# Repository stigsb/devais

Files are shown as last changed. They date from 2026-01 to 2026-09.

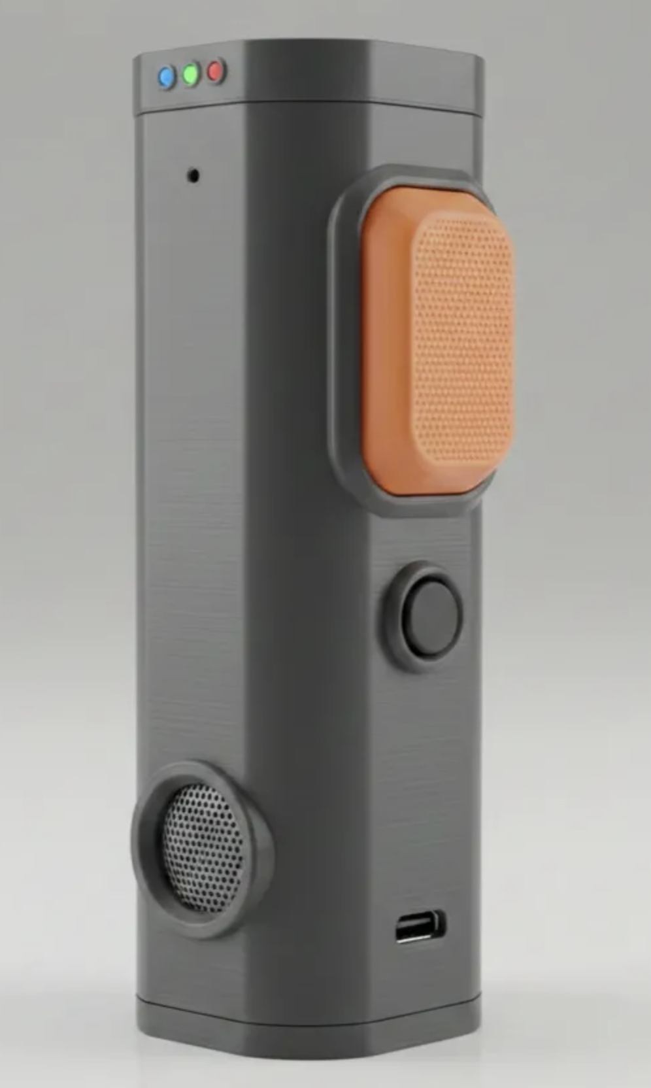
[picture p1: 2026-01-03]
context/proto-image.png

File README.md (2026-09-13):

# Devais - Handheld AI Assistant Device

A battery-powered, pocket-sized AI assistant with a push-to-talk interface. Designed as a walkie-talkie style device that solves the common problem of AI apps responding to hesitation during speech.

## Overview

**Form Factor:** Stick-shaped handheld device (~30x30x150mm)  
**Power:** 18650 battery with USB-C charging  
**Interface:** Push-to-talk button, status LEDs, speaker and microphone  
**Connectivity:** Bluetooth Low Energy (nRF52840)

## Hardware Components

### Core Controller
- **Seeed XIAO nRF52840** - Ultra-low power microcontroller with BLE
  - Superior battery efficiency vs ESP32 alternatives
  - 20.8 days idle battery life (vs 8.3 days for ESP32-C3)
  - 5 days continuous audio streaming (vs 27 hours for ESP32-C3)

### Audio System (I2S Bus Architecture)
- **INMP441** - MEMS I2S microphone
- **MAX98357A** - I2S Class D amplifier
- Compact speaker
- Shared clock signals with separate data lines for efficiency

### User Interface
- Tactile push-to-talk button
- Power/mode button
- Status LEDs (power, connectivity, activity)

### Power
- 18650 Li-ion battery
- USB-C charging port
- Efficient power management optimized for audio streaming

## Project Structure

```
devais/
├── cad/              # 3D CAD models (CadQuery scripts)
├── firmware/         # nRF52840 firmware
├── docs/             # Documentation, wiring diagrams
├── hardware/         # PCB designs, schematics
└── README.md
```

## Getting Started

### Prerequisites
- Python 3.14
- uv (Python package manager)
- Prusa MK3S or compatible 3D printer

### Installation

```bash
# Clone the repository
git clone https://github.com/stigsb/devais.git
cd devais

# Install dependencies with uv
uv sync

# Activate virtual environment
source .venv/bin/activate  # Linux/Mac
# or
.venv\Scripts\activate     # Windows
```

### Running CAD Scripts

```bash
# Generate the enclosure model
python cad/enclosure.py

# Output will be in cad/output/ as STL files
```

## Design Principles

1. **Intentional Interaction** - Push-to-talk prevents accidental triggers and hesitation issues
2. **Battery Efficiency** - Component selection optimized for multi-day battery life
3. **Pocket Portability** - Narrow form factor fits comfortably in pocket or hand
4. **Programmatic CAD** - Python-based modeling enables iterative design and parameter adjustment

## Status

- [x] Component selection and power analysis
- [x] I2S audio architecture design
- [x] Wiring diagram and pin assignments
- [ ] 3D enclosure design (in progress)
- [ ] PCB layout
- [ ] Firmware development
- [ ] Prototype assembly

## Location

Trondheim, Norway

## License

TBD

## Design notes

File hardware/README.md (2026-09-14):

# Devais Hardware Design

> The Python circuit-synth files below are historical circuit sketches.
> See [the electrical design](pcb/DESIGN.md) (revision 2, 2026-09-13) for the
> current circuit and [the parts list](BOM.md) for every part, lead and tool.
> [PROTOTYPE.md](PROTOTYPE.md) covers the stripboard bench build and the field
> unit on the XIAO nRF52840 Sense that precede the custom PCB.
> Neither these sketches nor the old tscircuit source are a fabrication-ready board.

Circuit definitions for Devais handheld AI assistant device using circuit-synth.

## Circuit Structure

The hardware design is modular, following software engineering best practices:

```
hardware/
├── devais.py              # Main circuit (composition of all subsystems)
├── power_management.py    # USB-C, battery, voltage regulation
├── audio.py              # I2S microphone and amplifier
├── user_interface.py     # Buttons and LEDs
└── README.md            # This file
```

## Components Overview

### Power System
- **USB-C connector** with 5.1k CC resistors (power sink configuration)
- **TP4056** Li-ion battery charger (1A charge current)
- **18650 battery** with protection
- **AMS1117-3.3** LDO regulator for 3.3V supply
- **Schottky diodes** for automatic USB/battery power selection

### Audio System (I2S Bus)
- **INMP441** MEMS I2S microphone
- **MAX98357A** Class D I2S amplifier (9dB gain for battery efficiency)
- **Speaker** (20-28mm diameter)
- Shared SCK and WS clock signals (efficient architecture)

### User Interface
- Push-to-talk button (with interrupt on P0.02)
- Power/mode button (with interrupt on P0.03)
- 2x **WS2812B-2020** addressable RGB LEDs (2x2mm package) on small PCB
  - Single data pin, daisy-chained
  - VDD switched via N-channel MOSFET to cut idle draw when LEDs are off

### Microcontroller
- **Seeed XIAO nRF52840** module
- BLE connectivity
- I2S peripheral for audio
- SWD programming interface (10-pin header)

## Pin Assignments (nRF52840)

| Function | Pin | Description |
|---|-----|---|
| **I2S Audio** | | |
| I2S SCK | P0.26 | Bit clock (shared mic/amp) |
| I2S WS | P0.27 | Word select (shared mic/amp) |
| I2S SDI | P0.28 | Serial data in (from mic) |
| I2S SDO | P0.29 | Serial data out (to amp) |
| **User Interface** | | |
| PTT Button | P0.02 | Push-to-talk (interrupt) |
| Power Button | P0.03 | Power/mode (interrupt) |
| LED Data | P0.06 | WS2812B-2020 data (2 LEDs daisy-chained) |
| LED Power | P0.07 | MOSFET gate for LED VDD cutoff |

## Generating KiCad Files

```bash
# From the hardware/ directory
cd /Users/stig/git/stigsb/devais/hardware

# Activate virtual environment
source ../.venv/bin/activate

# Generate KiCad project
python devais.py
```

This creates:
- `devais_v1/devais_v1.kicad_pro` - KiCad project file
- `devais_v1/devais_v1.kicad_sch` - Schematic file
- `devais_v1/devais_v1.kicad_pcb` - PCB layout file
- `devais_v1/devais_v1.net` - Netlist

## Opening in KiCad

```bash
open devais_v1/devais_v1.kicad_pro
```

## Making Changes

### Modify Circuit
1. Edit the Python files (`devais.py`, `audio.py`, etc.)
2. Run `python devais.py` to regenerate KiCad files
3. Circuit-synth will update component references in your Python source

### Modify PCB Layout
1. Open in KiCad and make changes to PCB layout
2. Changes to layout are preserved (not overwritten by circuit-synth)
3. If you change schematic in KiCad, you can import it back to Python

## Generating Manufacturing Files

```python
from devais import devais_main

circuit = devais_main()

# Generate BOM
circuit.generate_bom("devais_v1")

# Generate PDF schematic
circuit.generate_pdf_schematic("devais_v1")

# Generate Gerber files
circuit.generate_gerbers("devais_v1")
```

## Component Sourcing

Many components may need custom KiCad symbols/footprints. You can use circuit-synth's component search:

```bash
# Search for components
/find-parts "INMP441" --source jlcpcb
/find-parts "MAX98357A" --source jlcpcb
/find-symbol "nRF52840"

# Check JLCPCB availability
jlc-fast search "TP4056"
```

## Known Issues / TODOs

1. **Custom symbols needed:**
   - INMP441 microphone (might use generic breakout symbol)
   - MAX98357A amplifier (might use generic breakout symbol)
   - Seeed XIAO nRF52840 module (needs custom symbol)

2. **Footprint selection:**
   - Most footprints specified are standard
   - Audio module footprints may need adjustment for actual breakout boards

3. **Power management refinement:**
   - Consider load switch for power button control
   - Battery protection circuit details
   - USB-C ESD protection

4. **Audio tuning:**
   - Speaker impedance matching
   - Amplifier gain optimization
   - Acoustic design considerations

## Design Rationale

This circuit implements the design decisions documented in `../CLAUDE.md`:

- **Battery efficiency:** nRF52840 chosen over ESP32 for 2.5x better battery life
- **I2S audio:** Shared clock architecture reduces GPIO usage and improves efficiency
- **Modular design:** Each subsystem is independently testable and reusable
- **Version controlled:** All circuit changes tracked in git with meaningful diffs

## Next Steps

1. Generate KiCad project (`python devais.py`)
2. Verify component availability and adjust footprints
3. Create/import custom symbols for XIAO nRF52840, INMP441, MAX98357A
4. PCB layout (considering 30x30mm target size)
5. Review with electrical rules check (ERC)
6. Order prototype PCB and components
7. Assembly and testing

## Questions?

See the main project README and CLAUDE.md for project context and design philosophy.

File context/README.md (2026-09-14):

# Context Files for AI Agents

## Index

Full assembly prototype: see `cad/ASSEMBLY.md` for the PCB, components, harnesses,
mounting pieces and fit checks. Its exports are in `output/full-assembly/`.

Latest enclosure revision (2026-09-11): diagonal pin/socket joint and chassis mounts;
see `output/README.md`. `context/enclosure-spec.md` marks its older content as
historical; `context/enclosure-work.md` was rewritten to the current state. Root
`output/` is the current export destination.

**When working on this project, read these files in `context/` for technical details:**

**Additional Documentation:** The `docs/` folder contains supplementary documentation.

### `context/enclosure-spec.md`
**Read when:** Implementing or modifying the DevAIs enclosure design.

**Contains:**
- Reference image analysis with precise dimensions and component positions
- Complete implementation plan with step-by-step changes required
- Octagon geometry calculations and battery fit verification
- CadQuery coordinate system guidelines and workplane selection rules
- Component orientation details (USB-C, buttons, LEDs, microphone, speaker)

### `context/enclosure-work.md`
**Read when:** Resuming work on the enclosure or checking its current parameters.

**Contains:**
- Octagon geometry and the seam position
- Every opening with its size and position, and the internal mount envelopes
- Commands to generate and preview, and what the generator checks
- Outstanding work
- CadQuery techniques the model depends on, and the decisions behind them

### `context/software-decisions.md`
**Read when:** Implementing firmware, the phone companion, or the BLE
transport, or checking which prototype microphone option is in use.

**Contains:**
- Firmware framework and host platform decisions
- The staged BLE transport and codec plan, with the options rejected and why
- The throughput and link-budget constraints and estimates behind that plan
- The prototype microphone decision

## Index Updates

This file must be updated when `context/*.md` files are added, modified or deleted.

Entries should follow this template:

```markdown
### `context/lowercased-name.md`
**Read when:** (single sentence describing when to read)

**Contains:**
- Short list of the
- kinds of information
- the file contains
```

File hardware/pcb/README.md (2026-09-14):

# Devais Main PCB

> **Current design (2026-09-13, revision 2):** see [DESIGN.md](DESIGN.md) for the
> 26 × 126 mm chassis-mounted board, castellated radio module, and JST-connected
> peripherals, and [../BOM.md](../BOM.md) for the parts list. `design.py` checks
> the mechanical allocations. The electrical
> source below remains an older, incompatible sketch with placeholder footprints
> and known circuit errors. It is not suitable for manufacture. The historical
> dimensions and component descriptions below do not describe the new proposal.

Custom PCB for the Devais handheld AI assistant, designed with [tscircuit](https://tscircuit.com/) (React/TypeScript).

## Board Specifications

- **Dimensions:** 28 x 72mm (2-layer, all components top-side)
- **Width constraint:** 28mm max inscribed square inside the 35mm interior octagonal enclosure
- **Height:** 72mm, sits above the 18650 battery (65mm) in the 150mm tall enclosure
- **Mounting:** 4x M2 holes at corners

## Architecture

The design splits functionality across multiple small boards connected by JST cables. This keeps the USB-C board cheap and replaceable (it takes mechanical stress from cable insertion), and puts the LED board where it needs to be physically (near the top of the enclosure, away from the main PCB).

### Main PCB (this board)

All processing, power management, and audio amplification.

| Ref | Component | Package | Function |
|-----|---|---|---|
| U_MCU | Seeed XIAO nRF52840 | DIP14 castellated | BLE microcontroller |
| U_AMP | MAX98357A | QFN-16 (3x3mm) | I2S Class D amplifier |
| U_REG | AMS1117-3.3 | SOT-223 | 3.3V LDO regulator |
| U_CHG | TP4056 | SOIC-8 | Li-ion battery charger (1A) |
| Q1 | 2N7002 | SOT-23 | N-ch MOSFET, LED VDD switch |
| SW_PTT | Tactile switch | 6x6mm | Push-to-talk button |
| SW_PWR | Tactile switch | 6x6mm | Power/mode button |

### External Boards (JST cables)

| Connector | Pins | Connects To |
|---|---|---|
| J_USB | 2 (VBUS, GND) | USB-C charging board |
| J_BAT | 2 (VBAT, GND) | 18650 battery holder |
| J_SPK | 2 (OUT+, OUT-) | Speaker (differential from MAX98357A) |
| J_LED | 3 (VDD_LED, GND, DATA) | WS2812B-2020 daughter PCB (2 LEDs) |
| J_MIC | 5 (VCC, GND, WS, SCK, SD) | INMP441 breakout board |

### USB-C Board (separate, replaceable)

Intentionally minimal: USB-C receptacle + 2x 5.1k CC resistors. No ICs. Designed to be cheap to replace when the connector wears out or breaks from mechanical stress.

## Pin Mapping (nRF52840 via XIAO)

| XIAO Pin | nRF52840 | Signal | Description |
|---|---|---|---|
| D2 | P0.28 | I2S_SDI | Mic data → MCU |
| D3 | P0.29 | I2S_SDO | MCU → amp data |
| D4 | P0.02 | BTN_PTT | Push-to-talk (interrupt) |
| D5 | P0.03 | BTN_PWR | Power/mode (interrupt) |
| D6 | P0.26 | I2S_SCK | Shared bit clock |
| D7 | P0.27 | I2S_WS | Shared word select |
| D8 | P0.06 | LED_DATA | WS2812B data (daisy-chained) |
| D9 | P0.07 | LED_EN | MOSFET gate for LED VDD |

## PCB Layout (top to bottom)

```
Y=+33  ┌─ J_SPK (speaker)  J_LED (LEDs) ─┐
Y=+29  │  Q1 (MOSFET)      R_GATE         │
Y=+18  │         U_MCU (XIAO)             │
Y= +4  │  J_MIC (mic)      U_AMP (amp)    │
Y= -7  │       SW_PTT (push-to-talk)      │
Y=-16  │       SW_PWR (power/mode)        │
Y=-24  │         U_REG (3.3V LDO)         │
Y=-31  │  R_PROG  C_USB    U_CHG (charger)│
Y=-35  └─ J_USB (USB pwr)  J_BAT (battery)┘
```

## Build Commands

```bash
uv run pcb-build          # Validate circuit (runs tsci build)
uv run pcb-export         # Build + export SVG/schematic/assembly/netlist
```

Or directly with tsci:

```bash
cd hardware/pcb
tsci build                             # Validate
tsci export index.circuit.tsx -f pcb-svg        # PCB layout
tsci export index.circuit.tsx -f schematic-svg  # Schematic
tsci export index.circuit.tsx -f assembly-svg   # Assembly drawing
tsci dev                               # Interactive preview
```

Assembly diagram with accurate pad outlines:

```bash
uv run python3 hardware/pcb/generate_assembly.py
open hardware/pcb/assembly-top.png
```

## Design Decisions and Lessons Learned

### Tool Selection

We evaluated several PCB design tools for AI coding agent workflows:

| Tool | Verdict | Why |
|---|---|-----|
| **circuit-synth** | Rejected | Requires KiCad installed for symbol libraries |
| **pcbflow** | Rejected | Alpha quality, not on PyPI, limited footprints, no schematic |
| **tscircuit** | Selected | Declarative JSX, built-in autorouter, JLCPCB search, no external deps |

**Key insight:** tscircuit's declarative React/JSX approach is far better for AI-driven iteration than imperative Python turtle routing. `tsci build` gives instant headless validation.

### Board Sizing

The board width (28mm) is fixed by the enclosure geometry: it's the maximum inscribed square inside the 35mm flat-to-flat interior octagon. We calculate this from the octagon's chamfer line: `x + y ≤ 28.4mm`, so a square board maxes out at 28mm.

The height evolved through iteration:
- 28mm (square): too dense, autorouter failed
- 55mm: courtyard overlaps in power section
- 90mm: too much empty space
- **72mm: good balance** — compact but every component has clearance

### Courtyard Overlaps

**Never ignore courtyard overlap warnings.** They mean components physically can't be soldered in those positions. Even if pads don't technically overlap, courtyard violations indicate insufficient clearance for:
- Soldering iron access
- Pick-and-place machine tolerances
- Rework and inspection

The DIP14 footprint for the XIAO nRF52840 is surprisingly large (7.6 x 15.2mm). This was the most common source of courtyard violations — components placed "above" or "below" the MCU would overlap its tall pad span.

### Autorouter Selection

- `auto` (capacity-mesh): fails on dense boards ("ran out of iterations")
- `auto-cloud`: requires tscircuit authentication, hung indefinitely
- **`sequential-trace`**: works reliably even on dense boards

### Component Placement Strategy

1. **Know your footprint sizes.** DIP14 is 15mm tall. SOT-223 is 6.3mm wide. SOIC-16 is 9mm tall. You need these numbers to calculate safe placement gaps.
2. **Verify with `tsci build` after every position change.** Don't batch up changes — you'll lose track of which move caused the overlap.
3. **Place largest components first** (MCU, then connectors, then ICs, then passives).
4. **Keep decoupling caps near their IC** but not so close that courtyards overlap. 3-4mm center-to-center is usually safe for 0603/0805 next to SOT-23 or larger.

### Modular Board Architecture

Splitting into main board + daughter boards was driven by practical concerns:
- **USB-C board:** Mechanical stress from cable insertion will eventually break the connector. A separate $0.50 board with just the connector + CC resistors is disposable.
- **LED board:** The WS2812B LEDs need to be physically at the top of the enclosure (behind the LED holes), far from where the main PCB sits. A 3-wire JST cable solves this.
- **Mic breakout:** INMP441 is a bottom-port MEMS mic requiring an acoustic path through the enclosure wall. Easier to position independently on a breakout board.

### LED VDD Switching

The N-channel MOSFET (2N7002) switches LED ground, not VDD. This is simpler than a high-side P-channel switch:
- Gate driven directly from 3.3V GPIO (D9)
- 10k pull-down resistor keeps LEDs off during MCU boot/reset
- WS2812B idle current (~1mA per LED) is eliminated when MOSFET is off

### JLCPCB Part Numbers

All ICs and passives have JLCPCB `supplierPartNumbers` for direct ordering. Use `tsci search --jlcpcb "<query>"` to verify stock before ordering.

## File Structure

```
hardware/pcb/
├── index.circuit.tsx       # Main circuit definition (source of truth)
├── generate_assembly.py    # Assembly diagram generator (reads circuit.json)
├── assembly-top.svg/.png   # Generated assembly drawing
├── index.circuit-pcb.svg   # Generated PCB layout
├── index.circuit-schematic.svg
├── index.circuit-assembly.svg
├── dist/index/circuit.json # Build output (component positions, nets, pads)
├── package.json            # tscircuit project config
├── tsconfig.json
├── tscircuit.config.json
└── README.md               # This file
```

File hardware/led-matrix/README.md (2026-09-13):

# LED matrix daughterboard

**Status: deferred to V2.** V1 ships the existing two 3 mm LED openings. Nothing
here is on the V1 build path.

A higher-fidelity replacement for the 2x WS2812B-2020 indicator board, for
signalling the state of several concurrent agents. Background, part selection,
cost and the rejected alternatives are in
[`docs/led-indicator-research-2026-09-13.md`](../../docs/led-indicator-research-2026-09-13.md).

## upstream/

Third-party KiCad 7 design, taken as a starting point — not a devais board.

- Source: Arduino Forum, "Showcase: PCB for 8x8 matrix of WB2812B-2020"
  <https://forum.arduino.cc/t/showcase-pcb-for-8x8-matrix-of-wb2812b-2020/1154180>
- Licence: not stated by the author. Resolve before publishing a derived board.
- As drawn: 25.0 x 25.0 mm, 2 layers, 8x8 on a 3.0 mm pitch (21 mm LED field),
  64x `MR_LED:WS2812B2020`, 2x `MR_Connect:DS1024-1x3R0` 3-pin daisy-chain
  connectors, no decoupling capacitors.

## Required changes for devais

- **LED part:** WS2812B-2020-V6 (LCSC C52917434), not the V1.3 part the upstream
  footprint was drawn for. V6 is spec'd 3.3-5.3 V and <=1 uA idle, so it runs
  directly off the 18650 with no boost and needs no power gate. Verify the V6
  recommended land pattern against the upstream footprint before reuse.
- **Connector:** one 3-pin JST matching the existing J_LED cable (VDD_LED, GND,
  LED_DATA), replacing both DS1024 daisy-chain connectors.
- **Decoupling:** upstream has none. Add local capacitors.
- **Outline:** 25 mm is the enclosure's hard limit at the front flat face
  (`LONG_SIDE_LENGTH` ~= 24.9 mm). Shrinking the pitch to 2.5 mm gives a 20 mm
  field and working margin.

## Open questions

- Front-face split: the enclosure parts at X = 0 and the current LED openings sit
  entirely on the chassis half. A centred 25 mm board crosses the joint.
- Diffusion: at 2.5-3.0 mm pitch behind the 1.6 mm wall, per-pixel separation
  needs a grid insert. A plain window blends adjacent pixels into a blur.
- Brightness cap: 64 LEDs at full white is ~2.3 A. Firmware must limit global
  brightness.

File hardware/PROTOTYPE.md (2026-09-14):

# Devais prototype builds — 13 September 2026

Two builds precede the custom PCB in [`pcb/DESIGN.md`](pcb/DESIGN.md):

1. **Bench prototype**: stripboard, breakout modules, no enclosure. Proves
   push-to-talk capture, BLE transfer to the phone, playback, LEDs and idle
   current.
2. **Field unit**: the same electronics on a stripboard carrier inside the
   printed chassis. Cell replaced by opening the cover. No charging port and
   no power button are required; the PTT button, speaker, microphone and
   LEDs must work.

The custom PCB design is unchanged by either build and stays the plan for the
25-unit run. Pin names below are XIAO silkscreen names; nRF port numbers, peripheral
pins and module dimensions were verified against the Seeed wiki, schematic
and Arduino variant files on 2026-09-13
(`docs/research/2026-09-13-xiao-sense.md`).

## Parts for the bench prototype

| Item | Part | Qty | Source | Note |
|---|---|---|---|---|
| Controller | Seeed XIAO nRF52840 Sense | 1 (+1) | digikey.no kr 185 incl. VAT, 1,300 in stock; no Norwegian shop stocks it | USB-C, UF2 bootloader preinstalled, 3.3 V regulator, 100 mA charger, PDM microphone and IMU on board |
| Amplifier | MAX98357A I2S breakout (Adafruit 3006 or generic clone) | 1 | Adafruit, DigiKey, AliExpress | Pins VIN, GND, SD, GAIN, DIN, BCLK, LRC, speaker terminals |
| Speaker | Same Sky CMS-2053-18SP, 20 mm, 8 Ω, 1.5 W | 1 | DigiKey 22521372 | Any 8 Ω speaker works on the bench |
| Cell | Protected 18650 (any brand, 67–70 mm) | 1 | batterionline.no | Protected cell replaces the DW01A circuit. The unprotected 35E is for the PCB build |
| Cell holder | 18650 holder with wire leads | 1 | DigiKey (Keystone 1043, 36-1043-ND, PCB pins; or a leaded holder) | Kjell and Clas Ohlson stock no single-cell 18650 holder |
| Switches | Omron B3F-1000 or any 6 × 6 or 12 × 12 tactile switch | 2 | LCSC C93157, DigiKey | PTT and reset |
| LEDs | 3 mm common-anode RGB LED, diffused | 1 | DigiKey | Plus the XIAO's on-board RGB LED as the second indicator |
| Resistors | 1 kΩ (red), 560 Ω (green, blue), 10 kΩ (pull-up) | 3 + 1 | any | 1/4 W through-hole |
| Capacitors | 100 nF ceramic, 100 µF electrolytic | 1 + 1 | any | Button filter; amplifier supply bulk |
| Stripboard | 0.1 in pitch, at least 25 × 140 mm usable | 1 | DigiKey, Mouser, Farnell | Strips run across the short axis; see cutting rules |
| Headers | 2.54 mm male pin headers, 7-pin × 2 for the XIAO; female headers for the amp if it is to be removable | | DigiKey | |
| Wire | 0.25 mm² (24 AWG) stranded, red and black for power; 0.14 mm² (26 AWG) for signals | | DigiKey, Farnell | |
| Tools | 0.6 mm chisel-tip iron, side cutters, 3 mm drill or strip cutter for cutting strips, multimeter | | | |

## Bench wiring

Power: cell + to the XIAO's BAT+ pad on the underside, cell − to BAT−. The
XIAO's 3V3 pin supplies the LEDs and the PTT pull-up. The amplifier VIN
takes the cell voltage from the holder leads, not 3V3, with the 100 µF
capacitor across VIN and GND at the amplifier. A grounded USB cable into
the XIAO charges the cell at 100 mA (over 30 hours for 3350 mAh) and gives
USB DFU and serial. The XIAO's HICHG pin selects 100 mA when driven low.

| XIAO pin | nRF port | Signal | Connection |
|---|---|---|---|
| D0 | P0.02 | BTN_PTT | Switch to GND; 10 kΩ to 3V3; 100 nF to GND |
| D1 | P0.03 | LED_R | 1 kΩ to the RGB LED red cathode |
| D2 | P0.28 | LED_G | 560 Ω to green cathode |
| D3 | P0.29 | LED_B | 560 Ω to blue cathode; LED anode to 3V3 |
| D4 | P0.04 | I2S_BCLK | Amplifier BCLK (about 1 MHz; D4 and D5 are the only full-speed pads) |
| D5 | P0.05 | I2S_DIN | Amplifier DIN |
| D6 | P1.11 | spare (PDM_CLK in field option M2) | |
| D7 | P1.12 | spare (PDM_DATA in field option M2) | |
| D8 | P1.13 | I2S_LRCLK | Amplifier LRC, 16 kHz |
| D9 | P1.14 | AMP_SD | Amplifier SD pin through 100 kΩ (mono mix window); low = shutdown |
| D10 | P1.15 | spare | |
| RST (underside pad) | | Reset switch | Second switch to GND; double-tap enters the UF2 bootloader |
| BAT+, BAT− (underside pads) | | Cell | Through the holder leads |
| on-board mic MSM261D3526H1CPM | CLK P1.00, DATA P0.16, power P1.10 | PDM capture | No wiring |
| on-board RGB LED | red P0.26, green P0.30, blue P0.06, common anode to 3V3, active low | Second indicator | No wiring |
| HICHG | P0.13 | Charge current | Drive low for 100 mA; floating gives 50 mA |
| VBAT sense | P0.31 / AIN7, divider enabled by P0.14 low | Cell voltage | Keep P0.14 low only while sampling |

The amplifier GAIN pin is left open for 9 dB. Nine of the eleven exposed
pins are Nordic "low frequency" pads (D0–D3, D6–D10); only D4 and D5 are
full-speed, so they carry the bit clock and data. Seeed's own SPI runs on
D8–D10 at several MHz, so a 16 kHz LRCLK on D8 is not a concern. The custom
PCB uses full-speed pads throughout.

Stripboard rules: the XIAO is 20.96 × 17.78 mm, 4.46 mm thick with its USB-C
receptacle, which overhangs the board edge by 1.5 mm. Its two pin rows are
17.78 mm apart on 2.54 mm pitch and lie on the same strips, so cut every
strip between the rows under the module. Mount the
XIAO on male headers so the underside pads (BAT+, BAT−, RST, SWD) are
reachable: solder the cell and reset leads to those pads before fitting the
headers. Keep the speaker pair twisted and away from the cell leads.

## Firmware for the prototype

- Bootloader: the factory Adafruit UF2 bootloader (board `Seeed XIAO nRF52840
  Sense`). USB DFU by double-tap reset or the 1200-baud touch. No SWD needed.
- Framework: nRF Connect SDK (Zephyr) with the `xiao_ble/nrf52840/sense`
  board, which has the PDM mic and I2S drivers; or the Seeed Arduino core
  with the `PDM` and `I2S` libraries for a faster start. Pick one and keep
  it for the custom board, which will need its own board definition.
- Audio: 16 kHz mono capture from PDM, transfer over BLE (a GATT
  characteristic with notifications, or NUS), playback over I2S at the same
  rate with the sample duplicated into both slots.
- Sleep: System OFF with PTT wake, amplifier SD low, PDM clock stopped.
  Measure the cell current with the LEDs off; this number decides whether
  the product needs the power button at all.

## Field unit

The bench electronics move onto a 25.4 × 135 × 1.6 mm stripboard cut to the
main-board outline, screwed to the existing rails with the existing six M2
positions (drill the stripboard to match `stripboard_template.step`). Beside
the cell the carrier may carry only flat parts (3 mm limit): wires, resistors
lying flat, the capacitors laid down. Modules sit above the cell:

| Part | Position | Mounting |
|---|---|---|
| XIAO nRF52840 Sense | Top of the carrier, Z 125.8–146.8, USB-C mouth at the top end wall; the chip antenna and the on-board mic are at the opposite (lower) end on the top face | Soldered flat by its castellations at Z 125.8–146.8; USB-C through a 7.5 × 13 mm opening in the top wall; BAT+/BAT− leads soldered from behind through an 8 × 12 mm stripboard window |
| MAX98357A breakout | Above the cell, Z 92–111.4 | Z 92–111.4 on one 7-pin header row at Y = 6.1, header pins clipped to 1.5 mm behind the board |
| Speaker | Existing cup, existing bridge | Unchanged |
| PTT switch | Existing carrier at Z = 105 | Unchanged; the lead is routed behind the amplifier pins at X 15. The PTT tunnel leaves only a 0.14 mm skin on the PCB rail's back face, which will not print, so the lead lies in a groove open toward the wall with a 2.1 mm gap. |
| Reset switch | Existing power-button carrier at Z = 44 | Not fitted; the power carrier and cap stay as blanks |
| RGB LED | Through both existing 3.2 mm holes at Z = 140, leads soldered to a 5-wire lead | One RGB LED and one single-colour LED on D10 on the product LED board, 5-wire lead |
| Cell | Existing cradle, Keystone contacts, straps | Cover off to swap; the straps hold it |
| USB-C side opening | Not cut in the field chassis | None needed |

Microphone: M2, an Adafruit 3492 PDM breakout (14.0 × 12.8 × 2.8 mm) in the
enlarged bottom-front seat, MP34DT01 port toward the wall, wired to D6/D7.
Decided 2026-09-14.

The field variant is built with `--variant field` in `cad/enclosure.py` and
`cad/assembly.py`; see `cad/ASSEMBLY.md`.

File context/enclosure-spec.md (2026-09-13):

> Update 2026-09-11: The implementation now uses an offset diagonal split
> (X−Y = −4), locating pins with blind sockets, screw closure, and chassis-only
> component supports. Generated files are in root `output/`. See
> `output/README.md` for dimensions, checks and unfinished hardware details.
> Historical completion claims and X=0 joint descriptions below are superseded.

# 1. Reference Image Analysis - DevAIs Enclosure

## 1.1. Overall Form ✅ REVIEWED

### 1.1.1. Cross-Section (Octagonal Prism)
- **NOT cylindrical** - octagonal cross-section
- **Dimensions:** 40mm across × 150mm tall
- **Octagon structure:**
  - Formed like a **square with chamfered/beveled corners at 45°**
  - 4 longer sides (the main square faces)
  - 4 shorter sides (the 45° chamfers at each corner)
  - Ratio between longer sides and shorter sides/chamfers is 7:3
  - Alternating pattern: long side → short chamfer → long side → short chamfer...
  - Each beveled corner is **slightly rounded** (4mm diameter)

### 1.1.2. Vertical Profile
- **Height:** 150mm
- **Top edge:** rounded/filleted (4mm diameter)
- **Bottom edge:** rounded/filleted (4mm diameter)

### 1.1.3. Visual Effect
- Basically a **square stick with softened/chamfered corners**
- The 45° chamfers make it more comfortable to hold than a pure square
- The rounded edges add to the ergonomic feel

### 1.1.4. Colour
- The main body is industrial grey

### 1.1.5. Thickness
- 1.6mm thickness - practical for following USB-C port spec

---

## 1.2. Components and Features ✅ REVIEWED

### 1.2.1. Names / Designations ✅ REVIEWED
- **Orientation:**
  - The enclosure runs length-wise along the Y axis.
  - The front/back sides are separated along the Z axis.
  - The left/right sides are separated along the X axis.
- **Front:**
  - One of the long sides is designated as the "front" side.
  - The "right" side is the long side to the right of the "front" side when camera points
    perpendicularly at the front side.

### 1.2.2. Top Section of Front Side ✅ REVIEWED

#### 1.2.2.1. Two RGB LEDs
  - 2x WS2812B-2020 addressable RGB LEDs (2x2mm package) on small PCB
  - On front side, 10mm from the top
  - 3mm holes for light diffusion
  - Positions: x=+5mm and x=+11mm (both on right/chassis half)
  - Single data pin, daisy-chained; VDD switched via MOSFET for idle power savings

#### 1.2.2.2. Microphone Hole and Support

Microphone is a INMP441. It should be centered 10mm from the bottom of the front side, behind a 1.5mm acoustic hole.
There needs to be support structure behind the hole, as described in the following technical details the INMP441:

<part_description>
 <part>INMP441</part>
 <type>high-performance, low power, digital-output, omnidirectional MEMS microphone with a bottom port</type>
 <dimensions>
  Overall Size:
  - Length: 4.72mm
  - Width: 3.76mm
  - Height: 1.00mm (0.88-1.05mm tolerance)
 </dimensions>
 <acoustic_port>
  At bottom of the part.
  - Port diameter: 0.25mm (at microphone)
  - Recommended PCB hole: 0.5-1.0mm diameter
  - Port location: Centered on bottom of package
  - Inner ring diameter: 0.96mm
  - Outer ring diameter: 1.56mm
 </acoustic_port>

 <support_structure_design_requirements>
  1. Mounting Footprint:
     - Create a 4.72mm × 3.76mm pocket or platform
     - Consider adding ~0.2mm clearance for 3D print tolerances
  2. Acoustic Port Opening:
     - Must have a through-hole of at least 0.5-1.0mm diameter aligned with the mic center
     - The sound port MUST NOT be blocked - this is critical for functionality
     - Position this hole at the center of the 4.72mm × 3.76mm footprint
  3. Pin Locations (9 pins total):
     - 8 rectangular pads (0.40mm × 0.60mm) around perimeter
     - Spacing: 1.05mm between pins on short sides, 2.66mm on long sides
     - Pin 1 is at the reference corner (see page 19, Figure 16)
  4. Clearance:
     - Leave space below for the acoustic path
     - No obstructions within ~2mm radius of the bottom port
     - Consider ventilation/acoustic chamber design
 </support_structure_design_requirements>
 <design_note>
  The INMP441 is a bottom-ported mic, so your enclosure needs an acoustic path from the outside environment to the bottom of the microphone. The support structure should securely hold the breakout board while ensuring the sound port remains completely unobstructed.
 </design_note>
<part_description>

### 1.2.3. Large Orange Button ✅ REVIEWED
- **Purpose:** This is the press-to-talk button
- **Location:** Upper part of right side of device (from viewing angle), placed 15%-45% of the total height relative to the top (centered at 105mm from bottom)
- **Height:** 30% of enclosure height (45mm)
- **Width:** Same as the width of a long side (~24.9mm)
- **Shape:** Multi-section design with rounded corners:
  - **Base section:** 4mm flat depth without bevel
  - **Beveled section:** 4mm depth with 45° bevel/taper on all four sides
  - **Corner rounding:** Transitions from 8mm radius at the top of the base section to proportionally scaled radius (~5.4mm) at the top of the button, maintaining consistent proportions
- **Texture:** Top surface has a dotted pattern (raised bumps) providing extra friction but still feeling comfortable
  - Bumps are filtered to exclude corners where surface rounding removed their support
  - Only bumps within the rounded rectangle boundary are included
- **Opening in enclosure:** The opening for the button has rounded corners with 8.5mm radius (matching the 8mm button corner radius plus 0.5mm clearance)
  - Opening is cut through the wall from outer surface inward
- **Raised edge on body around button:**
  - **Frame width:** 1.6mm (same as wall thickness)
  - **Height:** 3.2mm (2× wall thickness), extending from inner surface outward
  - **Protrusion:** Extends 1.6mm beyond the outer surface of the enclosure
  - **Inner dimensions:** Match the opening size exactly (8.5mm corner radius)
  - **Rounding:** 0.3mm fillet on outer edges for smooth transition
  - **Alignment:** Positioned to naturally meet the 45° chamfer surfaces
- **Color:** Orange

### 1.2.4. Power Button ✅ REVIEWED
- **Location:** Lower part of right side, 44mm from the bottom
- **Color:** Black
- **Design:** Concentric ring design - has a raised outer ring to prevent accidental power-off
- **Diameter:** 8mm

### 1.2.5. Speaker Grille ✅ REVIEWED
- **Location:** Upper part of front face
- **Shape:** Circular
- **Pattern:** Mesh/perforated with many small holes
- **Color:** Dark gray/black
- **Diameter:** 80% of the long side width
- **Position:** Upper edge of speaker grille should be 10mm below the horizontal line with LEDs

### 1.2.6. USB-C Port ✅ REVIEWED
- **Location:** Lower part of right side, 31mm from the bottom
- **Shape:** Stadium-shaped (rounded rectangle) through-hole with a width of 9.5mm, a height of 3.7mm, and a corner radius of 1.6mm
- **Size:** 9.5mm width × 3.7mm height (standard USB-C dimensions)
- **Orientation:** Flat side (9.5mm width) oriented front-to-back (facing toward/away from power button)
- **Surface thickness:** Ensure the enclosure wall thickness at the point of the cutout is exactly 1.6mm. If the rest of the enclosure is thicker (e.g., 3mm), create a recessed pocket on the exterior or interior so the effective thickness at the port is reduced to 1.6mm."

---

## 1.3. File Output ✅ REVIEWED
- **Output Directory:** All generated STL and STEP files must be written to the `cad/output/` directory.
- **Directory Creation:** The script should automatically ensure this directory exists before exporting.
- **Gitignore:** This directory is gitignored to avoid tracking large binary model files.

---

# 2. Implementation Plan

## 2.1. Critical Changes Required

### 2.1.1. Fundamental Shape Change: Cylinder → Octagonal Prism
**Current:** Code creates a hollow cylinder using `cq.Workplane("XY").circle()`
**Required:** Create octagonal prism with 7:3 ratio for long:short sides

**Implementation approach:**
1. Calculate octagon dimensions from 40mm width
2. Create octagon profile using `.polygon()` or explicit point coordinates
3. Apply small fillets to each edge where sides meet
4. Extrude to 150mm height
5. Add fillets to top and bottom edges
6. Hollow out the interior

**Octagon geometry calculations:**
- 40mm across (corner to opposite corner? or flat to flat?)
- 7:3 ratio means if long side = 7 units, short chamfer = 3 units
- Need to verify: is 40mm the flat-to-flat or point-to-point measurement?

### 2.1.2. Dimension Corrections
**Current:** 55mm × 55mm × 150mm
**Required:** 40mm × 40mm × 150mm octagonal prism

### 2.1.3. Coordinate System Alignment
**Required:**
- Y axis: length (150mm)
- Z axis: front/back separation
- X axis: left/right separation

**Current code:** Uses Z for height, XY for cross-section
**Action:** May need to rotate final model or reorient coordinate system in code

### 2.1.4. Component Repositioning

| Component | Current Position | Required Position | Change Needed |
|---|---|---|---|
| LEDs (3x 3mm) | Not implemented (commented out) | Front side, 10mm from top, 8mm spacing | Add function |
| Mic (INMP441) | Front, 92% height (~138mm) | Front, 10mm from bottom | Move to bottom + add mounting structure |
| Speaker Grille | Front, 28% (~42mm) | Front, upper part, 10mm below LEDs | Move to top |
| Power Button | Front, 40% (~60mm) | RIGHT side, 44mm from bottom | Change side + reposition |
| USB-C Port | Bottom/front, 5mm | RIGHT side, 31mm from bottom | Change side + reposition |
| Large Button | Right side, 60% (~90mm) | RIGHT side, centered, 30% height (45mm tall) | Adjust height and add bevel |

### 2.1.5. Large Button Redesign
**Current:** Simple rounded rectangle with dimple texture
**Required:**
- Full width of long side (~28mm based on 7:3 ratio)
- 30% of device height = 45mm tall
- 45° bevel/taper (base larger than top surface)
- 4mm protrusion from body surface
- 2mm raised edge on body around button (quarter-circle profile, 0.25mm gap)
- Dotted texture on top surface

### 2.1.6. Power Button Design
**Current:** Simple circular cutout
**Required:**
- 8mm diameter
- Concentric ring design with raised outer ring
- Black color (material/print consideration)
- On RIGHT side, 25mm from bottom

### 2.1.7. INMP441 Microphone Mounting
**Required:** Add internal support structure:
- 4.72mm × 3.76mm mounting footprint
- 1.5mm acoustic hole centered on front face, 10mm from bottom
- 0.5-1.0mm through-hole for acoustic port
- No obstructions within 2mm radius of port
- Acoustic chamber design

### 2.1.8. Speaker Grille Repositioning
**Current:** Lower portion, 28% height
**Required:** Upper portion of front face
- Diameter: 80% of long side width (~22.4mm if long side is 28mm)
- Position: Upper edge 10mm below LED line (LED line is 10mm from top)
- So grille upper edge at 20mm from top

### 2.1.9. LED Holes
**Current:** Function exists but not called
**Required:** Re-enable and position correctly
- Front side, 10mm from top
- 3mm LEDs
- 8mm spacing between centers
- Centered horizontally on front face

## 2.2. Implementation Steps

### 2.2.1. Step 1: Calculate Octagon Geometry
- Determine if 40mm is flat-to-flat or corner-to-corner
- Calculate long side and short chamfer lengths with 7:3 ratio
- Calculate corner positions for octagon profile

### 2.2.2. Step 2: Rewrite `create_basic_enclosure()`
- Replace cylinder with octagonal prism
- Maintain top/bottom edge fillets
- Maintain interior hollowing with appropriate wall thickness

### 2.2.3. Step 3: Update Design Parameters
- Change DEVICE_WIDTH/DEPTH to reflect 40mm octagon
- Calculate long side width for component sizing
- Update all component positions to match reference

### 2.2.4. Step 4: Rewrite Component Functions
- `add_led_holes()`: Position on front, 10mm from top
- `add_mic_hole()`: Move to front bottom, 10mm from bottom, add mounting structure
- `add_speaker_grille()`: Reposition to front top, resize to 80% of long side
- `add_button_cutout()`: Rename to `add_power_button()`, move to right side
- `add_usbc_port()`: Move to right side, 12mm from bottom

### 2.2.5. Step 5: Redesign Large Button
- Add 45° taper/bevel
- Resize to full width of long side × 45mm height
- Add 2mm raised edge feature on body
- Update texture pattern

### 2.2.6. Step 6: Add INMP441 Mounting Structure
- Create internal mounting pocket
- Add acoustic path through enclosure
- Ensure 1.5mm front hole aligns with internal port

### 2.2.7. Step 7: Remove/Update Battery Compartment
- Verify 18650 (18.6mm diameter) fits in 40mm octagon
- May need to reconsider battery placement or use different battery

### 2.2.8. Step 8: Test and Iterate
- Generate model
- Verify all dimensions match reference
- Check component clearances
- Validate acoustic paths
- Ensure printability

## 2.3. Files to Modify
- `/Users/stig/git/stigsb/devais/cad/enclosure.py` - Complete rewrite of geometry

## 2.4. New Files to Create
- None (modifications only)

## 2.5. Risks and Considerations
1. **Battery fit:** 18650 battery (18.6mm diameter) may not fit well in 40mm octagon with wall thickness
2. **Internal space:** Octagon provides less internal volume than 55mm cylinder
3. **Component clearance:** Need to verify XIAO board, speaker, amp, and battery all fit
4. **Printability:** Octagon with small edge fillets should print well, but internal support structures need consideration
5. **Coordinate system:** May cause confusion if not carefully managed

## 2.6. User Responses ✅
1. **40mm dimension:** Flat-to-flat across long parallel sides ✅
2. **Battery:** Keep 18650, can increase enclosure size if needed (length +20%, width +10%) ✅
3. **Raised edge:** Integrated into main body ✅

## 2.7. Octagon Geometry Calculations

Given:
- 40mm flat-to-flat (across opposite long sides)
- 7:3 ratio for long sides : short chamfers
- Octagon formed by chamfering a 40mm square at 45°

Calculations:
- Original square side length (A) = 40mm
- Corner chamfer distance (C) = 40 / 5.3 ≈ 7.55mm
- **Long side length (L) = 40 - 2(7.55) ≈ 24.9mm**
- **Short chamfer length (S) = 7.55√2 ≈ 10.7mm**
- Ratio verification: 24.9 / 10.7 ≈ 2.33 = 7/3 ✓

Component sizing based on long side:
- Large button width: 24.9mm (full long side width)
- Speaker grille diameter: 0.8 × 24.9 ≈ 19.9mm (80% of long side)

## 2.8. Battery Fit Verification

18650 Battery: 18.6mm diameter × 65mm length

Interior space with 2.5mm walls:
- Exterior: 40mm flat-to-flat octagon
- Interior: 40 - 2(2.5) = 35mm flat-to-flat octagon
- Battery needs: 18.6mm diameter

**Result:** ✅ Battery fits comfortably with 16.4mm clearance
**Conclusion:** No size increase needed

---

# 3. CadQuery Implementation Guidelines

## 3.1. Coordinate System (CRITICAL)

**Actual Implementation:**
- The octagon cross-section is in the **XY plane**
- The device height (150mm) is along the **Z axis**
- This differs from the specification which uses Y for length

**Coordinate Mapping:**
```
Spec → Implementation
Y (length, 150mm) → Z axis
Z (front/back) → Y axis
X (left/right) → X axis
```

**Face Positions:**
- **Front face:** Y = +DEVICE_WIDTH/2 (positive Y direction)
- **Right face:** X = +DEVICE_WIDTH/2 (positive X direction)
- **Back face:** Y = -DEVICE_WIDTH/2 (negative Y direction)
- **Left face:** X = -DEVICE_WIDTH/2 (negative X direction)

## 3.2. Workplane Selection for Component Holes (CRITICAL)

**⚠️ Common Mistake:** Creating workplanes at different Z-heights and drilling in the Z direction creates holes that go up/down through the device instead of perpendicular through the octagon faces.

**✅ Correct Approach:**

### 3.2.1. For Front Face Components (LEDs, Speaker, Microphone):
```python
# CORRECT - drill perpendicular to front face
cq.Workplane("XZ")  # Work in XZ plane (front face view)
  .workplane(offset=DEVICE_WIDTH / 2)  # Position at front face (Y = +half)
  .center(x_pos, z_height)  # Position in X and Z
  .circle(radius)
  .extrude(-WALL_THICKNESS - 1)  # Drill in -Y direction (into device)
```

### 3.2.2. For Right Face Components (Power Button, USB-C, Large Button):
```python
# CORRECT - drill perpendicular to right face
cq.Workplane("YZ")  # Work in YZ plane (right face view)
  .workplane(offset=DEVICE_WIDTH / 2)  # Position at right face (X = +half)
  .center(y_pos, z_height)  # Position in Y and Z
  .circle(radius)
  .extrude(-WALL_THICKNESS - 1)  # Drill in -X direction (into device)
```

**❌ Incorrect Approach (DO NOT USE):**
```python
# WRONG - this drills up/down instead of through the face
cq.Workplane("XY")
  .workplane(offset=z_height)  # At a specific height
  .center(x_pos, y_pos)  # On the face
  .circle(radius)
  .extrude(-WALL_THICKNESS - 1)  # Drills in Z direction (WRONG!)
```

## 3.3. Component Orientation Guidelines

### 3.3.1. USB-C Port Orientation
- The port is rectangular: 9mm width × 3.5mm height
- When on the right face (YZ plane):
  - Width (9mm) goes along **Y axis** (front-to-back)
  - Height (3.5mm) goes along **Z axis** (up-down)
- This orients the flat side (wider dimension) toward/away from the device, not vertically
- Use: `.rect(USBC_WIDTH, USBC_HEIGHT)` = `.rect(9, 3.5)` in YZ plane

### 3.3.2. Power Button
- Circular, 8mm diameter
- Concentric ring design (raised outer ring not yet implemented)
- Position: 44mm from bottom (Z = 44)

### 3.3.3. Large Button ✅ IMPLEMENTED
- Rectangular with 45° taper and rounded corners (8mm radius transitioning to ~5.4mm)
- Full width of long side (24.9mm) × 45mm height
- Positioned on right face, 15%-45% from top (centered at 105mm from bottom)
- Opening in enclosure with 8.5mm corner radius
- Raised edge frame (1.6mm wide, 3.2mm tall) with 0.3mm fillet on outer edges

## 3.4. PCB Mounting Bosses ✅ IMPLEMENTED

The PCB (36×140mm, see `hardware/pcb/index.circuit.tsx`) is mounted vertically on the inner right wall of the chassis half using M2 self-tapping screws into short plastic bosses.

### 3.4.1. Coordinate Mapping
- `enclosure_Y = pcb_X` (board width maps to front/back)
- `enclosure_Z = pcb_Y + 75` (board center at Z=75mm)

### 3.4.2. Self-Tapping Screw Bosses
- **10 bosses** matching PCB mounting holes MH1–MH10
- **Boss OD:** 4.5mm (1.45mm wall around 1.6mm pilot hole)
- **Pilot hole:** 1.6mm diameter, drilled through boss and wall for M2 self-tapping
- **Standoff:** 2.0mm from inner wall surface to PCB face
- **Wall overlap:** 0.5mm into wall for solid boolean fusion
- PCB back surface sits 2mm from inner wall — back-side components (USB-C, power button, PTT switch) can reach through wall cutouts

### 3.4.3. Mounting Hole Positions (from PCB)

Holes at pcbX=±10, well within the flat face (±12.45mm half-long-side), avoiding chamfers.

| Hole | pcbX | pcbY | Enc Y | Enc Z | Zone |
|---|---|---|---|---|---|
| MH1  | -10  | -59  | -10 | 16 | USB-C |
| MH2  | +10  | -59  | +10 | 16 | USB-C |
| MH3  | -10  | -37  | -10 | 38 | Mid-lower |
| MH4  | +10  | -37  | +10 | 38 | Mid-lower |
| MH5  | -10  | +22  | -10 | 97 | Mid-upper |
| MH6  | +10  | +22  | +10 | 97 | Mid-upper |
| MH7  | -10  | +40  | -10 | 115 | PTT |
| MH8  | +10  | +40  | +10 | 115 | PTT |
| MH9  | -10  | +67  | -10 | 142 | Top |
| MH10 | +10  | +67  | +10 | 142 | Top |

### 3.4.4. Assembly
- PCB back rests on boss faces (back side toward wall, front side facing interior)
- M2 self-tapping screws go from PCB front through 2.2mm board holes into pilot holes
- Thread engagement: ~3.6mm (2mm boss + 1.6mm wall)

## 3.5. Battery Compartment

- 18650 battery (18.6mm × 65mm) held by half-cylinder cradle ribs on cover (left) half
- 3 ribs at Z positions near bottom, middle, and top of battery zone
- Rib inner radius: 9.5mm (battery radius + 0.2mm clearance), thickness: 1.5mm
- Cover half provides the other 180° containment when snapped on
- Positive contact at top, negative spring at bottom interior of chassis half
- Entire electrical path stays on chassis half — no cross-joint wiring

## 3.6. Split for 3D Printing

The enclosure is split lengthwise at X=0 into right (chassis) and left (cover) halves for FDM printing.

### 3.6.1. Why Split?
- Printing a hollow octagonal tube upright produces excessive internal support material
- Two half-shells print flat on the bed with no supports needed
- All electronics mount on one half (chassis), making assembly and battery replacement easy

### 3.6.2. Split Plane: X=0
- **Right half (X>0) — Chassis:** Large button, power button, USB-C, LEDs, PCB mounting bosses, all electronics
- **Left half (X<0) — Cover:** Purely mechanical shell, snaps onto chassis
- Front-face features (speaker grille, mic) are split between halves at X=0
- Mic hole shifted to x=+1mm so it's fully on the chassis half
- Print each half with the outer flat face (long side) down on the bed

### 3.6.3. Snap-Fit Joint System (No Glue)

The two halves are held together by a tongue-and-groove + snap-clip system designed for repeated open/close during prototyping without glue. Enables battery replacement by popping the cover off.

#### 3.6.3.1. Tongue-and-Groove Rails (Alignment)
- Runs along full Z height (inset 5mm from top/bottom to clear fillet zones) on both front and back wall seams
- **Tongue:** 1.0mm wide (Y) × 0.8mm protrusion (X), on cover (left) half split face, extends into chassis half
- **Groove:** 1.3mm wide × 0.95mm deep, cut into chassis (right) half split face
- 0.15mm per-side clearance for FDM tolerance
- Provides lateral (Y) and radial (X) alignment

#### 3.6.3.2. Cantilever Snap Clips (Retention)
- 4 clips total: 2 on front wall, 2 on back wall, at Z = 45mm and Z = 135mm
- Positioned at wall center (Y = ±19.2mm), avoiding feature zones
- **Beam:** 8mm long (Z) × 3mm wide (Y) × 0.8mm thick (X), attached at top, free end at bottom
- **Hook:** 0.4mm additional protrusion (X) at free end, 1.0mm tall (Z)
- **Ramp:** 1.5mm rectangular lead-in above hook for easy assembly
- **Pocket in chassis (right) half:** Shallow slot (beam-thickness deep) with deeper notch at hook zone
- **Deflection safety:** 0.4mm undercut is ~40% of PLA max (1.0mm for 8mm beam), safe for repeated cycling
- **Material note:** PETG recommended for best fatigue life (500+ cycles vs ~50 for PLA)

### 3.6.4. Implementation: Union Overlap Requirement
CadQuery `.union()` creates a compound (multiple disconnected solids) instead of a single fused solid when operands only touch at a boundary without volumetric overlap. This breaks boolean splitting.

**Fix applied:**
- Battery cradle rib half-rings overlap slightly with inner walls for solid union
- Result: `build_enclosure()` returns a single solid that splits cleanly

### 3.6.5. XZ Workplane Normal Direction
The `cq.Workplane("XZ")` normal is **-Y** (not +Y). This means:
- `.extrude(positive)` goes in **-Y** direction
- `.extrude(negative)` goes in **+Y** direction

This is a common source of confusion when creating geometry on the XZ plane.

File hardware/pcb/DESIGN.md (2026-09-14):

# Devais electrical design — 13 September 2026 (revision 2)

**Status: schematic-level design, not yet captured or routed.** Every part,
net and passive below is specified so the schematic can be entered without
further design decisions. Values marked **verify** were not confirmed from a
primary source; see `docs/research/2026-09-13-*.md` for the verification trail
of everything else. `index.circuit.tsx` is still the old XIAO sketch; do not
manufacture it.

Decisions D1–D8 from the 2026-09-13 session change the previous revision of
this document. D3, D4, D5 and D8 are settled; D1 (harness width), D6 (speaker)
and D7 (assembler) are open and marked where they matter. Where this revision differs from the mechanical assembly in
`cad/ASSEMBLY.md`, the required mechanical updates are listed at the end.

Parts, quantities and sourcing are in [`../BOM.md`](../BOM.md).

## What changed from revision 1

| Item | Revision 1 | Revision 2 | Reason |
|---|---|---|---|
| USB port | Charging only, SWD for firmware | Charging plus USB 2.0 data for DFU and debug; SWD retained for bootloader and recovery | User requirement |
| 3.3 V supply | TPS63031 buck-boost | None. Module runs in high-voltage mode from the system rail; its REG0 output supplies the mic and pull-ups | Both external regulators idle at 25–30 µA; REG0 costs nothing extra and the module's VDD may supply 25 mA |
| Type-C current detection | TUSB320LAI | CC1/CC2 read by the SAADC through the harness | Removes a QFN and gains the same information |
| Battery voltage | Resistor divider on AIN2 | SAADC `VDDHDIV5` internal channel | No divider leakage, no pins |
| Charge current | 300 mA | 1.0 A, input limit 1.2 A on a 1.5 A or 3 A Type-C source | User decision. The safety timer maximum of 9.5 h typical could not cover 300 mA on a 3350 mAh cell either. 1.2 A is the limit of the ready-made USB harness (two 0.7 A contacts on VBUS) |
| Mic power switch | High-side switch | None. Clock held below 200 kHz puts the T3902 in sleep, 20 µA max | Datasheet |
| Microphone | IM69D130 (out of stock) | TDK T3902, PDM, bottom port, Standard mode from 1.0 MHz | Stock; runs at the nRF reset-default 1.032 MHz clock |
| VBUS ESD | ESD441 (DFN0603) | USBLC6-2SC6 only | Hand assembly: DFN0603 is not hand-placeable |
| LEDs | 2 × WS2812B-2020-V6 with data line and power switch | 2 × 3 mm common-anode RGB LEDs, anodes on SYS, six cathodes sunk by GPIO through resistors on the main board | User decision for V1; the V6 and its 3.3 V question drop out |
| Cell protection | BQ29700 class | DW01A + FS8205A, plus 2 A-hold PPTC in the positive lead | Stock, cost, package. Over-discharge threshold 2.4 V is enforced at 3.0 V in firmware |
| Cell thermistor | 10 kΩ, B unspecified | Semitec 103AT-2, 10 kΩ, B = 3435 K | Matches BQ24074 default TS network with no extra resistors |

## Architecture

```mermaid
flowchart TB
    USB[USB-C board: receptacle, Rd, ESD] -->|8-way SH: VBUS x2, GND x2, D+, D-, CC1, CC2| MAIN
    subgraph MAIN[Main PCB 26 x 126 mm]
        CHG[BQ24074 charger and power path]
        PROT[DW01A + FS8205A + PPTC]
        MCU[MDBT50Q-1MV2, high-voltage mode]
        AMP[MAX98357A]
        LEDR[6 × LED series resistors]
        SWD[TC2030 SWD pads]
    end
    CELL[18650 + NTC] -->|PH 2-way and SH 2-way| PROT
    PROT <--> CHG
    CHG -->|SYS 3.0 to 4.4 V| MCU
    CHG -->|SYS| AMP
    CHG -->|SYS, common anode| LED[LED board: 2 × 3 mm RGB LEDs]
    MCU -->|VDD 3.3 V from REG0| MIC[Mic board: T3902]
    MIC -->|PDM| MCU
    MCU -->|I2S| AMP
    AMP -->|differential| SPK[Speaker 8 ohm 1 W]
    MCU -->|6 cathodes| LEDR --> LED
    BTN[PTT and power switches] --> MCU
```

Rails:

| Net | Source | Range | Loads |
|---|---|---|---|
| VBUS | USB receptacle | 4.35–5.5 V, absent when unplugged | BQ24074 IN, module VBUS pad |
| SYS | BQ24074 OUT | 4.4 V with input present; BAT minus ≤100 mV otherwise (3.0–4.2 V) | Module VDDH, amplifier VDD, LED common anodes |
| VDD | Module REG0 output (pad 28), programmed to 3.3 V | 3.3 V while SYS > 3.6 V, follows SYS minus 0.3 V below that | Mic, button pull-ups, charger status pull-ups, SWD VTREF |
| BAT | BQ24074 BAT pins | 3.0–4.2 V | Cell through PPTC and protection FETs |
| GND | | | Everything except CELL− |
| CELL− | Cell negative terminal | | Protection FET side only; never tied to GND elsewhere |

## Main PCB

### U1 Raytac MDBT50Q-1MV2 (high-voltage mode, REG0 LDO, Raytac section 8.2)

| Pad | Signal | Connection |
|---|---|---|
| 28 VDD | VDD | 10 µF + 100 nF to GND. Output only; nothing else drives it |
| 30 VDDH | SYS | 10 µF + 100 nF to GND |
| 31 DCCH | — | No connection (LDO mode) |
| 32 VBUS | VBUS_MCU | 2.2 Ω 0603 from VBUS (Nordic recommendation), 4.7 µF to GND. Total VBUS capacitance across all boards must stay under 10 µF for USB inrush; the budget is 1 µF (USB board) + 1 µF (charger IN) + 4.7 µF here |
| 34 D− | USB_DM | 0 Ω 0603 to J_USB pin 5. Raytac shows 27 Ω, Nordic states the series resistors are internal; fit 0 Ω, keep the footprint |
| 35 D+ | USB_DP | 0 Ω 0603 to J_USB pin 6. No external pull-up: it is internal and Nordic forbids an external one |
| 17 XL1, 18 XL2 | | 32.768 kHz crystal, 12.5 pF load, 2 × 12 pF C0G to GND (Raytac reference values; confirm against the crystal's CL) |
| 40 P0.18 | nRESET | To SWD pad; 10 kΩ pull-up to VDD, 100 nF to GND. Becomes reset only after UICR PSELRESET is programmed over SWD |
| 51 SWDIO, 53 SWDCLK | | To SWD pads |
| 1, 2, 15, 33, 55 GND | GND | All grounds connected |

Antenna end of the module at the board edge, Z = 138. Copper exclusion on
every layer Z = 134.2…138, plus the top-layer notch from the Raytac drawing.
No mounting screws at Z = 134.

### GPIO allocation

Fast signals are on pads Raytac marks full-speed; DC signals may use
low-frequency pads. All 21 pads below were checked against the Raytac pin
table (Ver. L).

| Signal | nRF | Pad | Direction | External parts |
|---|---|---|---|---|
| I2S BCLK | P0.26 | 19 | out | 33 Ω series at the module |
| I2S LRCLK | P0.27 | 16 | out | 33 Ω series |
| I2S SDOUT (amp DIN) | P0.08 | 24 | out | 33 Ω series |
| PDM CLK | P0.06 | 22 | out | 33 Ω series. Held low when idle: mic enters Clock-Off mode |
| PDM DATA | P0.07 | 23 | in | none on main board (100 Ω on mic board) |
| BTN_PTT | P0.02 | 11 | in, wake | 10 kΩ to VDD, 100 nF to GND at the connector, 1 kΩ series to the pad |
| BTN_PWR | P0.03 | 9 | in, wake | same network |
| LED1_R, LED1_G, LED1_B | P1.01, P1.02, P1.03 | 61, 50, 60 | out, high-drive sink, PWM | 1 kΩ (red) or 560 Ω (green, blue) series to J_LED |
| LED2_R, LED2_G, LED2_B | P1.04, P1.05, P1.06 | 56, 59, 58 | out, high-drive sink, PWM | same |
| AMP_SD_MODE | P0.14 | 36 | out | 620 kΩ 1 % series to MAX98357A SD_MODE |
| CHG_CE | P1.14 | 7 | out | 100 kΩ pull-down. High disables charging |
| CHG_EN1 | P1.10 | 3 | out | 100 kΩ pull-down |
| CHG_EN2 | P1.11 | 4 | out | 100 kΩ pull-down |
| CHG_nCHG | P1.12 | 5 | in | 100 kΩ pull-up to VDD (open drain from charger) |
| CHG_nPGOOD | P1.13 | 6 | in | 100 kΩ pull-up to VDD |
| CC1_SENSE | P0.04 / AIN2 | 20 | analog in | none; 5.1 kΩ Rd is on the USB board |
| CC2_SENSE | P0.05 / AIN3 | 21 | analog in | none |
| VBAT | SAADC VDDHDIV5 | internal | analog | none |
| nRESET | P0.18 | 40 | | see above |

Unused pads are left unconnected. P0.11, P0.12 and P0.13 (pads 27, 29, 37)
are spare full-speed pads; the LED cathodes use low-frequency pads because
PWM at about 1 kHz is well under the 10 kHz limit. Do not route anything to
the QSPI-recommended pads or the NFC pads.

Firmware notes that follow from this table: the Adafruit nRF52 bootloader
board `raytac_mdbt50q_db_40` assigns its DFU button to P0.11 and its LED to
P1.13, which conflicts with CHG_nPGOOD. Fork the board definition with DFU
button = P0.02 (PTT) and the status LED on P1.01 (LED1 red), active low. The bootloader must also program REGOUT0 to 3.3 V; a blank
device outputs 1.8 V on VDD, which is below the LED VIH and the button logic
levels. Check that the forked bootloader does this before relying on USB DFU.

### U2 BQ24074RGTR charger and power path (QFN-16)

| Pin | Name | Connection |
|---|---|---|
| 1 | TS | J_NTC pin 1. Semitec 103AT-2 to VSS through J_NTC; no bias resistors (B = 3435 K matches the datasheet network) |
| 2, 3 | BAT | BAT net, 10 µF to GND |
| 4 | CE | CHG_CE, 100 kΩ pull-down |
| 5 | EN2 | CHG_EN2, 100 kΩ pull-down |
| 6 | EN1 | CHG_EN1, 100 kΩ pull-down |
| 7 | PGOOD | CHG_nPGOOD, 100 kΩ pull-up to VDD |
| 8 | VSS | GND, routed as its own trace to the plane, not only through the pad |
| 9 | CHG | CHG_nCHG, 100 kΩ pull-up to VDD |
| 10, 11 | OUT | SYS net, 22 µF to GND |
| 12 | ILIM | 1.33 kΩ 1 % to VSS: 1.2 A input limit in EN mode (1,0), the harness contact limit |
| 13 | IN | VBUS, 1 µF 25 V to GND (must stay under 10 µF) |
| 14 | TMR | 71.5 kΩ 1 % to VSS: 9.5 h safety timer, the maximum |
| 15 | ITERM | Open: termination at 10 % of charge current |
| 16 | ISET | 890 Ω 1 % to VSS: 1.0 A charge current |
| pad | | GND, at least 8 thermal vias |

Input current limit by EN1/EN2: (0,0) = 100 mA, the reset default because
both GPIOs and both external pull-downs are low; (0,1) = 500 mA; (1,0) = ILIM
resistor, 1.2 A; (1,1) = standby, no charging. Firmware selects 500 mA after
USB enumeration or when a CC pin reads Default, and 1.2 A only when a CC pin
reads 1.5 A or 3 A. With input present OUT is regulated at 4.4 V; charge
current is reduced by DPPM when the system takes the input budget, so on a
500 mA source the cell charges at 500 mA minus system load.

At 1.0 A a 3350 mAh cell charges in about 4 h, inside the 9.5 h timer. On a
500 mA source it takes about 7.5 h, which can exceed the 7.2 h worst-case
timer; firmware then toggles CE to restart the timer when CHG goes inactive
with BAT below 4.1 V. Do not disable the timer.

Dissipation at 1.0 A is 1.4 W with the cell at 3.6 V and up to 2 W at 3.0 V.
The charger's thermal regulation folds charge current back at 125 °C
junction, so the part protects itself, but the case will be warm and the
thermal pad needs its vias and copper. If that proves unacceptable on the
bench, reduce ISET; the layout does not change.

### U3 DW01A + Q3 FS8205A cell protection, F1 PPTC

| Net | Path |
|---|---|
| J_BAT pin 1 (cell +) | F1 PPTC, 2.0 A hold (1812 size; **verify** part, a 1.1 A hold part derates below the 1 A charge current at 50 °C) → BAT net |
| J_BAT pin 2 (cell −) | CELL− net → FS8205A common source pair → GND. The two FETs are drain-connected internally; source 1 to CELL−, source 2 to GND |
| DW01A pin 5 VCC | 100 Ω from BAT, 100 nF to CELL− |
| DW01A pin 6 GND | CELL− |
| DW01A pin 2 CS | 1 kΩ to GND (pack negative side of the FETs) |
| DW01A pin 1 OD | FS8205A gate 1 (discharge FET) |
| DW01A pin 3 OC | FS8205A gate 2 (charge FET) |
| DW01A pin 4 TD | Open |

Thresholds: overcharge 4.30 V, release 4.10 V; over-discharge 2.40 V, release
3.00 V; overcurrent 150 mV across the FET pair, 2.4–3.5 A with FS8205A;
short-circuit 1.2 V. Firmware enforces the usable cutoff at 3.0 V by entering
System OFF; the DW01A is the backstop. CELL− must not connect to GND anywhere
else: no test pad, no mounting hole, no connector shell.

The PPTC and protection do not prevent damage from a reversed cell. Reverse
insertion is prevented mechanically (recessed positive contact, see
mechanical updates).

### U4 MAX98357AETE+ amplifier (TQFN-16)

| Pin | Name | Connection |
|---|---|---|
| 1 | DIN | I2S SDOUT through 33 Ω |
| 2 | GAIN_SLOT | Floating: 9 dB. Two unpopulated 0603 sites, one to GND (12 dB) and one to VDD (6 dB), for bench tuning |
| 3, 11, 15 | GND | GND |
| 4 | SD_MODE | AMP_SD_MODE through 620 kΩ. GPIO high gives about 0.46 V at the pin, the (L+R)/2 mono window 0.16–0.77 V; GPIO low or reset gives shutdown, 0.6 µA typical |
| 5, 6, 12, 13 | NC | Open |
| 7, 8 | VDD | SYS, 22 µF + 100 nF at the pins |
| 9 | OUTP | J_SPK pin 1 |
| 10 | OUTN | J_SPK pin 2 |
| 14 | LRCLK | I2S LRCLK through 33 Ω |
| 16 | BCLK | I2S BCLK through 33 Ω |
| pad | | Ground plane for heat; not internally connected |

The amplifier is filterless; the datasheet specifies no output filter and
shows compliance with 300 mm of unfiltered speaker cable. Use wide output
traces, keep them short, and keep the twisted pair away from the mic harness.
Neither speaker pin is ground. The MCU sends the same sample in both I2S slots.

### LED drive

Six series resistors on the main board, one per cathode: 1 kΩ for red,
560 Ω for green and blue, giving about 2 mA per die at SYS = 4.2 V and less
as the cell drains. The anodes sit on SYS so blue and green keep headroom
down to about 3.3 V; below that they dim, which is acceptable for an
indicator. Configure the six pads as high-drive outputs (9 mA sink) and drive
them high at boot: with the pin at 3.3 V the LED sees at most 1.1 V forward
and stays off. Before firmware runs the pads are inputs; the LED then only
passes leakage-level current into the pad's protection diode, which is
tolerable but is why the boot code sets the outputs first. Brightness by PWM
at about 1 kHz.

### Buttons

J_PTT and J_PWR are two-pin: pin 1 signal, pin 2 GND. Each signal has 10 kΩ
to VDD, 100 nF to GND placed at the connector, then 1 kΩ in series to the
module pad. The RC gives about 1 ms of hardware filtering and the resistor
limits ESD current into the pad; firmware debounces (Omron specifies 5 ms
bounce). Both pins are configured for GPIO sense wake from System OFF. The
10 kΩ pull-up gives 330 µA through the closed contact, below the switch's
1 mA minimum switching current; this is common practice for logic-level
tactile switches and is accepted here.

### SWD

Tag-Connect TC2030-NL footprint on the inward face, accessible with the
cover off: VTREF = VDD, SWDIO, nRESET, SWDCLK, GND, pin 6 unused. First
bootloader flash, UICR programming (REGOUT0, PSELRESET) and recovery use
this. There is no reset button; recovery is SWD, or the bootloader's
double-tap reset and 1200-baud touch over USB, or holding PTT at reset.

### Connectors on the main board

All SH headers are side-entry SMT (2.9 mm tall) so the plugs lie parallel to
the board. Contact numbers are JST's. Mark pin 1 on silkscreen.

| Ref | Header | Pin order | Destination |
|---|---|---|---|
| J_BAT | B2B-PH-SM4-TB, top entry | 1 CELL+, 2 CELL− | Cell contacts |
| J_USB | SM08B-SRSS-TB | 1 VBUS, 2 VBUS, 3 GND, 4 D−, 5 D+, 6 GND, 7 CC1, 8 CC2 | USB-C board |
| J_MIC | SM04B-SRSS-TB | 1 VDD, 2 GND, 3 PDM_CLK, 4 PDM_DATA | Mic board |
| J_LED | SM07B-SRSS-TB | 1 SYS (anodes), 2 LED1_R, 3 LED1_G, 4 LED1_B, 5 LED2_R, 6 LED2_G, 7 LED2_B | LED board |
| J_PTT | SM02B-SRSS-TB | 1 BTN_PTT, 2 GND | PTT switch |
| J_PWR | SM02B-SRSS-TB | 1 BTN_PWR, 2 GND | Power switch |
| J_SPK | SM02B-SRSS-TB | 1 OUTP, 2 OUTN | Speaker |
| J_NTC | SM02B-SRSS-TB | 1 TS, 2 GND | Cell thermistor |

The two-pin harnesses are not interchangeable: a speaker plugged into J_PTT
shorts nothing but a switch plugged into J_SPK shorts the amplifier output.
Label each harness at both ends.

## USB-C daughterboard

About 13 × 10 mm (the receptacle body is 8.94 mm wide), 1.0 mm thick as
modeled, bonded into the printed shoe that carries insertion load.

| Part | Connection |
|---|---|
| J1 GCT USB4105-GF-A-120 | 16-contact USB 2.0 receptacle, 20,000 cycles, through-hole shell stakes. Both VBUS pins to VBUS, both GND pins to GND, both D+ pins tied together, both D− pins tied together, shell to GND, SBU open |
| R1, R2 5.1 kΩ 1 % 0603 | CC1 and CC2 to GND, at the receptacle. 1 % tolerance is required for the current-advertisement thresholds |
| D1 USBLC6-2SC6 | Pin 1 to D+, pin 6 to D+ (through-route), pin 3 and 4 to D−, pin 2 GND, pin 5 VBUS |
| C1 1 µF 25 V 0603 | VBUS to GND |
| J2 SM08B-SRSS-TB | Pin order as J_USB. D+ and D− adjacent; each flanked by a ground or supply |

CC sensing: with Rd = 5.1 kΩ the CC pin reads 0.20–0.66 V for a Default
source, 0.66–1.23 V for 1.5 A, above 1.23 V for 3 A; below 0.20 V is
unattached. Only one of CC1/CC2 is pulled up depending on plug orientation.
The SAADC reads a 5.1 kΩ source at its shortest acquisition time.

## Microphone daughterboard

15 × 8 × 1.6 mm, TDK T3902 (order code MMICT390200012, LGA-5,
3.5 × 2.65 × 0.98 mm) on the inward face with its bottom port over a 0.8 mm
PCB hole aligned with the enclosure opening. Keep paste off the hole.

| Part | Connection |
|---|---|
| U1 T3902 (LGA-5) | 1 DATA, 2 SELECT, 3 GND, 4 CLK, 5 VDD |
| SELECT | GND: right channel, data driven on the falling clock edge; DATA tristates when the clock stops, so enable the nRF PDM DIN pull-down |
| C1 100 nF X7R 0603 | VDD to GND, adjacent to pin 5 |
| R1 100 Ω 0603 | In series with DATA at the mic, to damp ringing. No pull-up or pull-down on DATA |
| J1 SM04B-SRSS-TB | Pin order as J_MIC |

Supply 1.65–3.63 V: powered from VDD, never from SYS. Standard mode with a
1.0–3.3 MHz clock, 500 µA maximum, 64.5 dBA SNR; the nRF reset-default
1.032 MHz with Ratio64 is inside this range, and 1.280 MHz with Ratio80 gives
exactly 16 kHz. Sleep with the clock stopped or below 200 kHz, 20 µA
maximum. Fallback with the same pinout class: MEMSensing MSM261DDB019
(LCSC C51928210), which needs a clock above 1.1 MHz.

## LED daughterboard

About 12 × 8 × 1.6 mm (the 7-position header is 9 mm wide), emitters 6 mm
apart at the `LED_POSITIONS_X` values in `cad/enclosure.py` (X = 0 and 6 in
the current working tree), header on the inward face.

| Part | Connection |
|---|---|
| D1, D2 3 mm common-anode RGB LED, diffused | Anodes to J1 pin 1; cathodes to J1 pins 2–7 in the J_LED order. LED bodies pass through the enclosure holes, which must open to 3.2 mm |
| J1 SM07B-SRSS-TB | Pin order as J_LED |

No resistors or capacitors on this board; the series resistors are on the
main board. Through-hole LEDs are hand-soldered after the panel is assembled,
so this board needs no machine placement at all.

## Harness and lead specification

Signal harnesses are JST SR ready-made IDC cables: 30 AWG, SR plugs on both
ends mating with the SH headers, contacts rated 0.7 A, suffix A = pin 1 to
pin 1. No crimping. The two VBUS contacts in parallel set the 1.2 A input
limit. Battery leads are JST pre-crimped 24 AWG PH leads (1.4 mm
insulation). Centerlines are from the fit report (2026-09-14).

| Harness | Conductors | Centerline | Cable | Use | Terminations |
|---|---|---|---|---|---|
| USB | 8 | 48 mm | A08SR08SR30K102A (102 mm) | whole; fold the excess in the shoe pocket | SR both ends, factory |
| MIC | 4 | 48 mm | A04SR04SR30K152A (152 mm) | whole; coil the excess | SR both ends, factory |
| LED | 7 | 24 mm | A07SR07SR30K102A (102 mm) | whole; coil the excess behind the speaker | SR both ends, factory |
| PWR | 2 | 45 mm | A02SR02SR30K152A halved | 76 mm | SR factory end; solder to switch |
| PTT | 2 | 43 mm | A02SR02SR30K152A halved | 76 mm | SR factory end; solder to switch |
| SPK | 2, twisted | 43 mm | A02SR02SR30K152A halved | 76 mm | SR factory end; solder to speaker pads |
| NTC | 2 | 50 mm | A02SR02SR30K152A halved | 76 mm | SR factory end; solder to thermistor leads, insulate |
| BAT+ | 1 | 24 mm | ASPHSPH24K305 remainder | 65 mm | PH factory end; solder to positive contact tab |
| BAT− | 1 | 124 mm | ASPHSPH24K305 | 165 mm | PH factory end; solder to negative contact tab |

A cut cable cannot be re-terminated with an SR plug (IDC, factory only);
replace it with a fresh half. Voltage drop on the battery pair at 1 A is
under 30 mV. Mark pin 1 with heat-shrink or paint on every plug, and check
continuity against this document before first power.

## PCB construction

Four layers, 1.6 mm: signals and components, continuous ground, power and
signals, bottom signals. No components on the wall-facing side. Passives
0603 minimum everywhere, no DFN or 0402, for hand assembly with a hot
plate and stencil (see `../BOM.md`). Keep the charger, PPTC,
protection and amplifier supply loop compact and near J_BAT; keep the PDM
clock and data away from the amplifier outputs; keep D+/D− as a coupled pair
from the module to J_USB. Antenna keep-out on every layer.

Open item: the MDBT50Q-1MV2 is an LGA module and needs reflow, not an iron.
Hot-plate reflow of the module is the plan; the castellated MinewSemi MS88SF2
is the fallback but ties VBUS to VDDH, which changes the power scheme. The
decision is deferred to the 25-unit run; prototypes use the XIAO nRF52840
Sense (`../PROTOTYPE.md`).

## Bench checks before enclosure assembly

1. SWD: program REGOUT0 = 3.3 V and PSELRESET, flash the forked bootloader,
   confirm VDD = 3.3 V and USB enumeration.
2. Charger: input limit in each EN state, 1.0 A charge, case temperature at
   1.0 A with the cell at 3.2 V, termination, CHG and PGOOD levels, TS fault
   with the thermistor heated and cooled.
3. Protection: over-discharge and overcharge trip with a bench supply in place
   of the cell, PPTC not tripping at 1.2 A.
4. CC sense: ADC readings on a Default port, a 1.5 A and a 3 A charger, in
   both plug orientations.
5. Audio: mic capture with the clock stopped and started, amplifier shutdown
   current, playback into the chosen speaker, no clipping at 9 dB.
6. Sleep: System OFF current of the full board with LED outputs driven high.
7. BLE range and USB DFU with the cover fitted.

## Mechanical updates required by this revision

Implemented in `cad/` on 2026-09-14 (fit report PASS): 8-way USB header and
bundle, 12 × 8 mm LED board with 3.2 mm holes, 72.0 mm cradle with Keystone
5201/5223 carriers and a 1.9 mm reverse-insertion collar around the positive
plate, CMS-2053-18SP cup and bridge. The list below is the requirement as
written before that work.

- USB daughterboard width grows to about 10 mm in the receptacle direction
  and carries an 8-position SH header (10 mm wide). Check the shoe pocket.
- Harness envelopes: 8 conductors in the USB bundle and 7 in the LED bundle;
  battery lead insulation 1.4 mm, not 1.2 mm.
- LED board grows to about 12 × 8 mm; LED holes open from 3.0 to 3.2 mm.
- Battery cradle: inside length 72.0 mm for Keystone 5201 + 5223 contacts
  (currently 71.0), bore at least 19.0 mm (LG MJ1 is 18.65 mm maximum;
  Samsung 35E is 18.55 mm), recessed positive contact for reverse-insertion
  prevention.
- Speaker: if CMS-2053-18SP (5.3 mm deep) is used instead of CMS-2004-18SP
  (4.0 mm), the speaker bridge moves 1.3 mm inward.
- TC2030 pad location on the main board must be reachable with the cover off.
- Mic board outline is unchanged.

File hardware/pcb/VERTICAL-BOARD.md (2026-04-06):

# Vertical Main Board Architecture

## Decision
Single 140x28mm PCB mounted vertically in the chassis (right) half of the enclosure,
along the inner surface of the right wall. Replaces the previous horizontal 28x65mm
board + separate USB-C daughter board.

## Board Orientation
- Board runs along the Z axis (enclosure height), from Z~5mm to Z~145mm
- Board width (28mm) spans the interior cross-section
- Front side faces inward (toward battery / enclosure center)
- Back side faces the right enclosure wall

## Back-Side Components (through enclosure wall)
| Component | Enclosure Z | Function |
|---|---|---|
| USB-C receptacle | 31mm | Charging port, mid-mount through wall |
| Power switch | 44mm | Power/mode button through 8mm hole |
| PTT switch | 105mm | Push-to-talk, actuated by big orange button |

## Front-Side Zones
- Z=5-65mm (battery zone): Power management (charger, regulator, caps).
  Max component height ~3.4mm (SOT-223, SOIC-8, passives OK).
- Z=65-145mm (above battery): Full depth available. MCU, amp, audio
  connectors, LED connector, decoupling caps.

## Connectors (JST, front side)
- J_BAT: 2-pin, bottom of board (near battery terminals)
- J_SPK: 2-pin, upper section
- J_LED: 3-pin, near top (LED board at top of enclosure)
- J_MIC: 5-pin, mid-upper section (mic is at bottom of front face,
  cable routes internally)

## Mounting
- Screw-mounted to chassis half via M2 holes at corners + mid-board
- Board standoffs set the distance from wall to accommodate back-side components

## What This Eliminates
- Separate USB-C daughter board (was: JST + CC resistor board)
- Separate PTT button board
- SW_PTT and SW_PWR as on-board tactile switches (replaced by through-wall switches)

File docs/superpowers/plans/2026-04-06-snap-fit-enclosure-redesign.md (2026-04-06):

# Snap-Fit Enclosure Redesign Implementation Plan

> **For agentic workers:** REQUIRED SUB-SKILL: Use superpowers:subagent-driven-development (recommended) or superpowers:executing-plans to implement this plan task-by-task. Steps use checkbox (`- [ ]`) syntax for tracking.

**Goal:** Redesign the DevAIs enclosure to split left/right with snap-fit closure, eliminating the threaded bottom lid and consolidating all electronics onto the right (chassis) half.

**Architecture:** Single file modification to `cad/enclosure.py`. Remove lid/thread machinery, close the bottom, update LEDs to 2x RGB at new positions, add battery cradle ribs, shift mic hole, and rewrite the split+joint system from Y=0 to X=0.

**Tech Stack:** CadQuery (Python), STL export, `uv run cad-generate` + `uv run cad-preview` for verification.

**Spec:** `docs/superpowers/specs/2026-04-06-snap-fit-enclosure-redesign.md`

**Verification:** This is CAD geometry code — there are no unit tests. Verification is done by generating STL files and visually inspecting the preview PNGs. After each task that modifies geometry, run the build and check the output.

---

### Task 1: Remove Lid Machinery

Remove all bottom lid parameters, functions, and references.

**Files:**
- Modify: `cad/enclosure.py:53-71` (parameters), `cad/enclosure.py:123-158` (create_thread_ridge), `cad/enclosure.py:451-522` (add_lid_receiver, create_bottom_lid), `cad/enclosure.py:717` (build_enclosure call), `cad/enclosure.py:742-745` (main lid export)

- [ ] **Step 1: Delete lid parameters (lines 53-71)**

Remove this entire block:

```python
# Bottom Lid
LID_THREAD_BORE = 33.0        # Internal thread major diameter (bore)
LID_THREAD_PITCH = 3.0        # Coarse pitch for FDM printing
LID_THREAD_DEPTH = 1.0        # Thread ridge depth
LID_THREAD_TURNS = 2.5
LID_THREAD_HEIGHT = LID_THREAD_PITCH * LID_THREAD_TURNS  # 7.5mm
LID_THREAD_CLEARANCE = 0.3    # Per-side clearance for printing

LID_RECEIVER_BOTTOM_Z = 2.0   # Start above bottom to clear outer fillet
LID_RECEIVER_HEIGHT = 10.0

LID_DISC_DIAMETER = 36.0      # Round lid filling most of octagonal opening
LID_DISC_THICKNESS = 2.5
LID_BOSS_OD = LID_THREAD_BORE - 2 * LID_THREAD_DEPTH - 2 * LID_THREAD_CLEARANCE
LID_BOSS_HEIGHT = LID_THREAD_HEIGHT

COIN_SLOT_WIDTH = 2.5         # Wide enough for coin edge
COIN_SLOT_DEPTH = 1.2
COIN_SLOT_LENGTH = 22.0
```

- [ ] **Step 2: Delete `create_thread_ridge()` function (lines 123-158)**

Remove the entire function.

- [ ] **Step 3: Delete `add_lid_receiver()` function (lines 451-478)**

Remove the entire function.

- [ ] **Step 4: Delete `create_bottom_lid()` function (lines 480-522)**

Remove the entire function.

- [ ] **Step 5: Remove `add_lid_receiver()` call from `build_enclosure()`**

In `build_enclosure()`, delete this line:

```python
    enclosure = add_lid_receiver(enclosure)
```

- [ ] **Step 6: Remove lid export from `main()`**

Delete these lines from `main()`:

```python
    print("Generating bottom lid...")
    lid = create_bottom_lid()
    cq.exporters.export(lid, str(output_dir / "bottom_lid.stl"))
    print("Exported bottom_lid.stl")
```

- [ ] **Step 7: Verify it still builds**

Run: `uv run cad-generate`
Expected: Generates enclosure.stl, enclosure_front.stl, enclosure_back.stl, large_button.stl (no bottom_lid.stl)

- [ ] **Step 8: Commit**

```bash
git add cad/enclosure.py
git commit -m "Remove threaded bottom lid machinery from enclosure"
```

---

### Task 2: Close the Bottom

Change the hollowing operation so the bottom is a solid wall instead of open.

**Files:**
- Modify: `cad/enclosure.py` — `build_enclosure()` function, hollowing section

- [ ] **Step 1: Modify the inner solid to start at WALL_THICKNESS instead of -1.0**

In `build_enclosure()`, find the hollowing section and change it. The current code starts the inner solid at Z=-1.0 to ensure an open bottom. Change it to start at Z=WALL_THICKNESS so a solid bottom wall remains.

Replace:

```python
    # Hollow out using boolean subtraction (more reliable than .shell() on filleted geometry).
    # Inner solid starts 1mm below Z=0 to ensure open bottom, extends to WALL_THICKNESS below top.
    h_inner = DEVICE_HEIGHT - WALL_THICKNESS

    max_c = DEVICE_WIDTH / 2.0
    h_l = HALF_LONG_SIDE
    pts = [
        (max_c, h_l), (h_l, max_c), (-h_l, max_c), (-max_c, h_l),
        (-max_c, -h_l), (-h_l, -max_c), (h_l, -max_c), (max_c, -h_l)
    ]

    inner_solid = (
        cq.Workplane("XY")
        .workplane(offset=-1.0)
        .polyline(pts).close()
        .offset2D(-WALL_THICKNESS)
        .extrude(h_inner + 1.0)
    )
```

With:

```python
    # Hollow out using boolean subtraction (more reliable than .shell() on filleted geometry).
    # Inner solid starts at WALL_THICKNESS (closed bottom) and extends to WALL_THICKNESS below top.
    h_inner = DEVICE_HEIGHT - 2 * WALL_THICKNESS  # Leave wall at both top and bottom

    max_c = DEVICE_WIDTH / 2.0
    h_l = HALF_LONG_SIDE
    pts = [
        (max_c, h_l), (h_l, max_c), (-h_l, max_c), (-max_c, h_l),
        (-max_c, -h_l), (-h_l, -max_c), (h_l, -max_c), (max_c, -h_l)
    ]

    inner_solid = (
        cq.Workplane("XY")
        .workplane(offset=WALL_THICKNESS)
        .polyline(pts).close()
        .offset2D(-WALL_THICKNESS)
        .extrude(h_inner)
    )
```

- [ ] **Step 2: Update inner fillet selection**

The current code fillets `>Z` (top) edges of the inner solid. Since the inner solid no longer extends below Z=0, the `>Z` selector still picks the top inner edge. No change needed for fillet selectors — they remain correct.

Verify this by reading the fillet code:

```python
    inner_fillet = FILLET_RADIUS - WALL_THICKNESS
    if inner_fillet > 0:
        inner_solid = inner_solid.edges(">Z").fillet(inner_fillet)
        inner_solid = inner_solid.edges("|Z").fillet(inner_fillet)
```

This is still correct — `>Z` selects the top face edges, `|Z` selects vertical edges.

- [ ] **Step 3: Build and verify**

Run: `uv run cad-generate`
Expected: Enclosure now has a solid bottom (no open hole).

Run: `uv run cad-preview cad/output/enclosure.stl --views iso`
Then read the PNG to visually confirm the bottom is closed.

- [ ] **Step 4: Commit**

```bash
git add cad/enclosure.py
git commit -m "Close enclosure bottom with solid wall"
```

---

### Task 3: Update LED Parameters and Function

Change from 3 single-color LEDs to 2 RGB LEDs at new X positions.

**Files:**
- Modify: `cad/enclosure.py` — LED parameters and `add_led_holes()` function

- [ ] **Step 1: Update LED parameters**

Replace:

```python
LED_DIAMETER = 3.0
LED_SPACING = 8.0
LED_TOP_OFFSET = 10.0
```

With:

```python
LED_DIAMETER = 3.0  # 3mm holes for WS2812B-2020 (2mm) with light diffusion margin
LED_POSITIONS_X = [5.0, 11.0]  # Two RGB LEDs, both on right (chassis) half
LED_TOP_OFFSET = 10.0
```

- [ ] **Step 2: Rewrite `add_led_holes()`**

Replace the entire function:

```python
def add_led_holes(enclosure):
    """
    Front side (Y+), 10mm from top.
    2x 3mm holes for WS2812B-2020 RGB LEDs at explicit X positions.
    """
    z_pos = DEVICE_HEIGHT - LED_TOP_OFFSET

    for x_pos in LED_POSITIONS_X:
        hole = (
            cq.Workplane("XZ")
            .workplane(offset=CORNER_COORD)
            .center(x_pos, z_pos)
            .circle(LED_DIAMETER / 2)
            .extrude(-(WALL_THICKNESS + CUT_OVERSHOOT))
        )
        enclosure = enclosure.cut(hole)

    return enclosure
```

- [ ] **Step 3: Build and verify**

Run: `uv run cad-generate`
Run: `uv run cad-preview cad/output/enclosure.stl --views front`
Read the PNG. Expected: Two holes near the top-right of the front face (at x=5 and x=11), not three centered holes.

- [ ] **Step 4: Commit**

```bash
git add cad/enclosure.py
git commit -m "Update LEDs to 2x WS2812B-2020 RGB at x=5,11mm"
```

---

### Task 4: Shift Microphone Hole

Move mic from x=0 to x=+1mm so it's fully on the chassis half after the X=0 split.

**Files:**
- Modify: `cad/enclosure.py` — mic parameters and `add_mic_hole_and_mount()` function

- [ ] **Step 1: Add mic X offset parameter**

After the existing mic parameters, add:

```python
MIC_X_OFFSET = 1.0  # Shifted +1mm so hole is fully on chassis half after X=0 split
```

- [ ] **Step 2: Update `add_mic_hole_and_mount()` to use the offset**

In the acoustic hole section, change `.center(0, z_pos)` to `.center(MIC_X_OFFSET, z_pos)`.

In the mounting pocket section, change `.center(0, z_pos)` to `.center(MIC_X_OFFSET, z_pos)`.

Both workplane `.center()` calls need updating:

```python
def add_mic_hole_and_mount(enclosure):
    """
    Front side (Y+), 10mm from bottom.
    Shifted +1mm in X so hole is fully on chassis half after X=0 split.
    Includes acoustic hole and internal mounting pocket.
    """
    z_pos = MIC_BOTTOM_OFFSET

    # 1. External Acoustic Hole
    wp = (
        cq.Workplane("XZ")
        .workplane(offset=CORNER_COORD)
        .center(MIC_X_OFFSET, z_pos)
    )

    acoustic_hole = wp.circle(MIC_HOLE_DIAMETER / 2).extrude(-(WALL_THICKNESS + CUT_OVERSHOOT))
    enclosure = enclosure.cut(acoustic_hole)

    # Internal mounting pocket for INMP441 board.
    inner_y = CORNER_COORD - WALL_THICKNESS

    pocket = (
        cq.Workplane("XZ")
        .workplane(offset=inner_y)
        .center(MIC_X_OFFSET, z_pos)
        .rect(MIC_POCKET_WIDTH, MIC_POCKET_HEIGHT)
        .extrude(-MIC_POCKET_DEPTH)
    )

    enclosure = enclosure.cut(pocket)

    return enclosure
```

- [ ] **Step 3: Build and verify**

Run: `uv run cad-generate`
Expected: Mic hole slightly right of center on front face (barely noticeable).

- [ ] **Step 4: Commit**

```bash
git add cad/enclosure.py
git commit -m "Shift mic hole +1mm in X for chassis-side placement"
```

---

### Task 5: Add Battery Cradle

Add half-cylinder cradle ribs inside the right half to hold the 18650 battery.

**Files:**
- Modify: `cad/enclosure.py` — new parameters and new `add_battery_cradle()` function

- [ ] **Step 1: Add battery cradle parameters**

Add after the existing component parameters (after the snap clip parameters):

```python
# Battery cradle (18650: 18.6mm diameter x 65mm length)
BATTERY_DIAMETER = 18.6
BATTERY_LENGTH = 65.0
BATTERY_CRADLE_RADIUS = BATTERY_DIAMETER / 2 + 0.2  # 0.2mm clearance
BATTERY_CRADLE_THICKNESS = 1.5  # Rib wall thickness
BATTERY_CRADLE_RIB_WIDTH = 3.0  # Rib width along Z axis
BATTERY_CRADLE_BOTTOM_Z = WALL_THICKNESS + 2.0  # 2mm above bottom wall for spring clearance
# Rib Z positions: bottom, middle, top of battery zone (avoiding other internal features)
BATTERY_CRADLE_RIB_Z = [
    BATTERY_CRADLE_BOTTOM_Z + 5.0,           # Near bottom
    BATTERY_CRADLE_BOTTOM_Z + 32.5,          # Middle
    BATTERY_CRADLE_BOTTOM_Z + 60.0,          # Near top
]
```

- [ ] **Step 2: Add `add_battery_cradle()` function**

Add before `build_enclosure()`:

```python
def add_battery_cradle(enclosure):
    """
    Half-cylinder cradle ribs on the right (X>0) interior to hold an 18650 battery.
    The battery sits centered along Z. Ribs grip ~180 degrees.
    The cover half provides the other 180 degrees when closed.
    """
    outer_r = BATTERY_CRADLE_RADIUS + BATTERY_CRADLE_THICKNESS
    inner_r = BATTERY_CRADLE_RADIUS

    for z_pos in BATTERY_CRADLE_RIB_Z:
        # Full ring, then cut away the X<0 half (cover side)
        rib = (
            cq.Workplane("XY")
            .workplane(offset=z_pos)
            .circle(outer_r)
            .circle(inner_r)
            .extrude(BATTERY_CRADLE_RIB_WIDTH)
        )

        # Remove X<0 half — only keep the right-side cradle
        s = 50  # Oversized cutting box
        left_cut = (
            cq.Workplane("XY")
            .transformed(offset=(-s / 2, 0, z_pos + BATTERY_CRADLE_RIB_WIDTH / 2))
            .box(s, s, BATTERY_CRADLE_RIB_WIDTH + 1)
        )
        rib = rib.cut(left_cut)

        enclosure = enclosure.union(rib)

    return enclosure
```

- [ ] **Step 3: Call `add_battery_cradle()` in `build_enclosure()`**

Add after the `add_large_button_feature()` call:

```python
    enclosure = add_battery_cradle(enclosure)
```

- [ ] **Step 4: Build and verify**

Run: `uv run cad-generate`
Run: `uv run cad-preview cad/output/enclosure.stl --views iso`
Read the PNG. Expected: Three half-ring ribs visible inside the enclosure on the right side.

- [ ] **Step 5: Commit**

```bash
git add cad/enclosure.py
git commit -m "Add battery cradle ribs for 18650 on chassis half"
```

---

### Task 6: Rewrite Split and Joint System

Change the split plane from Y=0 to X=0. Move tongue-and-groove to front/back walls. Move snap clips to front/back walls. Rename halves from front/back to right/left.

**Files:**
- Modify: `cad/enclosure.py` — `split_enclosure()` function, snap clip parameter comments

- [ ] **Step 1: Update snap clip parameter comments**

Replace the comment block for snap clips:

```python
# Cantilever snap clips (retention for split halves)
# Beams on back half flex in Y to engage hooks in front half pockets.
```

With:

```python
# Cantilever snap clips (retention for split halves)
# Beams on cover (left) half flex in X to engage hooks in chassis (right) half pockets.
```

And update the tongue-and-groove comment:

```python
# Tongue-and-groove rails (alignment for split halves)
# Runs along full height on left/right wall seams. Critical for thread alignment.
```

With:

```python
# Tongue-and-groove rails (alignment for split halves)
# Runs along full height on front/back wall seams for X=0 split alignment.
```

- [ ] **Step 2: Rewrite `split_enclosure()` completely**

Replace the entire function with:

```python
def split_enclosure(enclosure):
    """
    Split enclosure into right (chassis) and left (cover) halves along X=0.
    Right half (X>0): All electronics, battery, buttons, ports
    Left half (X<0): Purely mechanical cover

    Joint system (no glue, repeatable open/close):
    1. Tongue-and-groove rails along front/back wall seams → alignment
    2. Cantilever snap clips at 2 Z positions per wall → retention
    """
    # --- Step 1: Split into halves at X=0 ---
    s = 300
    pos_x_tool = cq.Workplane("XY").transformed(offset=(s / 2, 0, s / 2 - 50)).box(s, s, s)
    neg_x_tool = cq.Workplane("XY").transformed(offset=(-s / 2, 0, s / 2 - 50)).box(s, s, s)

    right_half = enclosure.cut(neg_x_tool)  # remove X<0 → keep X>0 (chassis)
    left_half = enclosure.cut(pos_x_tool)   # remove X>0 → keep X<0 (cover)

    # Wall center Y for front/back walls
    wall_cy = CORNER_COORD - WALL_THICKNESS / 2  # 19.2mm

    # --- Step 2: Tongue-and-groove rails on front/back walls ---
    # Tongue on cover (left) half split face, groove in chassis (right) half.
    # Runs along Z, inset from top/bottom to avoid fillet zones.
    tongue_z_start = TONGUE_Z_MARGIN
    tongue_z_end = DEVICE_HEIGHT - TONGUE_Z_MARGIN
    tongue_z_len = tongue_z_end - tongue_z_start
    tongue_z_center = (tongue_z_start + tongue_z_end) / 2

    for sign in [1, -1]:  # front (+Y) and back (-Y) walls
        y = sign * wall_cy

        # Tongue: rectangular bar on cover (left) half, protruding from X=0 into chassis half (+X)
        # YZ workplane normal is +X, so extrude(positive) goes in +X
        tongue = (cq.Workplane("YZ").center(y, tongue_z_center)
                  .rect(TONGUE_WIDTH, tongue_z_len)
                  .extrude(TONGUE_HEIGHT))
        left_half = left_half.union(tongue)

        # Groove: matching slot cut into chassis (right) half at X=0 face
        groove = (cq.Workplane("YZ").center(y, tongue_z_center)
                  .rect(GROOVE_WIDTH, tongue_z_len)
                  .extrude(GROOVE_DEPTH))
        right_half = right_half.cut(groove)

    # --- Step 3: Cantilever snap clips on front/back walls ---
    # Snap beams on cover (left) half, pockets in chassis (right) half.
    # Beam attached at top, hook at bottom (free end).
    # 2 per wall (front and back), at Z = 45 and Z = 135.
    snap_z_positions = [45, 135]

    for sign in [1, -1]:  # front (+Y) and back (-Y) walls
        y = sign * wall_cy
        for z_attach in snap_z_positions:
            z_hook = z_attach - SNAP_BEAM_LENGTH  # Free end with hook

            # --- Beam on cover (left) half ---
            # The beam protrudes from the split face (X=0) into the chassis half (+X).
            # It's a thin cantilever that can flex in -X when the hook is pushed.
            beam_x_center = SNAP_BEAM_THICKNESS / 2  # center of beam in +X
            beam_z_center = z_attach - SNAP_BEAM_LENGTH / 2

            beam = (cq.Workplane("XY")
                    .transformed(offset=(beam_x_center, y, beam_z_center))
                    .box(SNAP_BEAM_THICKNESS, SNAP_BEAM_WIDTH, SNAP_BEAM_LENGTH))
            left_half = left_half.union(beam)

            # Hook at free end: additional protrusion in +X
            hook_x_center = SNAP_BEAM_THICKNESS + SNAP_HOOK_DEPTH / 2
            hook_z_center = z_hook + SNAP_HOOK_HEIGHT / 2

            hook = (cq.Workplane("XY")
                    .transformed(offset=(hook_x_center, y, hook_z_center))
                    .box(SNAP_HOOK_DEPTH, SNAP_BEAM_WIDTH, SNAP_HOOK_HEIGHT))
            left_half = left_half.union(hook)

            # Ramp on hook: angled lead-in for easy insertion.
            ramp_z_center = z_hook + SNAP_HOOK_HEIGHT + SNAP_HOOK_RAMP / 2
            ramp = (cq.Workplane("XY")
                    .transformed(offset=(hook_x_center, y, ramp_z_center))
                    .box(SNAP_HOOK_DEPTH, SNAP_BEAM_WIDTH, SNAP_HOOK_RAMP))
            left_half = left_half.union(ramp)

            # Cut the ramp into a wedge shape: full hook depth at bottom, zero at top.
            ramp_cut_angle = math.atan2(SNAP_HOOK_DEPTH, SNAP_HOOK_RAMP)
            ramp_cut_size = SNAP_HOOK_RAMP + SNAP_HOOK_DEPTH
            ramp_cut = (cq.Workplane("YZ")
                        .transformed(
                            offset=(SNAP_BEAM_THICKNESS + SNAP_HOOK_DEPTH,
                                    y,
                                    ramp_z_center),
                            rotate=(math.degrees(ramp_cut_angle), 0, 0))
                        .box(ramp_cut_size, SNAP_BEAM_WIDTH + 1, ramp_cut_size))
            left_half = left_half.cut(ramp_cut)

            # --- Pocket in chassis (right) half ---
            pocket_x_depth = SNAP_POCKET_DEPTH
            pocket_x_center = pocket_x_depth / 2
            pocket_z_len = SNAP_BEAM_LENGTH + 2 * SNAP_CLEARANCE
            pocket_z_center = beam_z_center

            pocket = (cq.Workplane("XY")
                      .transformed(offset=(pocket_x_center, y, pocket_z_center))
                      .box(pocket_x_depth,
                           SNAP_BEAM_WIDTH + 2 * SNAP_CLEARANCE,
                           pocket_z_len))
            right_half = right_half.cut(pocket)

            # Shallow pocket (beam depth) with deeper notch at hook zone
            shallow_pocket = (cq.Workplane("XY")
                              .transformed(offset=(SNAP_BEAM_THICKNESS / 2, y, pocket_z_center))
                              .box(SNAP_BEAM_THICKNESS + SNAP_CLEARANCE,
                                   SNAP_BEAM_WIDTH + 2 * SNAP_CLEARANCE,
                                   pocket_z_len))
            right_half = right_half.cut(shallow_pocket)

            # Deep notch at hook zone
            hook_notch_z_len = SNAP_HOOK_HEIGHT + SNAP_HOOK_RAMP + SNAP_CLEARANCE
            hook_notch_z_center = z_hook + hook_notch_z_len / 2
            hook_notch = (cq.Workplane("XY")
                          .transformed(offset=(pocket_x_center, y, hook_notch_z_center))
                          .box(pocket_x_depth,
                               SNAP_BEAM_WIDTH + 2 * SNAP_CLEARANCE,
                               hook_notch_z_len))
            right_half = right_half.cut(hook_notch)

    return right_half, left_half
```

- [ ] **Step 3: Build and verify**

Run: `uv run cad-generate`
Expected: Build succeeds (may fail — see Step 4 for main() update). If main() still references old names, fix that in Task 7 first, then verify.

---

### Task 7: Update `main()` Output

Rename output files and remove lid export.

**Files:**
- Modify: `cad/enclosure.py` — `main()` function

- [ ] **Step 1: Rewrite `main()` function**

Replace the entire function:

```python
def main():
    output_dir = Path("cad/output")
    output_dir.mkdir(parents=True, exist_ok=True)

    print("Generating enclosure...")
    enclosure = build_enclosure()
    cq.exporters.export(enclosure, str(output_dir / "enclosure.stl"))
    print("Exported enclosure.stl")

    print("Splitting enclosure for printing...")
    right_half, left_half = split_enclosure(enclosure)
    cq.exporters.export(right_half, str(output_dir / "enclosure_right.stl"))
    print("Exported enclosure_right.stl")
    cq.exporters.export(left_half, str(output_dir / "enclosure_left.stl"))
    print("Exported enclosure_left.stl")

    print("Generating large button...")
    button = create_large_button()
    cq.exporters.export(button, str(output_dir / "large_button.stl"))
    print("Exported large_button.stl")
```

- [ ] **Step 2: Build and generate all STLs**

Run: `uv run cad-generate`
Expected output:
```
Generating enclosure...
Exported enclosure.stl
Splitting enclosure for printing...
Exported enclosure_right.stl
Exported enclosure_left.stl
Generating large button...
Exported large_button.stl
```

- [ ] **Step 3: Preview all outputs**

Run: `uv run cad-preview cad/output/enclosure.stl`
Run: `uv run cad-preview cad/output/enclosure_right.stl`
Run: `uv run cad-preview cad/output/enclosure_left.stl`

Read each preview PNG and verify:
- `enclosure.stl`: Full enclosure with closed bottom, 2 LED holes (right side of front face), battery cradle ribs visible inside
- `enclosure_right.stl`: Chassis half — has button opening, power button, USB-C, LED holes, part of speaker grille, tongue grooves and snap pockets
- `enclosure_left.stl`: Cover half — plain shell, tongue protrusions and snap beams on inner face

- [ ] **Step 4: Commit**

```bash
git add cad/enclosure.py
git commit -m "Rewrite split to X=0, update outputs for snap-fit redesign"
```

---

### Task 8: Update Documentation

Update the enclosure spec and work files to reflect the new design.

**Files:**
- Modify: `context/enclosure-spec.md` — split section, LED section, bottom lid section

- [ ] **Step 1: Update the split section in enclosure-spec.md**

In section 3.5 "Split for 3D Printing", update:

Replace:

```markdown
## 3.5. Split for 3D Printing

The enclosure is split lengthwise at Y=0 into front and back halves for FDM printing.

### 3.5.1. Why Split?
- Printing a hollow octagonal tube upright produces excessive internal support material
- Two half-shells print flat on the bed with no supports needed

### 3.5.2. Split Plane: Y=0
- **Front half (Y>0):** LEDs, mic hole, speaker grille
- **Back half (Y<0):** plain back panel
- Right-side features (power button, USB-C, large button) are split symmetrically between halves — standard for two-piece enclosures
- Print each half with the outer flat face (long side) down on the bed
```

With:

```markdown
## 3.5. Split for 3D Printing

The enclosure is split lengthwise at X=0 into right (chassis) and left (cover) halves for FDM printing.

### 3.5.1. Why Split?
- Printing a hollow octagonal tube upright produces excessive internal support material
- Two half-shells print flat on the bed with no supports needed
- All electronics mount on one half (chassis), making assembly and battery replacement easy

### 3.5.2. Split Plane: X=0
- **Right half (X>0) — Chassis:** Large button, power button, USB-C, LEDs, battery cradle, all electronics
- **Left half (X<0) — Cover:** Purely mechanical shell, snaps onto chassis
- Front-face features (speaker grille, mic) are split between halves at X=0
- Mic hole shifted to x=+1mm so it's fully on the chassis half
- Print each half with the outer flat face (long side) down on the bed
```

- [ ] **Step 2: Update snap-fit section comments**

In section 3.5.3, update the description to reference cover/chassis and front/back walls instead of front/back halves and left/right walls. Update 3.5.3.1 to say rails are on front/back wall seams. Update 3.5.3.2 to say clips are on front/back walls with beams on cover half, pockets in chassis half.

- [ ] **Step 3: Remove or update the Battery Compartment section (3.4)**

Replace:

```markdown
## 3.4. Battery Compartment

**Status:** Removed for now (hollow interior provides space)
- Placeholder function exists in code
- TODO: Design proper battery holder, contacts, and wire routing when needed
- 18650 battery (18.6mm × 65mm) fits comfortably in 35mm interior space
```

With:

```markdown
## 3.4. Battery Compartment

- 18650 battery (18.6mm × 65mm) held by half-cylinder cradle ribs on chassis (right) half
- 3 ribs at Z positions near bottom, middle, and top of battery zone
- Rib inner radius: 9.5mm (battery radius + 0.2mm clearance), thickness: 1.5mm
- Cover half provides the other 180° containment when snapped on
- Positive contact at top, negative spring at bottom interior of chassis half
- Entire electrical path stays on chassis half — no cross-joint wiring
```

- [ ] **Step 4: Update LED section in enclosure-spec.md**

In section 1.2.2.1 (Three small LEDs), update to reflect two RGB LEDs at new positions:

Replace the LED subsection title and content to describe 2x WS2812B-2020 at x=+5mm and x=+11mm, 3mm holes, 10mm from top.

- [ ] **Step 5: Commit**

```bash
git add context/enclosure-spec.md
git commit -m "Update enclosure spec for snap-fit redesign"
```

---
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

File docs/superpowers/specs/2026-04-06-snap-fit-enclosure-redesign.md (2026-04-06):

# Snap-Fit Enclosure Redesign

## Summary

Redesign the DevAIs enclosure from a front/back split with threaded bottom lid to a left/right split with snap-fit closure. This eliminates the threaded lid, simplifies battery access, and consolidates all electronics onto one half.

## Motivation

The original design required a threaded screw-on lid at the bottom for battery replacement, which created an unsolved problem: how to electrically connect the battery negative terminal through a removable lid to the main circuit. By splitting the enclosure left/right instead of front/back, one half becomes a chassis holding all electronics and battery contacts, and the other half is a purely mechanical cover. Battery replacement = pop the cover off.

## Split Orientation

- **Split plane:** X=0 (previously Y=0)
- **Right half (X > 0):** Chassis — all electronics, battery, buttons, ports mount here
- **Left half (X < 0):** Cover — purely mechanical shell, snaps onto chassis
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

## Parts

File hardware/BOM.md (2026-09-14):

# Devais parts list — 13 September 2026

Companion to [`pcb/DESIGN.md`](pcb/DESIGN.md) revision 2. Quantities are per
unit; the ordering plan in section 9 scales them to ten sets with spares.
Prices are researched unit prices and change. **Verified** means the part
number, package and key data were read from the manufacturer or distributor
page on 2026-09-13 (`docs/research/2026-09-13-*.md`). **Verify** means the
part number or supplier code was not confirmed and must be checked before
ordering.

Build method: bare boards from JLCPCB, all assembly by hand with a hot plate,
solder paste and JLCPCB stencils. Design rules that follow from this: no
passive smaller than 0603, no package with underside-only terminations except
the radio module and the microphone (both are reflowed on the plate), and no
part smaller than a SOT-23-6 without a stencil aperture. Parts come from
LCSC (one order) and DigiKey (module, contacts, cables, thermistor; delivered
duty paid to Norway).

**Open item: radio module.** The MDBT50Q-1MV2 has 61 underside pads at
0.4 mm spacing, 28 of them in inner rows, so it is reflow-only and cannot be
inspected after soldering. The only edge-castellated alternative found is the
MinewSemi MS88SF2 (1.10 mm pitch, DigiKey Marketplace, about $8), but it has
no separate VBUS pad: USB power is tied to VDDH inside the module, which
does not suit the charger's 4.4 V system rail. See
`docs/research/2026-09-13-nrf-module-castellated.md`. Decision deferred to
the 25-unit run; prototypes use the XIAO (`PROTOTYPE.md`).

## 1. Main PCB (4 layers, 26 × 126 × 1.6 mm)

| Ref | Part | Package | Qty | Source | Status |
|---|---|---|---|---|---|
| U1 | Raytac MDBT50Q-1MV2 (see open item above) | LGA-61, reflow only | 1 | DigiKey 3271-MDBT50Q-1MV2-ND, $6.15; LCSC C5118826 has no stock | Verified |
| U2 | TI BQ24074RGTR | QFN-16 with thermal pad | 1 | LCSC C54313, $1.45 | Verified |
| U3 | DW01A | SOT-23-6 | 1 | LCSC C351410 | Verified |
| Q3 | FS8205A dual N-FET | SOT-23-6 | 1 | LCSC C2830320 | Verified |
| U4 | MAX98357AETE+T | TQFN-16 3×3 with thermal pad | 1 | LCSC C910544, $0.89 | Verified |
| F1 | PPTC, 2.0 A hold, 6 V or higher (e.g. Littelfuse 1812L200) | 1812 | 1 | LCSC | Verify part and code |
| Y1 | 32.768 kHz crystal, 12.5 pF, ±20 ppm | 3215 | 1 | e.g. Epson FC-135R or Seiko SC-32S | Verify part and LCSC code |
| J_BAT | JST B2B-PH-SM4-TB | PH top-entry SMT | 1 | LCSC C160352 | Verified |
| J_USB | JST SM08B-SRSS-TB | SH side-entry SMT | 1 | LCSC | Verify code |
| J_MIC | JST SM04B-SRSS-TB | SH side-entry SMT | 1 | LCSC C160404 | Verified |
| J_LED | JST SM07B-SRSS-TB | SH side-entry SMT | 1 | LCSC | Verify code |
| J_PTT, J_PWR, J_SPK, J_NTC | JST SM02B-SRSS-TB | SH side-entry SMT | 4 | LCSC C160402 | Verified |
| SWD | Tag-Connect TC2030-NL footprint | pads only | 1 | no part | |
| C | 10 µF 10 V X5R | 0603 | 4 | LCSC | VDD, VDDH, BAT, spare |
| C | 22 µF 10 V X5R | 0805 | 2 | LCSC | SYS at charger OUT, amplifier VDD |
| C | 4.7 µF 10 V X5R | 0603 | 1 | LCSC | Module VBUS |
| C | 1 µF 25 V X5R | 0603 | 1 | LCSC | Charger IN |
| C | 100 nF 16 V X7R | 0603 | 8 | LCSC | Decoupling, button RC, reset, DW01A |
| C | 12 pF C0G | 0603 | 2 | LCSC | Crystal load; confirm against Y1 |
| R | 890 Ω 1 % | 0603 | 1 | LCSC | ISET, 1.0 A charge |
| R | 1.33 kΩ 1 % | 0603 | 1 | LCSC | ILIM, 1.2 A input (harness contacts are rated 0.7 A, doubled) |
| R | 71.5 kΩ 1 % | 0603 | 1 | LCSC | TMR |
| R | 620 kΩ 1 % | 0603 | 1 | LCSC | Amplifier SD_MODE |
| R | 100 kΩ | 0603 | 5 | LCSC | Charger pull-downs and pull-ups |
| R | 10 kΩ | 0603 | 3 | LCSC | Button pull-ups, reset pull-up |
| R | 1 kΩ | 0603 | 5 | LCSC | Button series, DW01A CS, red LED series |
| R | 560 Ω | 0603 | 4 | LCSC | Green and blue LED series |
| R | 100 Ω | 0603 | 1 | LCSC | DW01A VCC |
| R | 33 Ω | 0603 | 4 | LCSC | I2S and PDM clock series |
| R | 2.2 Ω | 0603 | 1 | LCSC | Module VBUS series |
| R | 0 Ω | 0603 | 2 | LCSC | USB D+/D− (footprints for 27 Ω) |
| R | unpopulated | 0603 | 2 | | GAIN_SLOT options |
| — | Screws M2 × 5 mm, plastic thread | | 6 | local | PCB mounting; head ≤ 4.5 mm diameter, ≤ 1.8 mm tall |

## 2. USB-C daughterboard (13 × 6.6 × 1.0 mm)

| Ref | Part | Package | Qty | Source | Status |
|---|---|---|---|---|---|
| J1 | GCT USB4105-GF-A-120, 16 contacts, 20,000 cycles, THT shell stakes 1.2 mm | | 1 | LCSC C5184243, $0.53 | Verified; plain -GF-A (C3020560) is out of stock |
| J2 | JST SM08B-SRSS-TB | SH side-entry SMT | 1 | LCSC | Verify code |
| R1, R2 | 5.1 kΩ 1 % | 0603 | 2 | LCSC | Rd; 1 % is required for the CC thresholds |
| D1 | ST USBLC6-2SC6 | SOT-23-6 | 1 | LCSC C7519 | Verified; also clamps VBUS through pin 5 |
| C1 | 1 µF 25 V X5R | 0603 | 1 | LCSC | |

The separate VBUS TVS (ESD441, DFN0603) is dropped: the package cannot be
hand-placed reliably and the USBLC6 covers VBUS. Fallback receptacle if
USB4105 stock disappears: HRO TYPE-C-31-M-12, LCSC C165948, 10,000 cycles.

## 3. Microphone daughterboard (15 × 8 × 1.6 mm)

| Ref | Part | Package | Qty | Source | Status |
|---|---|---|---|---|---|
| U1 | TDK InvenSense T3902, order code MMICT390200012, PDM, bottom port | LGA-5, 3.5 × 2.65 × 0.98 mm | 1 | LCSC C3171752, $1.29 at 10, 8,000 in stock | Verified |
| C1 | 100 nF 10 V X7R | 0603 | 1 | LCSC | At pin 5 (VDD) |
| R1 | 100 Ω | 0603 | 1 | LCSC | In series with DATA |
| J1 | JST SM04B-SRSS-TB | SH side-entry SMT | 1 | LCSC C160404 | Verified |

Pins: 1 DATA, 2 SELECT, 3 GND, 4 CLK, 5 VDD. Supply 1.65–3.63 V from the
module's VDD. Standard-mode clock 1.0–3.3 MHz, so the nRF52840 default
1.032 MHz works; 430 µA running, 12 µA with the clock below 200 kHz. PCB
sound hole 0.5–1.0 mm. Fallback: MEMSensing MSM261DDB019, LCSC C51928210,
same package, but its normal mode starts at 1.1 MHz, so the nRF PDM clock
must be set to 1.280 MHz with Ratio80.

## 4. LED daughterboard (12 × 8 × 1.6 mm)

| Ref | Part | Package | Qty | Source | Status |
|---|---|---|---|---|---|
| D1, D2 | 3 mm common-anode RGB LED, diffused lens, through-hole | 3 mm, 4 leads | 2 | DigiKey or LCSC | Verify part |
| J1 | JST SM07B-SRSS-TB | SH side-entry SMT | 1 | LCSC | Verify code |

## 5. Off-board parts

| Item | Part | Qty | Source | Status |
|---|---|---|---|---|
| Cell | Samsung INR18650-35E, unprotected flat top, 3350 mAh min, 65.25 mm max, Ø18.55 mm max | 1 | batterionline.no, NOK 87.95 | Verified |
| Negative contact | Keystone 5201 coil spring with solder tab | 1 | DigiKey 36-5201-ND, $0.27 | Verified; 72.0 mm compartment with 5223 |
| Positive contact | Keystone 5223 button with solder tab | 1 | DigiKey 36-5223-ND, $0.14 | Verified |
| Cell thermistor | Semitec 103AT-2, 10 kΩ ±1 %, B = 3435 K, leaded bead | 1 | DigiKey (product 16579059) | Verified |
| Cell straps | HellermannTyton T18R cable tie, 100 × 2.5 mm | 2 | TME or Farnell | Verified |
| Speaker | Same Sky CMS-2053-18SP, 20 × 5.3 mm, 8 Ω, 1.5 W, solder pads | 1 | DigiKey 22521372 | Verified; the enclosure now models this depth |
| PTT and power switches | Omron B3F-1000, 6 × 6 × 4.3 mm, 100 gf | 2 | LCSC C93157, $0.17 | Verified |
| Closure screws | M2 × 6 mm, plastic thread | 2 | local | |
| Speaker bridge screws | M2 × 5 mm | 2 | local | |
| Adhesive | 3M VHB or 3M 9448 double-sided tape, 0.15 mm; thin strips for switch, mic and LED boards | shared | local | |
| Speaker gasket | 1 mm closed-cell foam ring, Ø20/Ø18 | 1 | cut from sheet | |
| Filament | PETG for shells and carriers; TPU for button caps | | on hand | |

## 6. Harnesses

Ready-made JST SR harnesses, which mate with the SH headers. They are IDC
assemblies with 30 AWG UL1571 wire (0.55 mm insulation), black only, contacts
rated 0.7 A. Suffix A is JST's "pin 1 to pin 1" wiring; DigiKey labels the
same part "Reversed" because one housing is flipped, so buzz out one cable
before wiring the first board. No crimping is needed; a damaged cable is
replaced, not re-terminated.

| Harness | Part | Qty | Source | Status |
|---|---|---|---|---|
| USB, 8-way, 102 mm | JST A08SR08SR30K102A | 1 | DigiKey, $1.90, 2,220 in stock | Verified |
| LED, 7-way, 102 mm | JST A07SR07SR30K102A | 1 | DigiKey, $1.81, 486 in stock | Verified |
| Mic, 4-way, 152 mm | JST A04SR04SR30K152A (102 mm is out of stock) | 1 | DigiKey, $1.53 | Verified |
| PWR, PTT, SPK, NTC: 2-way, 152 mm, cut in half, cut end soldered to the switch, speaker or thermistor | JST A02SR02SR30K152A | 2 | DigiKey | Verify code (102 mm A02SR02SR30K102A is verified at $1.12) |
| BAT+ and BAT−, PH 2-way plug, 24 AWG | JST ASPHSPH24K305, cut to 65 and 165 mm, cut ends soldered to the contact tabs | 1 | DigiKey 455-3082-ND, $0.50 | Verified |
| PH housing 2-way | JST PHR-2 | 1 | LCSC C157955 | Verified |
| PH contact | JST SPH-002T-P0.5S | 2 | LCSC C111515 | Verified |
| Heat-shrink 1.5 mm and 3 mm | for pin-1 marking and the NTC joints | | local | |

Cut lengths follow `pcb/DESIGN.md`. If a cable must be re-terminated after
all, the SH crimp contact is SSH-003T-P0.2-H (LCSC C263995) with an Engineer
PAD-11 crimper; the PA-09 does not fit SH contacts.

## 7. Tools and consumables

| Item | Note |
|---|---|
| Hot plate, 100 mm PTC type | The 30 mm MHP30 cannot cover a 126 mm board |
| Solder paste Sn42Bi58 (138 °C) in a syringe | Low-temperature paste keeps the plate and the parts cool; store refrigerated |
| Stencils from JLCPCB, one per board type | Frameless, order with the boards; the LED board needs none |
| Flux pen or gel, isopropanol, lint-free wipes | |
| Fine tweezers, USB microscope or 10× loupe | The module and QFN pads cannot be checked by eye |
| Temperature-controlled iron, 0.6 mm chisel tip | Through-hole LEDs, contacts, switches, wire ends |
| SWD probe with Tag-Connect TC2030-IDC-NL cable | First bootloader flash and recovery |
| Bench supply with current limit, USB current meter | Bench checks in `pcb/DESIGN.md` |

## 8. Ordering plan for ten sets

From `docs/research/2026-09-13-pcba-cost.md` section 10. Estimates, not
quotes; VAT is collected at checkout by JLCPCB and DigiKey when a parcel is
under NOK 3 000, which all of these are.

| Order | Contents | USD incl. VAT | NOK |
|---|---|---|---|
| JLCPCB | Main board 10 pcs 4-layer; USB, mic and LED boards 10 pcs each as three separate 2-layer orders (the mic and LED boards are under JLCPCB's 10 mm minimum edge and get a rail); three stencils | 163 | 1 500 |
| LCSC | Every section 1–4 part for 12 sets except the module | 196 | 1 800 |
| DigiKey | 12 modules, 10 sets of contacts, thermistors, harnesses, speakers | 101 for modules plus about 250 for the rest | 940 plus about 2 300 |
| batterionline.no | 10 cells | about 95 | 880 |
| One-time reflow kit | section 7 | 155 | 1 430 |

Boards and parts come to about NOK 425 per set before off-board parts. Buy
two spare modules beyond the ten; a reflowed module cannot be reworked.

## 9. Decisions this list depends on

Settled: no external 3.3 V regulator; DW01A protection with PPTC; 1.0 A
charge with a 1.2 A input limit; Keystone 5201/5223 contacts and a 72 mm
cradle; CMS-2053-18SP speaker; 8-way USB harness with CC sensing; hand
assembly of bare boards; schematic capture in tscircuit. Open: the radio
module (castellated alternative under research).

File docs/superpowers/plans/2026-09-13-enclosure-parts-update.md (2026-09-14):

# Enclosure and Assembly Update for Revision 2 Parts — Implementation Plan

> **For agentic workers:** REQUIRED SUB-SKILL: Use superpowers:subagent-driven-development (recommended) or superpowers:executing-plans to implement this plan task-by-task. Steps use checkbox (`- [ ]`) syntax for tracking.

**Goal:** Bring `cad/enclosure.py` and `cad/assembly.py` in line with the parts selected in `hardware/pcb/DESIGN.md` revision 2 and `hardware/BOM.md`, so the next print and the assembly fit report describe the parts that will actually be bought.

**Architecture:** All geometry is parametric CadQuery. `cad/enclosure.py` owns the shells and chassis mounts; `cad/assembly.py` owns purchased-part envelopes, harnesses, printed carriers and the fit checker. Every task changes parameters or envelopes, rebuilds the assembly, and requires `output/full-assembly/fit-report.json` to report `"status": "PASS"` with an empty `errors` list. There is no separate unit-test suite for geometry; the build is the test.

**Tech Stack:** Python 3.14, CadQuery 2.8, run with `.venv/bin/python` from the repository root. `cad/test_assembly.py` is a small regression check of the harness and collision helpers.

**Spec:** `hardware/pcb/DESIGN.md` (section "Mechanical updates required by this revision") and `hardware/BOM.md`.

## Global Constraints

- Do not commit. The working tree already carries uncommitted LED-position changes (X = 0 and 6) from another session. Leave them in place and build on them. Each task ends with a passing build and `git diff --stat`.
- Dimensions in millimetres. Enclosure coordinates: X toward the control face, Y negative toward the front (audio) face, Z up. Front wall inner face is at Y = −18.4, outer at Y = −20.
- The assembly build is slow (minutes). Run it once per task, in the foreground, with a 10 minute timeout: `.venv/bin/python -m cad.assembly`. A passing run prints `Static fit passed; checking cover and button travel` then writes `status: PASS`. Also run `.venv/bin/python -m cad.test_assembly` after any change to `harness()`.
- Preview renders (`.venv/bin/python -m cad.preview <stl>`) need host display access; if the sandboxed run fails on Cocoa/AppKit, retry with escalated permissions. Geometry assertions are real failures, not sandbox failures.
- Keep comments short and factual. Update the three documents that describe these parameters in the same task that changes them: `cad/ASSEMBLY.md`, `context/enclosure-work.md`, `output/README.md`.
- Do not change the PCB outline, mounting holes, the seam, the button openings or the USB wall opening.

---

### Task 1: Speaker CMS-2053-18SP (5.3 mm deep) and the bridge

**Files:**
- Modify: `cad/enclosure.py` (constants near line 96, speaker cup in `add_component_mounts` near line 493)
- Modify: `cad/assembly.py` (speaker cylinder near line 142, bridge near lines 277–296)
- Modify: `cad/ASSEMBLY.md` placement table, `context/enclosure-work.md` internal mounts, `output/README.md` speaker paragraph

**Interfaces:**
- Produces: `e.SPEAKER_BODY_DEPTH = 5.3` used by later tasks for clearance; the bridge geometry is local to `build()`.

- [ ] **Step 1: Change the speaker depth and the cup length**

In `cad/enclosure.py`:

```python
SPEAKER_BODY_DIAMETER = 20.0
SPEAKER_BODY_DEPTH = 5.3  # Same Sky CMS-2053-18SP; the 4.0 mm CMS-2004 also fits
```

In `add_component_mounts`, make the cup ring cover the whole speaker body plus 1 mm:

```python
    cup = cq.Workplane('XZ', origin=(0,-18.9,z)).circle(
        SPEAKER_BODY_DIAMETER/2+2).circle(SPEAKER_BODY_DIAMETER/2+MOUNT_CLEARANCE).extrude(-(SPEAKER_BODY_DEPTH+1.5))
```

(The 'XZ' workplane normal points to −Y, so a negative extrude runs toward +Y, into the cavity. The old value −5.0 covered a 4 mm speaker plus 1 mm.)

- [ ] **Step 2: Use the constant for the speaker envelope in the assembly**

In `cad/assembly.py` replace the hard-coded 4:

```python
    add('speaker',cylinder(10,e.SPEAKER_BODY_DEPTH,(0,-18.3,SPEAKER_Z),(0,1,0)),'#50565e')
```

- [ ] **Step 3: Move the bridge plate clear of the deeper speaker**

The speaker rear face is now at Y = −18.3 + 5.3 = −13.0. The bridge plate must sit at least 0.6 mm behind it, so its front face is at Y ≥ −12.4. The existing bridge is a single box at Y = −13.7 (spanning −14.3…−13.1) with a step toward the PCB and two ears at Y = −15.5 that screw into the lugs. Rebuild it as:

1. A plate over the speaker: `box((23.9,1.2,3),(-2.55,-11.8,bridge_z))` (spans Y −12.4…−11.2).
2. Two risers joining the plate to the ears and to the PCB-side step, each spanning Y from −14.3 to −11.2, placed where they are outside the speaker clearance cylinder (radius 10.3 about the speaker axis at Z = `SPEAKER_Z`). One riser on the left at X ≈ −13.25 (width 2.5) and one on the right at X ≈ 9.7 (width 0.6 is too thin; instead raise `bridge_z` to `SPEAKER_Z + 7` so the speaker half-width at the bridge is under 8.7 mm and a 1.6 mm wide riser at X 8.8…10.4 fits). Keep the ear cylinders at (±12, −15.5) and the step pieces `box((2.5,1.2,3),(10.65,-14.0,bridge_z))` and `box((2.6,1.2,3),(13.2,-13.7,bridge_z))` as they are, since they clear the PCB slab (Y ≥ −13) and the rail at Y −12.25…−7.75, X 11.5…16.3.
3. Cut the speaker clearance cylinder `cylinder(10.3, 8, (0,-19,SPEAKER_Z), (0,1,0))` from the bridge so nothing intrudes into the speaker.

Then re-derive the chassis features that depend on `bridge_z` (lug height, ear pilot cuts, the bridge rebate) — they already use the `bridge_z` variable, so raising it moves them together. Check that the lugs still intersect the chassis wall and the cup and do not reach the LED seat, whose lower edge is at Z = 134.

- [ ] **Step 4: Build and check**

Run: `.venv/bin/python -m cad.assembly`
Expected: `Static fit passed; checking cover and button travel`, then `status: PASS` in `output/full-assembly/fit-report.json`. If the report lists an overlap between `speaker_bridge` and `speaker`, `main_PCB`, the rails (`chassis`) or the LED seat, adjust the riser positions and rebuild. Do not add contact exceptions.

- [ ] **Step 5: Update the documents**

- `cad/ASSEMBLY.md` placement table, Speaker row: `Ø20 × 5.3 mm envelope (CMS-2053-18SP)`.
- `context/enclosure-work.md` internal mounts: `Speaker envelope 20 diameter x 5.3 deep`.
- `output/README.md`: same figure in the speaker paragraph.

- [ ] **Step 6: Report**

Run: `git diff --stat`
Report the bridge geometry you ended up with (plate Y, `bridge_z`, riser positions).

---

#### Task 1c: Bridge plate continuity (rev 2, 2026-09-14)

The plate (Y −12.4…−11.2, Z `bridge_z` ± 1.5) already sits behind the speaker body (back face Y −13.0) with a 0.6 mm standoff, so it needs no speaker clearance. The cut on the bridge, `cylinder(10.3,8,(0,-19,SPEAKER_Z),(0,1,0))`, runs Y −19…−11 and removes the plate to a 0.2 mm ribbon at X = 0. Shorten that one cut so it ends 0.1 mm short of the plate front face and only clears the risers and steps, which reach forward into the body's Y range:

```python
    bridge=bridge.cut(cylinder(10.3,6.5,(0,-19,SPEAKER_Z),(0,1,0)))  # Y -19..-12.5
```

Leave `bridge_z = SPEAKER_Z+9`, the lug cut on line 265 (lugs sit inside the body's Y range) and everything else unchanged. Update the comment above the bridge so it says the plate holds the top 2.5 mm of the speaker's back face. Expected: `speaker_bridge` builds as one solid 23.9 × 1.2 × 3 plate plus risers, steps and ears; the speaker-to-plate gap stays 0.6 mm; fit report PASS with no new contacts. Re-render the previews touched by Task 5 that show the bridge.

### Task 2: Plain 3 mm RGB LEDs, 12 × 8 mm LED board, 7-position header

**Files:**
- Modify: `cad/enclosure.py` (`LED_DIAMETER` line 22, `LED_BOARD_WIDTH` line 95, docstring of `add_led_holes`)
- Modify: `cad/assembly.py` (LED emitters and socket near lines 135–141, `LED_SOCKET_X` line 27, header probe near line 290, `harness()` offsets line 66–69, LED route line 254)
- Modify: `cad/ASSEMBLY.md`, `context/enclosure-work.md`, `output/README.md`

**Interfaces:**
- Produces: `harness()` accepts `count` in {1,2,3,4,7,8}; Task 3 relies on the 8-conductor bundle and its `bundle_radius(count, diameter)` helper.

- [ ] **Step 1: Enclosure parameters**

```python
LED_DIAMETER = 3.2  # Through-hole 3 mm LED domes pass the wall; 0.2 mm clearance
...
LED_BOARD_WIDTH, LED_BOARD_HEIGHT = 12.0, 8.0  # Two 3 mm RGB LEDs and a 7-way SH header
```

Change the `add_led_holes` docstring to `2x 3.2 mm holes for 3 mm RGB LEDs at explicit X positions.`

- [ ] **Step 2: Extend `harness()` to 7 and 8 conductors and expose the bundle radius**

Replace the `offsets` dictionary in `harness()` with a helper used by both the harness and the tunnel cut:

```python
def bundle_offsets(count, diameter):
    """Conductor centre offsets in the bundle cross-section; 5+ leads form two rows."""
    pitch = diameter+0.12
    if count <= 4:
        return {1: [(0,0)], 2: [(-pitch/2, 0), (pitch/2, 0)],
                3: [(-pitch/2, -pitch/3), (pitch/2, -pitch/3), (0, pitch*2/3)],
                4: [(x*pitch/2,y*pitch/2) for x in (-1,1) for y in (-1,1)]}[count]
    per_row = (count+1)//2
    xs = [(i-(per_row-1)/2)*pitch for i in range(per_row)]
    offsets = [(x, -pitch/2) for x in xs] + [(x, pitch/2) for x in xs]
    return offsets[:count]

def bundle_radius(count, diameter):
    return max(math.hypot(x, y) for x, y in bundle_offsets(count, diameter)) + diameter/2
```

and in `harness()`:

```python
    offsets = bundle_offsets(count, diameter)
```

In the route loop, replace the tunnel radius expression `1.2 if count==4 else 1.02` with `bundle_radius(count, od)+0.3`.

Extend `cad/test_assembly.py` with one check after the existing harness assertions:

```python
    wires8, _ = harness([(0, 0, 0), (0, 0, 20), (0, 20, 20)], 8, .8)
    assert len(wires8) == 8
    assert all(a.intersect(b).Volume() < 1e-5 for a, b in combinations(wires8, 2))
```

(add `harness` is already imported; nothing else to import.)

Run: `.venv/bin/python -m cad.test_assembly`
Expected: `Cable bend and collision regression checks passed`

- [ ] **Step 3: LED envelopes, socket and route**

Replace the two LED emitter boxes with a flange plus dome per LED, and widen the socket to a 7-way SH plug (header 9.0 mm wide; use the same 0.5 mm side allowance as the other SH envelopes):

```python
LED_SOCKET_X = e.LED_BOARD_X  # 7-way header centred on the 12 mm board
...
    add('LED_J_SH_mated',box((9.5,3,8.5),(LED_SOCKET_X,-13.75,139.75)),'#edba65')
    for x in e.LED_POSITIONS_X:
        # 3 mm through-hole RGB LED: 1 mm flange on the board face, dome through the wall.
        flange=cylinder(1.9,1.0,(x,-16.85,140),(0,-1,0))
        dome=cylinder(1.5,4.4,(x,-17.85,140),(0,-1,0))
        add(f'LED_{x}',flange.fuse(dome),'#eee6ab')
```

The dome ends at Y = −22.25, 2.25 mm proud of the outer face; that is intended for V1. Update the header probe to the new width:

```python
                        ('LED_PCB',box((9.5,.1,5.5),(LED_SOCKET_X,-15.3,141.25))),
```

Change the LED route to 7 conductors:

```python
        'LED': (7, WIRE_OD, [(8.4,-9,118.25),(4,-9,118.25),(4,-9,127),(LED_SOCKET_X,-9,132),(LED_SOCKET_X,-13.75,132),(LED_SOCKET_X,-13.75,135.5)], 'J_LED','LED_J_SH_mated'),
```

The J_LED allocation in `hardware/pcb/design.py` (`("J_LED", -9, 123, 5.5, 5.5, 3.0, "connector")`) must grow to the 7-way header: change its width to `9.5`. Rerun `.venv/bin/python hardware/pcb/design.py` and confirm it passes (it asserts screw clearance and overlaps); if J_LED now collides with `SWD PADS` or the module keep-out, move `SWD PADS` to `u = 9, Z = 118` and rerun.

- [ ] **Step 4: Build and check**

Run: `.venv/bin/python -m cad.assembly`
Expected: PASS. Watch for `LED_J_SH_mated` against `chassis` (the LED seat window is `w-2` wide, so the 12 mm board gives a 10 mm window) and for the domes against the chassis hole edges: a 3.0 mm dome in a 3.2 mm hole must show a gap of about 0.1 mm, not an overlap. If a dome overlaps the wall, check that `LED_POSITIONS_X` and the emitter X positions are the same values.

- [ ] **Step 5: Update the documents**

- `cad/ASSEMBLY.md` LEDs row: `Custom 12 × 8 × 1.6 mm board with two 3 mm RGB LEDs and a 7-way SH header; emitters at the LED_POSITIONS_X values, Z = 140.`
- `context/enclosure-work.md`: LED holes `3.2 diameter`; daughterboard seats `LEDs 12 x 8 x 1.6`.
- `output/README.md`: same two figures.

- [ ] **Step 6: Report**

Run: `git diff --stat`
Report the LED dome-to-wall gap from `fit-report.json` `near_pairs`.

---

### Task 3: USB daughterboard with 8-way header and 8-conductor harness

**Files:**
- Modify: `cad/assembly.py` (USB board/socket/shoe near lines 146–162, USB route line 250, USB probe line 291)
- Modify: `cad/ASSEMBLY.md` USB-C row

**Interfaces:**
- Consumes: `bundle_radius()` from Task 2.

- [ ] **Step 1: Widen the mated 8-way plug and the shoe pocket**

The 8-way SH header is 10.0 mm wide; the plug envelope gets the same 0.5 mm per side allowance the others use. The shoe pocket must clear it.

```python
    add('USB_J_SH_mated',box((6.5,11.0,3),(15.1,0,26.845)),'#edba65')
    # Shoe supports board edges and rear of socket. Front/back stops take insertion load.
    shoe=box((7.7,16,1.5),(15.65,0,27.595))
    shoe=shoe.cut(box((6.2,12.0,4),(15.8,0,27.6)))
```

The board stays 13 mm wide (`USB_PCB` box unchanged) and the side walls at y = ±7.25 stay. Update the probe so it checks the full 10 mm header bearing area:

```python
                        ('USB_PCB',box((6.5,10.0,.1),(15.1,-1.5,28.395)))]:
```

- [ ] **Step 2: Eight conductors on the USB route**

```python
        'USB': (8, WIRE_OD, [(8.4,4,16.25),(8.4,4,11.5),(8.4,14.5,11.5),(13.9,14.5,11.5),(13.9,14.5,26.845),(15.3,4.25,26.845)], 'J_USB','USB_J_SH_mated'),
```

The tunnel through the chassis and the shoe is cut with `bundle_radius(8, WIRE_OD)+0.3` (about 2.3 mm) by the code from Task 2. The J_USB allocation in `hardware/pcb/design.py` (`("J_USB", 4, 31, 6.5, 5.5, 3.0, "connector")`) becomes width `10.5`; rerun `.venv/bin/python hardware/pcb/design.py` and confirm it passes. If J_USB now collides with the `J_MIC` or `J_PWR` allocations or a screw head, shift J_USB to `u = 2` first, then `J_MIC` to `u = -6`, and rerun.

- [ ] **Step 3: Build and check**

Run: `.venv/bin/python -m cad.assembly`
Expected: PASS. Watch `wire_USB_*` against `cell_18650` (the bundle runs beside the cell at X = 8.4, cell surface at X = 6.3) and against `main_PCB`. If a conductor touches the cell, move the first two waypoints from X = 8.4 to X = 8.0 and rebuild; the PCB inward face is at X = 9.9, so the bundle centre must stay at X ≤ 9.9 − 2.3.

- [ ] **Step 4: Update the document**

`cad/ASSEMBLY.md` USB-C row: `... custom 13 × 6.6 × 1 mm horizontal board with an 8-way SH header on its underside ...`.

- [ ] **Step 5: Report**

Run: `git diff --stat`
Report the tunnel radius and the USB bundle's nearest gap.

---

### Task 4: Battery contacts, cradle length, positive collar and lead insulation

**Files:**
- Modify: `cad/enclosure.py` (`CONTACT_SPACE` line 91, contact carriers near lines 474–479)
- Modify: `cad/assembly.py` (`BAT_WIRE_OD` line 20, contact envelopes near lines 226–229)
- Modify: `cad/ASSEMBLY.md` Battery row and adjustable-parameter table, `context/enclosure-work.md`, `output/README.md`

- [ ] **Step 1: Cradle inside length 72.0 mm**

Keystone's installed length for the 5201 spring with the 5223 button is 71.6 mm for a 65.0 mm cell; real cells are up to 65.3 mm.

```python
CONTACT_SPACE = 3.5  # Keystone 5201 spring + 5223 button: 72.0 mm inside for a 65.0 cell
# Reverse-insertion collar on the positive carrier: a ring around the 5223 plate
# whose underside sits POSITIVE_COLLAR_DROP below the button tip. A reversed cell's
# flat end stops on the ring; the correct cell's raised cap passes through the
# opening. Requires cap protrusion > POSITIVE_COLLAR_DROP (measure the 35E cap and
# the 5223 button before printing; tune POSITIVE_COLLAR_DROP).
POSITIVE_COLLAR_ID = 12.0  # clears the Ø8 cell cap and the Ø11 insulating washer
POSITIVE_COLLAR_DROP = 0.4
POSITIVE_COLLAR_HEIGHT = 0.5 + 1.0 + POSITIVE_COLLAR_DROP  # plate + button + drop, from the carrier face
POSITIVE_PLATE_POCKET = (11.6, 0.6)  # X width and depth of the 5223 plate pocket in the collar top
```

Rev 2 (2026-09-14, after the Task 4 review): the rev 1 collar (0.6 mm tall, ID 9.0, hung from the carrier face) sat in the same 0.5 mm Z band as the 5223 plate, so it interpenetrated the plate, and its underside was 0.9 mm above the button tip, so a reversed cell met the button before the ring. The collar now surrounds the plate instead of sitting under it and reaches past the button tip.

In `add_component_mounts`, after the two carriers are added, add the collar on the positive (top, Z = `BATTERY_BOTTOM_Z+BATTERY_LENGTH+CONTACT_SPACE` = 88.5) carrier face, protruding down toward the cell, with a pocket for the plate cut into its top:

```python
    top = BATTERY_BOTTOM_Z+BATTERY_LENGTH+CONTACT_SPACE
    collar = (cq.Workplane('XY').center(BATTERY_CENTER_X, 0)
              .circle(BATTERY_DIAMETER/2+BATTERY_CLEARANCE).circle(POSITIVE_COLLAR_ID/2)
              .extrude(POSITIVE_COLLAR_HEIGHT).translate((0, 0, top-POSITIVE_COLLAR_HEIGHT)))
    # Only the part under the carrier footprint has something to hang from.
    collar = collar.intersect(cq.Workplane('XY').box(14,22,POSITIVE_COLLAR_HEIGHT).translate(
        (BATTERY_CENTER_X,-8,top-POSITIVE_COLLAR_HEIGHT/2)))
    # Pocket for the 11.2 x 12.0 plate, open toward +Y for the solder tab.
    pw, pd = POSITIVE_PLATE_POCKET
    pocket = cq.Workplane('XY').box(pw,30,pd).translate((BATTERY_CENTER_X,-6.2+15,top-pd/2))
    chassis = chassis.union(collar.cut(pocket))
```

Resulting geometry: ring r 6.0..9.6, Z 86.6..88.5, clipped to X ±7 and Y ≤ 3 about the cell axis; pocket X ±5.8, Y ≥ −6.2, Z 87.9..88.5. The plate (Z 88.0..88.5) bears on the carrier face with 0.1 mm above the pocket floor and 0.2 mm to the pocket walls; the button (Ø5, tip Z 87.0) hangs in the Ø12 opening; the washer (r 5.5, Z 87.7..87.9) clears the ring by 0.5 mm radially. The cell envelope (top Z 85) is 1.6 mm below the ring. The BAT_POS lead's last segment at X = −3, Y 2..8, Z 86.5 lies inside the opening and outside the Y ≤ 3 clip, so it does not touch the ring. Confirm each of these in the fit report rather than assuming them.

Axial float: inside length 72.0 for a 70.0 stack (cell 65.0 + spring end 3.5 + button end 1.5), so the spring lifts the real cell up to 2.0 mm above the `cell_18650` envelope until its cap meets the button. Document this in `cad/ASSEMBLY.md`; do not change geometry for it.

- [ ] **Step 2: Contact envelopes in the assembly**

Replace the two 2 × 2.8 mm cylinders and washers with Keystone envelopes: an 11.2 × 12.0 × 0.5 mm plate on the carrier face, plus a Ø8 × 3.0 mm coil for the spring (5201, compressed) or a Ø5 × 1.0 mm button (5223). Keep the insulating washers.

```python
    for label,z,axis,tip in [('negative',20,(0,0,-1),('coil',4.0,3.0)),('positive',85,(0,0,1),('button',2.5,1.0))]:
        plate=box((11.2,12.0,0.5),(-3,0,z+axis[2]*(3.25)))
        kind,r,length=tip
        contact_body=cylinder(r,length,(-3,0,z+axis[2]*3.0),(0,0,-axis[2]))
        add('cell_'+label+'_contact',plate.fuse(contact_body),'#b9b9b9')
        washer=cylinder(6,.2,(-3,0,z+axis[2]*3.4),axis).cut(cylinder(2.2,.3,(-3,0,z+axis[2]*3.35),axis))
        add('cell_'+label+'_insulator',washer,'#dcad59')
```

Here the carrier faces are at Z = 20 − 3.5 = 16.5 and Z = 85 + 3.5 = 88.5; the plate sits against the face and the coil or button reaches toward the cell end (Z = 20 and 85). The 3.0 mm coil length is the compressed working height, not the 10.5 mm free length. Check the numbers against `e.CONTACT_SPACE` rather than the literals above if the constants differ: plate centre at `z ± (CONTACT_SPACE − 0.25)`, tip starting at `z ± (CONTACT_SPACE − 0.5)`.

The battery lead insulation becomes the 24 AWG pre-crimped PH lead:

```python
BAT_WIRE_OD = 1.4  # JST ASPHSPH24K305, 24 AWG UL1007; not bare copper diameter.
```

Battery route waypoints already start at the J_BAT plug and end at the contact positions (`(-3,2,86.5)` and `(-3,2,18.5)`); if the new plate solids now overlap the wire termination boxes, the existing `contact()` exceptions at the route ends cover a 4 mm cube; confirm the overlap volume is inside it, otherwise move the last waypoint 0.5 mm away from the plate.

- [ ] **Step 3: Build and check**

Run: `.venv/bin/python -m cad.assembly`
Expected: PASS. Watch `cell_18650` against the collar (the cell envelope ends at Z = 85, the collar starts at Z = 86.6, so there must be no overlap) and the contact plates against the carriers (they touch; allow it with a `contact()` exception named `cell contact plate bears on carrier`, bounded by the plate box). That exception must cover a zero-volume touch only; if the fit report shows an overlap volume between `cell_positive_contact` and `chassis`, the pocket is wrong, not the exception.

Also run `.venv/bin/python -m cad.enclosure` (or `uv run cad-generate`) to regenerate `output/` and confirm its own checks pass.

- [ ] **Step 4: Update the documents**

- `cad/ASSEMBLY.md` Battery row: `Keystone 5201 spring and 5223 button contacts on the end carriers, 72.0 mm inside; a 1.9 mm collar around the positive plate stops a reversed cell 0.4 mm short of the button, provided the cell cap protrudes more than 0.4 mm (measure before printing). The sprung cell can sit up to 2.0 mm above the modelled envelope.` Adjustable parameters table: battery-wire insulation 1.4 mm; `POSITIVE_COLLAR_DROP`.
- `context/enclosure-work.md` and `output/README.md`: cell envelope text gains `contacts Keystone 5201/5223, carriers 3.5 mm beyond each end`.

- [ ] **Step 5: Report**

Run: `git diff --stat`
Report the collar height used, the gap between the cell envelope and the collar, and the plate-to-pocket clearances from the fit report.

---

### Task 5: Regenerate previews and record the fit report

**Files:**
- Modify: `cad/ASSEMBLY.md` (harness table if lengths changed)

- [ ] **Step 1: Rebuild everything once more**

Run: `.venv/bin/python -m cad.enclosure && .venv/bin/python -m cad.assembly && .venv/bin/python -m cad.test_assembly && .venv/bin/python hardware/pcb/design.py`
Expected: all pass; `fit-report.json` status PASS.

- [ ] **Step 2: Render previews**

Run: `.venv/bin/python -m cad.preview output/full-assembly/open.stl output/full-assembly/internals.stl output/full-assembly/*_print.stl output/chassis_print.stl`
(With escalated permissions if the sandbox blocks the display.) Read `output/full-assembly/open_preview.png` and `internals_preview.png` and confirm: the bridge plate sits behind the speaker, two LED domes pass the front wall, the 8-way USB plug sits under the USB board inside the shoe, the two contact plates sit on the cradle ends.

- [ ] **Step 3: Record harness lengths**

Copy the `harnesses` block of `fit-report.json` into the harness table of `hardware/pcb/DESIGN.md` if any centerline changed by more than 2 mm from the values there (USB 43, MIC 48, LED 24, PWR 45, PTT 43, SPK 43, NTC 50, BAT+ 24, BAT− 124).

- [ ] **Step 4: Report**

Run: `git status --short && git diff --stat`
List every file changed and the final `near_pairs` entries under 0.2 mm.

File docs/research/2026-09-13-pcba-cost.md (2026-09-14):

# Cost of two assembled prototype units — Trondheim builder

Date of research: 2026-09-13. All figures from published fee tables and capability pages.
**Nothing here is a quote.** Every line is tagged VERIFIED (source URL) or ESTIMATE.

---

## 0. Constants and conversions

| Item | Value | Status |
|---|---|---|
| USD/NOK | 9.25 (spot range 9.18–9.32, 11 Sep 2026) | ESTIMATE (aggregator, non-authoritative) |
| EUR/USD | 1.17 | ESTIMATE |
| Norwegian MVA (VAT) standard rate | 25 % | VERIFIED — https://www.skatteetaten.no/en/rates/value-added-tax/ |
| Customs duty, bare PCB (HS 8534) and populated assemblies | 0 % | ESTIMATE, high confidence (WTO ITA; toll.no tariff lookup returned 403) |
| VAT de minimis on imports to Norway | none — abolished 1 Jan 2024, VAT due on all imports regardless of value | VERIFIED via secondary source — https://www.vatcalc.com/norway/norway-ends-import-vat-exemption-sales-vat-due-on-imported-b2c-sales-below-nok-3000-voec/ |
| VOEC threshold | NOK 3 000 **intrinsic value per item** (shipping excluded); VOEC seller charges 25 % at checkout and nothing further is due on arrival | VERIFIED — https://www.toll.no/no/netthandel/VOEC , https://www.skatteetaten.no/en/business-and-organisation/vat-and-duties/vat/foreign/e-commerce-voec/register |
| Above NOK 3 000 or non-VOEC seller | ordinary customs clearance: 25 % import VAT + carrier handling fee | VERIFIED (same sources) |

### Carrier customs handling fees (Norway)

| Carrier | Fee | Status |
|---|---|---|
| Posten/Bring, value NOK 0–500 | NOK 46 | VERIFIED — https://www.posten.no/fortolling/motta-fra-utlandet |
| Posten/Bring, value NOK 500–3 000 | NOK 78 | VERIFIED (same) |
| Posten/Bring, value > NOK 3 000 | NOK 278 | VERIFIED (same) |
| Posten/Bring, VOEC shipment | no fee | VERIFIED (same) |
| FedEx disbursement | 30 % of duty/tax, min NOK 139.50; flat NOK 174.50 for tax NOK 582–6 975 (eff. 5 Jan 2026) | ESTIMATE (search synthesis; FedEx page errored on fetch) |
| DHL customs clearance | NOK 50 (DHL-processed) / NOK 120 (third-party); new DHL Express "Clearance Processing" fee from 1 Jan 2026, amount unconfirmed | ESTIMATE |
| UPS | NOK 200–400 | ESTIMATE |

### VOEC registration status of the vendors

| Vendor | Status |
|---|---|
| **JLCPCB** | **VERIFIED VOEC-registered.** "JLCPCB has registered a VOEC ID number and will levy VAT for B2C customers' orders with an intrinsic value not exceeding NOK 3000 at the checkout point starting from June 2024." — https://jlcpcb.com/help/article/Norway-VAT-on-E-commerce-VOEC-Rules |
| PCBWay | NOT VERIFIED — no published statement found either way |
| DigiKey | NOT VERIFIED in this pass (digikey.no tax/shipping pages 404'd). Widely reported as charging Norwegian MVA at checkout; treat as ESTIMATE |
| LCSC | NOT VERIFIED; assumed VOEC-registered — ESTIMATE |
| Aisler | NOT VERIFIED (tax/legal page 404). EU seller, so EU VAT should be removed on export and Norwegian import VAT + Posten handling applies — ESTIMATE |

**Practical consequence:** keep each shipment's intrinsic value under NOK 3 000 (≈ USD 324) and a VOEC-registered vendor collects the 25 % at checkout with **no** carrier handling fee. Exceed it and you pay the same 25 % plus NOK 78–278 handling and a clearance delay.

---

## 1. JLCPCB published fee tables (the backbone of O1, O2, O4)

Source A: https://jlcpcb.com/help/article/pcb-assembly-price (price detail page)
Source B: https://jlcpcb.com/help/article/pcb-assembly-faqs (FAQ, rounded figures)
Source C: https://jlcpcb.com/capabilities/pcb-assembly-capabilities (capability matrix)

| Fee | Economic PCBA | Standard PCBA | Status |
|---|---|---|---|
| Setup fee | $8.18 (FAQ: $8.00) | $25.56 one-sided / $51.12 two-sided | VERIFIED (A, B) |
| Stencil | $1.53 (FAQ: $1.50) | $8.21 one-sided / $16.42 two-sided | VERIFIED (A) |
| SMT assembly, per solder joint | $0.0016 (1–100 000) | $0.0016 (1–50 000) | VERIFIED (A) |
| Manual assembly, per joint | $0.0164 (1–10 000) | $0.0164 | VERIFIED (A) |
| Hand-soldering labour | $3.58 per order | $3.58 per order | VERIFIED (A) |
| **Feeder loading ("extended part") fee** | **$3.07 per unique extended type** (FAQ: "$3 per extended component"); basic parts free | **$1.53 per BOM line, basic and extended alike** | VERIFIED (A, B) |
| Panel fee | $8.21 | $8.21 | VERIFIED (A) |
| X-ray inspection | $1.64/pc at low qty, tiering down to $0.082/pc | same | VERIFIED (A) |
| Minimum per-board surcharge | $0.48 | $0.48 | VERIFIED (A) |
| Large PCB surcharge (> 650 cm²) | $57.46 | $57.46 | VERIFIED (A) |
| Fixture fee | n/a | $8.21–$24.63 | VERIFIED (A) |

**Crossover rule (VERIFIED via https://blog.poly.nomial.co.uk/2025-07-05-tips-for-getting-pcbs-made-with-jlcpcb.html, arithmetic self-consistent with the fee table):** at ≥ 17 distinct *extended* parts, Economic ($3.07/line) costs more than Standard ($1.53/line on every line, but a $25.56 setup). Our main board has ~12 extended lines out of ~28, so Economic is cheaper *on fees alone* — the decision is driven by capability, not price.

### Minimum assembly quantity
**2 pcs.** VERIFIED (C): "Economic PCBA: 2–50 pcs, 1–3 days build time"; Standard PCBA: 2–80 000 pcs, ≥ 4 days. Corroborated by the poly.nomial blog: "a minimum order of 2 PCBs, then it jumps to 5 PCBs" in increments of 5.
Economic is additionally capped at 30 pcs per single board design (VERIFIED, B) — irrelevant at qty 2.

### Economic vs Standard for the castellated radio module — the rule I could and could not verify

- **VERIFIED (C):** Economic PCBA does **not support castellated holes or gold fingers**; Standard PCBA does. This row of the capability matrix describes the *board being fabricated*, and our main PCB has no castellated edge, so it does not by itself force Standard.
- **VERIFIED (C):** X-ray is applied automatically for BGA/QFN/LGA on **both** tiers. We have a QFN-16 and a TQFN-16, so X-ray is charged either way. Economic min IC pitch 0.40 mm, min package 0402 — our QFN-16 (0.5 mm pitch) and 0603s clear this.
- **NOT VERIFIED:** I found no JLCPCB page stating that *placing* a castellated module forces Standard assembly. What is documented is a per-part flag: parts marked "Standard Only" in the JLCPCB library force the whole order to Standard (VERIFIED, poly.nomial; examples given are high-MSL LEDs, some sensors, 0201-and-smaller).
- **Decision for this costing:** the MDBT50Q-1MV2 is an MSL-3 module that will arrive via pre-order or global sourcing (loose, not on tape). Loose/odd-form parts are hand- or manually-placed. **O1 is priced on Standard** as the prudent case, with Economic shown as a lower bound. **Confirm the part's tier flag in the JLCPCB parts library before ordering.**

### Sourcing the out-of-stock radio module

Two published routes, both VERIFIED:

1. **Parts Pre-order** — https://jlcpcb.com/help/article/what-is-jlcpcb-parts-pre-order-service and https://jlcpcb.com/help/article/pcba-parts-sourcing-instruction
   - Lead time **9–15 days** to arrive in JLCPCB's warehouse; parts usable in SMT orders only, never shipped separately.
   - "Non-stock extended parts recommended to the pre-order, **minimum quantity required**." Exact price confirmed within 48 h of initial payment.
   - **Pre-ordered parts cannot be mixed with global-sourcing or consigned parts of the same part number in one PCBA order** (VERIFIED).
2. **Global Sourcing Parts** — https://jlcpcb.com/help/article/global-sourcing-parts-order-terms-conditions and https://jlcpcb.com/help/article/how-to-use-jlcpcb-global-sourcing-parts-service
   - JLCPCB buys from global distributors, priority to local authorised distributors.
   - Lead time **9–20 business days** purchasing + **1–3 business days** review. Unsupported parts cancelled and refunded within 1–7 days.
   - Handling fee: **$0.017/pin for ≤ 5 pins; max $0.078 per component for > 5 pins**; loose parts needing manual assembly $0.078/pc. No shipping charge for the parts themselves.
   - Baking fee $8 for 48 h (relevant: MSL-3 module).
   - Explicit warning: "there will be a slight difference in the price of components compared to oversea platforms."
   - Orders cannot be cancelled or returned after payment.

**R1 — the dominant risk in O1.** LCSC lists C5118826 at zero stock, pre-order ≈ $19 each against a DigiKey price of $6.15. A non-stock extended part carries a **minimum pre-order quantity** (JLCPCB does not publish the number; ESTIMATE 5–10 pcs for a module of this type). At MOQ 10 × $19 that is **$190 of module for two boards** — more than the rest of O1 combined — plus a 2–4 week wait. This single line is why O1's range is wide and why O2/O3 exist.

---

## 2. Board and BOM model used throughout

### Main board — 26 × 126 mm, 4 layers, 1.6 mm, ENIG
Area 32.76 cm²/board; 5 pcs = 163.8 cm² = 0.01638 m².

Solder-joint count (ESTIMATE, derived from package pin counts):

| Part | Qty | Joints each | Joints |
|---|---|---|---|
| MDBT50Q-1MV2 castellated module | 1 | 50 | 50 |
| QFN-16 charger C54313 (+ thermal pad) | 1 | 17 | 17 |
| TQFN-16 amp C910544 (+ pad) | 1 | 17 | 17 |
| SOT-23-6 (C351410, C2830320) | 2 | 6 | 12 |
| PPTC 1812 | 1 | 2 | 2 |
| Crystal | 1 | 4 | 4 |
| JST connectors (avg 4-pin) | 7 | 4 | 28 |
| 0603 passives | 50 | 2 | 100 |
| **Total** | **64** | | **230** |

BOM lines (ESTIMATE): **28 total**, of which **12 extended** (module, charger, amp, 2× SOT-23-6, ~4 unique JST types, crystal, PPTC, 1 spare) and 16 basic.

### Daughterboard panel — ~70 × 70 mm, 2 layers, 1.6 mm
Area 49 cm²/panel; 5 pcs = 245 cm².

| Part | Qty | Joints each | Joints |
|---|---|---|---|
| USB-C receptacle C5184243 (+ shield tabs) | 1 | 20 | 20 |
| SOT-23-6 ESD C7519 | 1 | 6 | 6 |
| DFN ESD C22427765 | 1 | 4 | 4 |
| JST SH headers | 3 | 4 | 12 |
| PDM MEMS mic | 1 | 5 | 5 |
| 0402 passives | 8 | 2 | 16 |
| **Total** | **15** | | **63** |

BOM lines (ESTIMATE): **10 total**, of which **6 extended**.

### Bare-board prices — all ESTIMATE

JLCPCB publishes a 4-layer *board charge* of **$70.6/m²** (reduced from $75.1/m², VERIFIED — https://jlcpcb.com/news/discount-on-quality-4-layer-pcbs) with a worked example of $70.60 board charge → $106.30 total for a 1 m² order, i.e. roughly $35.70 of engineering/test/fixed charge on top. At 0.01638 m² the board charge is **$1.16** and the fixed charges completely dominate; the published m² rate is therefore useless for predicting a 5-pc prototype price, which JLCPCB sets by size tier via an interactive calculator with no static table.

| Item | Price | Status |
|---|---|---|
| Main PCB, 4L, 26×126 mm, 1.6 mm, ENIG, 5 pcs | **$45** (range $40–50) | ESTIMATE — board exceeds the 100×100 mm prototype tier; $25–30 base 4-layer + ~$15–18 ENIG surcharge |
| Daughter panel, 2L, 70×70 mm, ENIG, 5 pcs | **$20** | ESTIMATE — ~$2 in the 2-layer prototype tier + ~$18 ENIG. HASL instead: ~$2–5 |
| Framework-less SMT stencil, main board | **$10** | ESTIMATE |
| Framework-less SMT stencil, daughter panel | **$8** | ESTIMATE |
| JLCPCB shipping, ~0.5 kg to Norway | **$25** (range $15–50) | ESTIMATE — https://jlcpcb.com/shipping is calculator-only, no published table. Global Standard Direct Line ≈ $15–30, DHL/FedEx ≈ $30–50 |

### Component prices — ESTIMATE except where the brief supplied them

Given in the brief (treat as user-supplied VERIFIED): C5118826 pre-order ≈ $19 / DigiKey $6.15; C54313 $1.45; C910544 $0.89; PDM mic assumed $2.
Everything else ESTIMATE: SOT-23-6 $0.40, PPTC $0.15, crystal $0.30, JST connector $0.25, USB-C $0.35, SOT-23-6 ESD $0.05, DFN ESD $0.20, 0603/0402 passive $0.01.

**MOQ padding.** JLCPCB and LCSC sell in package multiples (passives in 50–100 pc strips, small ICs in 5–10 pc minimums). For a 2-board build almost every line is bought at MOQ, not at need. Padding applied: **+$25 main board, +$20 daughter panel** (ESTIMATE).

---

## 3. O1 — JLCPCB full turnkey PCBA, module and mic sourced by JLCPCB

Priced on **Standard PCBA** for the main board (prudent case for a loose, MSL-3 castellated module), **Economic** for the daughter panel. Two separate PCBA orders, each carrying its own setup fee.

### Main board assembly, qty 2 (Standard, one-sided)
| Line | Arithmetic | USD |
|---|---|---|
| Setup fee | — | 25.56 |
| Stencil | — | 8.21 |
| Feeder loading | 28 lines × $1.53 | 42.84 |
| SMT joints | 230 × 2 = 460 × $0.0016 | 0.74 |
| X-ray (QFN/TQFN) | 2 × $1.64 | 3.28 |
| **Subtotal** | | **80.63** |

*Economic equivalent, if the module turns out to be Economic-eligible:* $8.18 + $1.53 + (12 × $3.07 = $36.84) + $0.74 + $3.28 = **$50.57**, i.e. **$30 cheaper**.

### Daughter panel assembly, qty 2 panels (Economic)
| Line | Arithmetic | USD |
|---|---|---|
| Setup fee | — | 8.18 |
| Stencil | — | 1.53 |
| Panel fee | — | 8.21 |
| Feeder loading | 6 extended × $3.07 | 18.42 |
| SMT joints | 63 × 2 = 126 × $0.0016 | 0.20 |
| **Subtotal** | | **36.54** |

### Components
| Line | Arithmetic | USD |
|---|---|---|
| Radio module, pre-order | 2 × $19.00 | 38.00 |
| Charger C54313 | 2 × $1.45 | 2.90 |
| Amp C910544 | 2 × $0.89 | 1.78 |
| 2× SOT-23-6 | 4 × $0.40 | 1.60 |
| PPTC + crystal | 2 × ($0.15+$0.30) | 0.90 |
| JST main board | 14 × $0.25 | 3.50 |
| 0603 passives | 100 × $0.01 | 1.00 |
| MOQ padding, main | — | 25.00 |
| USB-C, ESDs, JST SH, 0402 | — | 5.30 |
| PDM mic | 2 × $2.00 | 4.00 |
| MOQ padding, panel | — | 20.00 |
| Global-sourcing handling | ~12 parts × ≤$0.078 + baking | 9.00 |
| **Subtotal** | | **112.98** |
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

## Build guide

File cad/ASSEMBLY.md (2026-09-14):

# Full mechanical assembly

Build with `.venv/bin/python -m cad.assembly` (or `uv run cad-assembly`).
The source is `cad/assembly.py`, using `cad/enclosure.py` and the component
allocations in `hardware/pcb/design.py`. Outputs go to `output/full-assembly/`.
On macOS, follow the sandbox note in `AGENTS.md` if Python encounters UI errors.

This is a dimensioned assembly prototype. It includes the proposed main PCB,
radio and circuit-group allocations, daughterboards, mated connector envelopes,
29 insulated conductors, cell, contacts, thermistor, speaker, switches, caps,
gaskets, adhesive layers, straps and screws. It does not turn the unfinished
circuit into a routed or manufacturable PCB.

## Files

- `assembly.step`: named, colored parts with both enclosure halves.
- `open.step`: the same assembly with the cover and closure screws removed.
- `open.stl`, `internals.stl`: viewing meshes, rotated toward the preview camera.
  These contain multiple parts and are **not printable assembly files**.
- `chassis_print.stl`, `cover_print.stl`: enclosure halves in print orientation.
  Use this chassis: it includes the new cable passages, clips and speaker mounts.
- `USB_shoe_print.stl`, `PTT_carrier_print.stl`, `PWR_carrier_print.stl`,
  `speaker_bridge_print.stl`: separate mounting pieces.
- `PTT_TPU_cap_print.stl`, `PWR_TPU_cap_print.stl`: flexible button caps.
- `fit-report.json`: build status, collisions, nearby pairs, harness lengths,
  and explicitly bounded thread/termination contact exceptions.

Generate and inspect previews after building:

```bash
.venv/bin/python -m cad.preview output/full-assembly/open.stl
.venv/bin/python -m cad.preview output/full-assembly/internals.stl
.venv/bin/python -m cad.preview output/full-assembly/*_print.stl
.venv/bin/python -m cad.test_assembly
```

A complete build exits successfully and writes `status: PASS` after checking the
printable meshes. A failed or interrupted build can leave older exports beside
the report; do not interpret those files as a successful new build.

## Placement and mounting

| Part | Mount and mechanical constraint |
|---|---|
| Main PCB | Existing 26 × 126 × 1.6 mm slab and ten holes; six M2 × 5 screws. |
| Battery | Existing Ø18.6 × 65 mm cell position; two straps in new saddle grooves. Keystone 5201 spring and 5223 button contacts on the end carriers, 72.0 mm inside; a 1.9 mm collar around the positive plate stops a reversed cell 0.4 mm short of the button, provided the cell cap protrudes more than 0.4 mm (measure before printing). The sprung cell can sit up to 2.0 mm above the modelled envelope. |
| Speaker | Ø20 × 5.3 mm envelope (CMS-2053-18SP) and perimeter gasket; removable stepped bridge with two M2 × 5 screws driven along Z. The bridge clears the PCB edge. |
| Microphone | Custom **15 × 8 × 1.6 mm** board; IM69D130 aligned with X = 1, Z = 10 sound hole. The sideways SH connector sits beside the mic; perimeter tape seals and retains the board. |
| LEDs | Custom **12 × 8 × 1.6 mm** board with two 3 mm RGB LEDs and a 7-way SH header; emitters at the LED_POSITIONS_X values, Z = 140. SH socket on the inward face; perimeter tape retains the board. |
| USB-C | GCT USB4105 envelope facing X+, with a custom **13 × 6.6 × 1 mm** horizontal board with an 8-way SH header on its underside. Bond the board into the locating shoe and the shoe tabs to the chassis. Its rear stop carries insertion load. |
| PTT and power | Omron B3F-1000 envelopes in separate carriers bonded to the chassis rails. Trim and insulate terminals within the modeled envelope. Thin adhesive strips retain the switch. |
| Button caps | TPU diaphragm perimeter bonded to the outer frame/ring. The switch supplies return force; a carrier shoulder limits the center to 0.35 mm travel, including 0.10 mm free play. |
| Wiring | Individual swept insulation solids with rounded bends; passages through rails retain button/USB leads. The battery-negative lead lies in a ribbed channel on the inside of the front wall, notched through the saddle webs and top contact carrier. A chassis clip supports the NTC run. |

The mic and LED boards grew from the earlier empty-seat allocations to accommodate
the headers. Their acoustic/light axes are unchanged. The main-board connector
positions also differ from the earlier placement drawing: J_USB is at u = 7,
Z = 25; J_LED at u = −8, Z = 124; J_NTC at u = −7, Z = 103; J_PTT at u = 4.5,
Z = 110, with its plug exiting upward. The amplifier and J_SPK now have separate
envelopes. The 9.5 mm wide 7-way J_LED forced the radio module to u = 2.25, the
SWD pads to u = 10.25 and the amplifier envelope to u = −0.75. These changes are
explicit in the assembly source; the older placement image is not the complete
assembly layout.

The 72.0 mm inside length holds a 70.0 mm stack: the 65.0 mm cell, a 0.5 mm plate
and 3.0 mm coil at the negative end, and a 0.5 mm plate and 1.0 mm button at the
positive end. The spring pushes the cell up to 2.0 mm above the Z = 20…85 envelope
the fit report measures against, so the strap, saddle-groove and NTC clearances in
that report are nominal positions, not worst case.

## Field-unit variant

`.venv/bin/python -m cad.enclosure --variant field` and
`.venv/bin/python -m cad.assembly --variant field` write to `output/field-unit/`.
The main PCB, its connectors, the USB daughterboard, shoe and side opening, the
NTC and the radio module are replaced by a 25.4 × 135 mm stripboard
(`stripboard_template.step`: ten M2 holes, two 8 mm lead windows, and a notch
cut from the Y+ top corner where the board would otherwise overlap an existing
seam pin pad) carrying a flat-soldered XIAO nRF52840 Sense (Z 125.8…146.8,
USB-C through a 7.5 × 13 mm opening in the top wall at X 7.05) and a MAX98357A
breakout on one header row (Z 92…111.4). The microphone is an Adafruit 3492
breakout in a 14 × 12.8 mm seat. Six leads: MIC 4, PTT 2, SPK 2, LED 5, BAT+ 1,
BAT− 1. The PTT tunnel leaves only a 0.14 mm skin on the PCB rail's back face,
which will not print, so the lead lies in a groove open toward the wall with a
2.1 mm gap. Everything else is the product geometry. The power switch is
fitted but unwired.

## Dimensions and sources

The main PCB, cell and speaker sizes come from `hardware/pcb/DESIGN.md` and the
existing enclosure. The daughterboards and printed mounts are custom designs.

- [JST SH drawing](https://www.jst-mfg.com/product/pdf/eng/eSH.pdf): header geometry,
  mating arrangement and 0.4–0.8 mm wire insulation range. SH bodies use conservative
  envelopes with extra room for plugs; contacts are not individually modeled.
- [JST PH drawing](https://www.jst-mfg.com/product/pdf/eng/ePH.pdf): battery connector
  family; the existing placement allocates a 9 × 8 × 8 mm mated envelope.
- [GCT USB4105 drawing](https://gct.co/files/drawings/usb4105.pdf): receptacle envelope
  7.35 × 8.94 × 3.31 mm, rounded mouth and 1.85 mm minimum mating projection.
- [Omron B3F drawing](https://components.omron.com/sites/default/files/datasheet_pdf/A070-E1.pdf):
  B3F-1000 body, 4.3 mm overall actuator height and 0.25 mm travel. The 6.4 mm
  square body envelope includes the published width tolerance.
- Module, microphone and LED references remain in `hardware/pcb/DESIGN.md`.

| Adjustable parameter | Current value |
|---|---:|
| Signal-wire insulation diameter | 0.8 mm |
| Battery-wire insulation diameter | 1.4 mm |
| Signal / battery bend radius | 2 / 4 mm |
| Button free play / switch travel | 0.10 / 0.25 mm |
| PCB pilot diameter | 1.6 mm |
| Existing enclosure mating clearance | 0.30 mm diametral |
| Positive collar drop below button tip (`POSITIVE_COLLAR_DROP`) | 0.4 mm |
| Field-unit top-wall USB-C opening (`FIELD_TOP_USBC`) | centre X, centre Y, X size, Y size, corner radius |
| Field-unit stripboard lead windows (`FIELD_BOARD_WINDOWS`) | centre Z, Z size, each 8 mm wide |
| Field-unit mic board outline (`FIELD_MIC_BOARD`) | 14.0 × 12.8 mm, Adafruit 3492 |

Harness lengths in the report describe the modeled centerlines, not cut lengths.
Allow for contacts, terminations, strain relief and assembly slack when making
cables. The battery-negative route is deliberately longer to stay clear of the
cell, saddles and board. Speaker conductors represent the space for the pair;
individual helical twists are not modeled. Verify pin mapping from DESIGN.md,
not the rendering colors.

## Checks and practical limits

The generator uses OpenCASCADE solid validity, pairwise Boolean intersections,
and exact distances for nearby rigid parts. Wire-pair entries labeled **AABB lower
bound** are bounding-box distance bounds, not measured surface clearances; their
collision tests still use the actual solids. Overlaps are allowed only within
specific thread-engagement or wire-termination regions.

It checks the enclosure's original assembly assertions, cover withdrawal at
0.5, 2, 4, 10, 25 and 50 mm, and button-center motion through the intended stroke.
The cover check is sampled, not a continuous swept-volume proof. The TPU perimeter
stays fixed in the motion model; its deformation and force require a physical test.
Each printable export must be a connected, watertight mesh with consistent winding.
The small regression check deliberately introduces a collision and an invalid bend
to verify that the checker rejects them.

Print the rigid parts in PETG and the caps in TPU, using the supplied orientations.
Use a 0.4 mm nozzle and 0.2 mm layers as a starting point. Inspect local supports
under cable passages and internal mounts in the slicer. Install the speaker bridge
before the LED board to preserve screwdriver access, then fit the PCB, harnesses
and cell. Remove the cell for PCB screw access.

Confirm the purchased speaker, cell-contact/spring arrangement, insulation
sizes, connector tolerances, screw threads and adhesive before committing to
hardware. The contact envelopes are space reservations dimensioned from the
Keystone 5201 and 5223 drawings, not a validated spring holder or
reverse-insertion mechanism. Print and assemble a prototype to check tolerances,
USB insertion loads, strap tension, cap return and adhesive retention. The model
checks nominal geometry; it does not prove strength, RF clearance performance,
thermal behavior or electrical operation.

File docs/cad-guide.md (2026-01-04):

# CAD Design Guide

## Overview

The devais enclosure is designed using **CadQuery**, a Python-based parametric CAD system. This approach allows for programmatic design where dimensions and features can be easily adjusted through code parameters.

## Quick Start

```bash
# Install dependencies (first time only)
uv sync

# Generate the enclosure model
uv run python cad/enclosure.py

# Output files will be in cad/output/
# - enclosure.stl (Main body)
# - large_button.stl (The push-to-talk button)
```

## Design Parameters

All key dimensions are defined at the top of `cad/enclosure.py`:

### Enclosure Dimensions
- **Shape**: Octagonal Prism (Square with chamfered corners)
- `DEVICE_WIDTH`: 40.0mm (Flat-to-flat distance)
- `DEVICE_HEIGHT`: 150.0mm
- `WALL_THICKNESS`: 2.5mm
- `FILLET_RADIUS`: 4.0mm (Edges and corners)

### Component Positioning
Vertical positions (Z-axis) are measured from the bottom of the device:

- **Push-to-Talk Button**: Centered at 105.0mm (Right Side)
- **Power Button**: 25.0mm (Right Side)
- **USB-C Port**: 12.0mm (Right Side)
- **Microphone**: 10.0mm (Front Side)
- **Speaker**: Upper Front (approx. 120-130mm, relative to LEDs)
- **LEDs**: 140.0mm (Front Side, 10mm from top)

### Component Dimensions
- **Large Button**: 24.9mm width × 45mm height
- **Speaker**: ~20mm diameter (80% of long side width)
- **Power Button**: 8mm diameter
- **USB-C**: 9.5mm × 3.7mm

## Coordinate System

The design uses the following coordinate system:
- **Z-axis**: Vertical height (0 to 150mm)
- **XY-plane**: The octagonal cross-section
- **Front Face**: +Y direction
- **Right Face**: +X direction

## Modifying the Design

### Changing Dimensions

1. Open `cad/enclosure.py`
2. Modify parameters at the top of the file
3. Run `uv run python cad/enclosure.py` to regenerate

Example - moving the large button:
```python
LARGE_BTN_CENTER_FROM_BOTTOM = 110.0  # Changed from 105.0
```

### Adding New Features

The script is organized into modular functions:

- `create_octagonal_prism()` - Base geometry
- `add_large_button_feature()` - Opening and frame for main button
- `add_power_button()` - Power button cutout
- `add_usbc_port()` - USB-C port cutout
- `add_speaker_grille()` - Perforated speaker holes
- `add_mic_hole_and_mount()` - Mic hole and internal pocket
- `add_led_holes()` - Status LED openings

To add a new feature, create a similar function and call it in `build_enclosure()`.

## Design Considerations

### 3D Printing
- **Orientation**: Print vertically (standing on its bottom face).
- **Supports**: The octagonal shape and 45° chamfers are self-supporting. The large button frame and internal pockets may require minimal supports depending on the printer.
- **Tolerances**: 
    - `PRINT_TOLERANCE` and `PRESS_FIT_TOLERANCE` should be considered for mating parts.
    - The large button opening includes clearance for the button movement.

### Ergonomics  
- The 40mm octagonal shape ("square stick with chamfered corners") provides a comfortable grip.
- The large, textured orange button is positioned for easy thumb activation.
- Rounded edges (4mm fillet) ensure no sharp corners.

## Working with AI Assistants

This parametric design is ideal for AI-assisted iteration. You can ask for changes like:

> "Move the USB-C port 2mm higher"
> "Increase the large button height to 50mm"
> "Add a lanyard hole on the bottom left side"

The assistant can read the current `enclosure.py`, understand the parameter names, and apply the specific changes safely.

## Export Formats

### STL (`.stl`)
- Standard 3D printing format.
- Output includes `enclosure.stl` and `large_button.stl` as separate files for printing.

## Troubleshooting

**Issue**: Model looks wrong in viewer
- Ensure you are viewing in Millimeters.
- Check if the octagonal profile is generated correctly (8 points).

**Issue**: Python errors
- Ensure dependencies are installed: `uv sync`
- Check CadQuery version compatibility if moving between environments.

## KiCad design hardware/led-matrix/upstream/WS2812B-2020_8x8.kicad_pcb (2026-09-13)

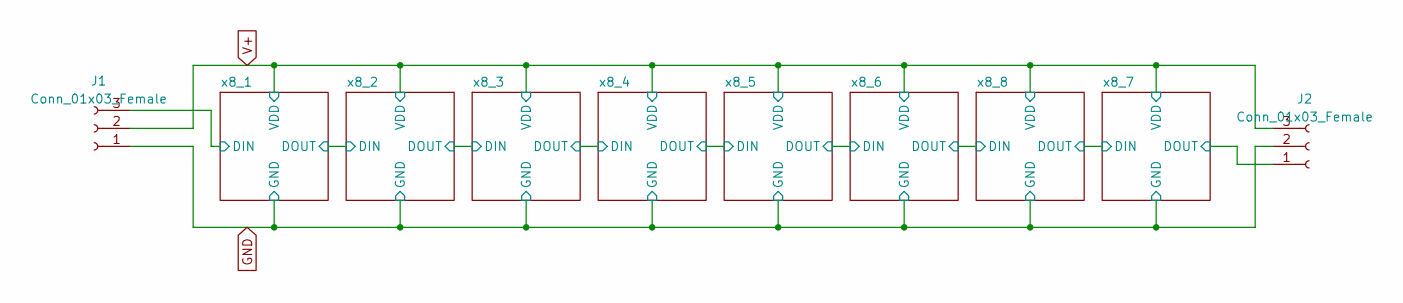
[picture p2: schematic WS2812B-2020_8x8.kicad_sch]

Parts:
J1, J2: Conn_01x03_Female; DS1024-1x3R0 01x03

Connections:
/x8_1/DIN: J1.3; also elsewhere on the board
/x8_7/DOUT: J2.1; also elsewhere on the board
GND: J1.1, J2.2; also elsewhere on the board
V+: J1.2, J2.3; also elsewhere on the board

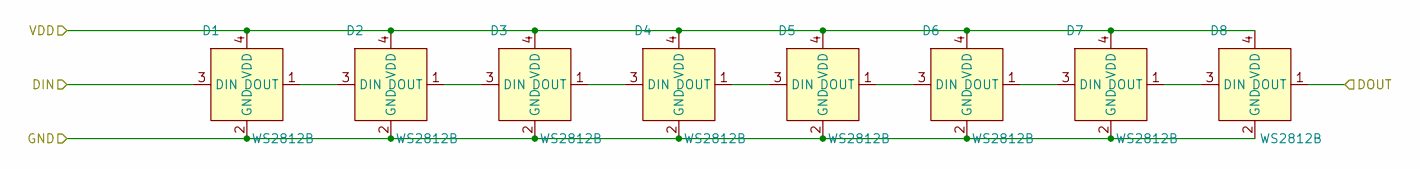
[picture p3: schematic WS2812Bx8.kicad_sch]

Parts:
D1, D2, D3, D4, D5, D6, D7, D8: WS2812B; WS2812B2020

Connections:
/x8_1/DIN: D1.3 (DIN); also elsewhere on the board
/x8_1/DOUT: D8.1 (DOUT); also elsewhere on the board
GND: D1.2 (GND), D2.2 (GND), D3.2 (GND), D4.2 (GND), D5.2 (GND), D6.2 (GND), D7.2 (GND), D8.2 (GND); also elsewhere on the board
unnamed: D1.1 (DOUT), D2.3 (DIN)
unnamed: D2.1 (DOUT), D3.3 (DIN)
unnamed: D3.1 (DOUT), D4.3 (DIN)
unnamed: D4.1 (DOUT), D5.3 (DIN)
unnamed: D5.1 (DOUT), D6.3 (DIN)
unnamed: D6.1 (DOUT), D7.3 (DIN)
unnamed: D7.1 (DOUT), D8.3 (DIN)
V+: D1.4 (VDD), D2.4 (VDD), D3.4 (VDD), D4.4 (VDD), D5.4 (VDD), D6.4 (VDD), D7.4 (VDD), D8.4 (VDD); also elsewhere on the board

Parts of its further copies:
D9, D10, D11, D12, D13, D14, D15, D16, D17, D18, D19, D20, D21, D22, D23, D24, D25, D26, D27, D28, D29, D30, D31, D32, D33, D34, D35, D36, D37, D38, D39, D40, D41, D42, D43, D44, D45, D46, D47, D48, D49, D50, D51, D52, D53, D54, D55, D56, D57, D58, D59, D60, D61, D62, D63, D64: WS2812B; WS2812B2020

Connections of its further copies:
/x8_1/DOUT: D9.3 (DIN); also elsewhere on the board
/x8_2/DOUT: D16.1 (DOUT), D17.3 (DIN)
/x8_3/DOUT: D24.1 (DOUT), D25.3 (DIN)
/x8_4/DOUT: D32.1 (DOUT), D33.3 (DIN)
/x8_5/DOUT: D40.1 (DOUT), D41.3 (DIN)
/x8_6/DOUT: D48.1 (DOUT), D49.3 (DIN)
/x8_7/DIN: D56.1 (DOUT), D57.3 (DIN)
/x8_7/DOUT: D64.1 (DOUT); also elsewhere on the board
GND: D9.2 (GND), D10.2 (GND), D11.2 (GND), D12.2 (GND), D13.2 (GND), D14.2 (GND), D15.2 (GND), D16.2 (GND), D17.2 (GND), D18.2 (GND), D19.2 (GND), D20.2 (GND), D21.2 (GND), D22.2 (GND), D23.2 (GND), D24.2 (GND), D25.2 (GND), D26.2 (GND), D27.2 (GND), D28.2 (GND), D29.2 (GND), D30.2 (GND), D31.2 (GND), D32.2 (GND), D33.2 (GND), D34.2 (GND), D35.2 (GND), D36.2 (GND), D37.2 (GND), D38.2 (GND), D39.2 (GND), D40.2 (GND), D41.2 (GND), D42.2 (GND), D43.2 (GND), D44.2 (GND), D45.2 (GND), D46.2 (GND), D47.2 (GND), D48.2 (GND), D49.2 (GND), D50.2 (GND), D51.2 (GND), D52.2 (GND), D53.2 (GND), D54.2 (GND), D55.2 (GND), D56.2 (GND), D57.2 (GND), D58.2 (GND), D59.2 (GND), D60.2 (GND), D61.2 (GND), D62.2 (GND), D63.2 (GND), D64.2 (GND); also elsewhere on the board
unnamed: D9.1 (DOUT), D10.3 (DIN)
unnamed: D10.1 (DOUT), D11.3 (DIN)
unnamed: D11.1 (DOUT), D12.3 (DIN)
unnamed: D12.1 (DOUT), D13.3 (DIN)
unnamed: D13.1 (DOUT), D14.3 (DIN)
unnamed: D14.1 (DOUT), D15.3 (DIN)
unnamed: D15.1 (DOUT), D16.3 (DIN)
unnamed: D17.1 (DOUT), D18.3 (DIN)
unnamed: D18.1 (DOUT), D19.3 (DIN)
unnamed: D19.1 (DOUT), D20.3 (DIN)
unnamed: D20.1 (DOUT), D21.3 (DIN)
unnamed: D21.1 (DOUT), D22.3 (DIN)
unnamed: D22.1 (DOUT), D23.3 (DIN)
unnamed: D23.1 (DOUT), D24.3 (DIN)
unnamed: D25.1 (DOUT), D26.3 (DIN)
unnamed: D26.1 (DOUT), D27.3 (DIN)
unnamed: D27.1 (DOUT), D28.3 (DIN)
unnamed: D28.1 (DOUT), D29.3 (DIN)
unnamed: D29.1 (DOUT), D30.3 (DIN)
unnamed: D30.1 (DOUT), D31.3 (DIN)
unnamed: D31.1 (DOUT), D32.3 (DIN)
unnamed: D33.1 (DOUT), D34.3 (DIN)
unnamed: D34.1 (DOUT), D35.3 (DIN)
unnamed: D35.1 (DOUT), D36.3 (DIN)
unnamed: D36.1 (DOUT), D37.3 (DIN)
unnamed: D37.1 (DOUT), D38.3 (DIN)
unnamed: D38.1 (DOUT), D39.3 (DIN)
unnamed: D39.1 (DOUT), D40.3 (DIN)
unnamed: D41.1 (DOUT), D42.3 (DIN)
unnamed: D42.1 (DOUT), D43.3 (DIN)
unnamed: D43.1 (DOUT), D44.3 (DIN)
unnamed: D44.1 (DOUT), D45.3 (DIN)
unnamed: D45.1 (DOUT), D46.3 (DIN)
unnamed: D46.1 (DOUT), D47.3 (DIN)
unnamed: D47.1 (DOUT), D48.3 (DIN)
unnamed: D49.1 (DOUT), D50.3 (DIN)
unnamed: D50.1 (DOUT), D51.3 (DIN)
unnamed: D51.1 (DOUT), D52.3 (DIN)
unnamed: D52.1 (DOUT), D53.3 (DIN)
unnamed: D53.1 (DOUT), D54.3 (DIN)
unnamed: D54.1 (DOUT), D55.3 (DIN)
unnamed: D55.1 (DOUT), D56.3 (DIN)
unnamed: D57.1 (DOUT), D58.3 (DIN)
unnamed: D58.1 (DOUT), D59.3 (DIN)
unnamed: D59.1 (DOUT), D60.3 (DIN)
unnamed: D60.1 (DOUT), D61.3 (DIN)
unnamed: D61.1 (DOUT), D62.3 (DIN)
unnamed: D62.1 (DOUT), D63.3 (DIN)
unnamed: D63.1 (DOUT), D64.3 (DIN)
V+: D9.4 (VDD), D10.4 (VDD), D11.4 (VDD), D12.4 (VDD), D13.4 (VDD), D14.4 (VDD), D15.4 (VDD), D16.4 (VDD), D17.4 (VDD), D18.4 (VDD), D19.4 (VDD), D20.4 (VDD), D21.4 (VDD), D22.4 (VDD), D23.4 (VDD), D24.4 (VDD), D25.4 (VDD), D26.4 (VDD), D27.4 (VDD), D28.4 (VDD), D29.4 (VDD), D30.4 (VDD), D31.4 (VDD), D32.4 (VDD), D33.4 (VDD), D34.4 (VDD), D35.4 (VDD), D36.4 (VDD), D37.4 (VDD), D38.4 (VDD), D39.4 (VDD), D40.4 (VDD), D41.4 (VDD), D42.4 (VDD), D43.4 (VDD), D44.4 (VDD), D45.4 (VDD), D46.4 (VDD), D47.4 (VDD), D48.4 (VDD), D49.4 (VDD), D50.4 (VDD), D51.4 (VDD), D52.4 (VDD), D53.4 (VDD), D54.4 (VDD), D55.4 (VDD), D56.4 (VDD), D57.4 (VDD), D58.4 (VDD), D59.4 (VDD), D60.4 (VDD), D61.4 (VDD), D62.4 (VDD), D63.4 (VDD), D64.4 (VDD); also elsewhere on the board

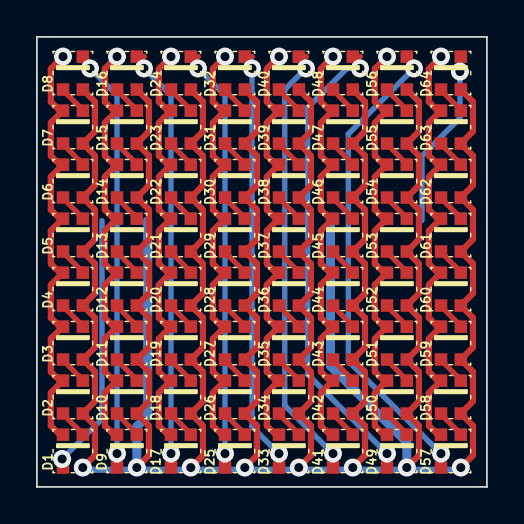
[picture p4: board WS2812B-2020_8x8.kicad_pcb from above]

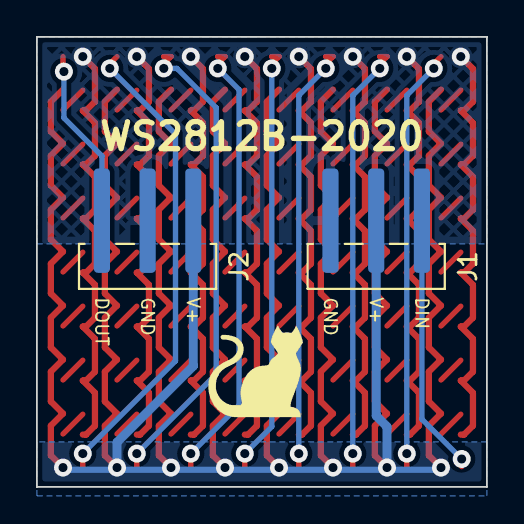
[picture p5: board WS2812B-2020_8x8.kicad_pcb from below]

Board: 2 copper layers, 25.0 x 25.0 mm, 66 parts (2 on the bottom side), 67 nets.

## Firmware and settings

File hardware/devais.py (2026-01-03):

"""
Devais - Handheld AI Assistant Device
Main circuit composition

This brings together all subsystems:
- Power management (USB-C, battery, 3.3V regulation)
- Audio (I2S microphone and amplifier)
- User interface (buttons and LEDs)
- nRF52840 microcontroller

Based on component selections from:
- Seeed XIAO nRF52840
- INMP441 I2S microphone
- MAX98357A I2S amplifier
- 18650 Li-ion battery
"""

from circuit_synth import Component, Net, circuit

from power_management import power_system
from audio import audio_system
from user_interface import user_interface


@circuit(name="nRF52840_Controller")
def nrf52840_controller(
    vcc_3v3,
    # I2S bus
    i2s_sck,
    i2s_ws,
    i2s_sd_in,
    i2s_sd_out,
    # User interface
    btn_ptt,
    btn_power,
    led_power,
    led_ble,
    led_activity,
    # Programming/debug
    swdio,
    swclk,
    reset,
    gnd
):
    """
    Seeed XIAO nRF52840 microcontroller module

    Note: The XIAO nRF52840 is a complete module with:
    - nRF52840 MCU
    - USB-C connector (for programming/debug)
    - Reset button
    - Voltage regulator
    - Battery charging circuit

    For the production design, we're treating it as a module.
    In the future, this could be replaced with discrete nRF52840 chip.

    Args:
        vcc_3v3: 3.3V power input
        i2s_*: I2S audio bus signals
        btn_*: Button GPIO inputs
        led_*: LED GPIO outputs
        swdio, swclk: SWD programming interface
        reset: Reset pin
        gnd: Ground
    """
    # XIAO nRF52840 module
    mcu = Component(
        symbol="MCU:Seeed_XIAO_nRF52840",
        ref="U",
        footprint="Module:Seeed_XIAO_nRF52840"
    )

    # Power
    mcu["3V3"] += vcc_3v3
    mcu["GND"] += gnd

    # I2S audio bus (using nRF52840 I2S peripheral)
    # Pin assignments based on typical I2S configuration
    mcu["P0.26"] += i2s_sck  # I2S SCK
    mcu["P0.27"] += i2s_ws  # I2S WS (LRCK)
    mcu["P0.28"] += i2s_sd_in  # I2S SDI (mic data in)
    mcu["P0.29"] += i2s_sd_out  # I2S SDO (amp data out)

    # User interface
    mcu["P0.02"] += btn_ptt  # Push-to-talk button (interrupt capable)
    mcu["P0.03"] += btn_power  # Power/mode button (interrupt capable)

    mcu["P0.06"] += led_power  # Power status LED
    mcu["P0.07"] += led_ble  # BLE connection LED
    mcu["P0.08"] += led_activity  # Activity indicator LED

    # SWD programming interface
    mcu["SWDIO"] += swdio
    mcu["SWCLK"] += swclk
    mcu["RESET"] += reset

    # SWD header for programming/debugging
    swd_header = Component(
        symbol="Connector:Conn_ARM_JTAG_SWD_10",
        ref="J",
        footprint="Connector_PinHeader_1.27mm:PinHeader_2x05_P1.27mm_Vertical"
    )

    swd_header["VCC"] += vcc_3v3
    swd_header["SWDIO"] += swdio
    swd_header["SWCLK"] += swclk
    swd_header["RESET"] += reset
    swd_header["GND"] += gnd

    # Pull-up on reset line
    reset_pullup = Component(
        symbol="Device:R",
        ref="R",
        value="10k",
        footprint="Resistor_SMD:R_0603_1608Metric"
    )
    reset_pullup[1] += vcc_3v3
    reset_pullup[2] += reset

    # Decoupling capacitors for MCU
    cap_mcu_1 = Component(
        symbol="Device:C",
        ref="C",
        value="10uF",
        footprint="Capacitor_SMD:C_0805_2012Metric"
    )
    cap_mcu_1[1] += vcc_3v3
    cap_mcu_1[2] += gnd

    cap_mcu_2 = Component(
        symbol="Device:C",
        ref="C",
        value="100nF",
        footprint="Capacitor_SMD:C_0603_1608Metric"
    )
    cap_mcu_2[1] += vcc_3v3
    cap_mcu_2[2] += gnd


@circuit(name="Devais")
def devais_main():
    """
    Main Devais circuit

    Complete handheld AI assistant device with:
    - Power management (USB-C charging, 18650 battery, 3.3V regulation)
    - Audio system (I2S microphone and amplifier with shared clock)
    - User interface (push-to-talk, power button, status LEDs)
    - nRF52840 BLE microcontroller
    """
    # Global nets
    gnd = Net('GND')
    vcc_3v3 = Net('VCC_3V3')

    # I2S audio bus nets
    i2s_sck = Net('I2S_SCK')
    i2s_ws = Net('I2S_WS')
    i2s_sd_in = Net('I2S_SDI')  # Mic to MCU
    i2s_sd_out = Net('I2S_SDO')  # MCU to Amp

    # User interface nets
    btn_ptt = Net('BTN_PTT')
    btn_power = Net('BTN_PWR')
    led_power = Net('LED_PWR')
    led_ble = Net('LED_BLE')
    led_activity = Net('LED_ACT')

    # Programming interface nets
    swdio = Net('SWDIO')
    swclk = Net('SWCLK')
    reset = Net('RESET')

    # Subsystems
    power_system(vcc_3v3, gnd)

    audio_system(vcc_3v3, i2s_sck, i2s_ws, i2s_sd_in, i2s_sd_out, gnd)

    user_interface(
        vcc_3v3,
        btn_ptt,
        btn_power,
        led_power,
        led_ble,
        led_activity,
        gnd
    )

    nrf52840_controller(
        vcc_3v3,
        i2s_sck,
        i2s_ws,
        i2s_sd_in,
        i2s_sd_out,
        btn_ptt,
        btn_power,
        led_power,
        led_ble,
        led_activity,
        swdio,
        swclk,
        reset,
        gnd
    )


if __name__ == "__main__":
    # Generate KiCad project
    circuit = devais_main()

    print("Generating Devais KiCad project...")

    # Generate schematic and PCB
    circuit.generate_kicad_project(
        "devais_v1",
        force_regenerate=False  # Preserve manual changes to KiCad files
    )

    print("✓ KiCad project generated: devais_v1/")
    print("  - devais_v1.kicad_pro")
    print("  - devais_v1.kicad_sch")
    print("  - devais_v1.kicad_pcb")
    print()
    print("Next steps:")
    print("1. Open in KiCad: open devais_v1/devais_v1.kicad_pro")
    print("2. Assign footprints (if needed)")
    print("3. Layout PCB components")
    print("4. Route traces")
    print("5. Generate Gerbers: circuit.generate_gerbers('devais_v1')")

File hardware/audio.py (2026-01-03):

"""
I2S Audio Subsystem for Devais
- INMP441 MEMS I2S microphone
- MAX98357A Class D I2S amplifier
- Shared I2S clock signals (efficient architecture)
"""

from circuit_synth import Component, Net, circuit


@circuit(name="I2S_Microphone")
def i2s_microphone(vcc, sck, ws, sd, gnd):
    """
    INMP441 MEMS I2S microphone

    Args:
        vcc: 3.3V power
        sck: I2S bit clock (shared with amplifier)
        ws: I2S word select / LR clock (shared with amplifier)
        sd: Serial data output from microphone
        gnd: Ground
    """
    mic = Component(
        symbol="Audio:INMP441",
        ref="MIC",
        footprint="Audio:INMP441_Breakout"
    )

    mic["VDD"] += vcc
    mic["SCK"] += sck
    mic["WS"] += ws
    mic["SD"] += sd
    mic["GND"] += gnd

    # L/R selection (GND = left channel)
    mic["L/R"] += gnd

    # Decoupling capacitor for microphone
    cap_mic = Component(
        symbol="Device:C",
        ref="C",
        value="100nF",
        footprint="Capacitor_SMD:C_0603_1608Metric"
    )
    cap_mic[1] += vcc
    cap_mic[2] += gnd


@circuit(name="I2S_Amplifier")
def i2s_amplifier(vcc, sck, ws, sd, spk_p, spk_n, gnd):
    """
    MAX98357A Class D I2S amplifier

    Args:
        vcc: 3.3V power
        sck: I2S bit clock (shared with microphone)
        ws: I2S word select / LR clock (shared with microphone)
        sd: Serial data input to amplifier
        spk_p: Speaker positive output
        spk_n: Speaker negative output
        gnd: Ground
    """
    amp = Component(
        symbol="Audio:MAX98357A",
        ref="U",
        footprint="Audio:MAX98357A_Breakout"
    )

    amp["VIN"] += vcc
    amp["BCLK"] += sck
    amp["LRC"] += ws
    amp["DIN"] += sd
    amp["GND"] += gnd
    amp["OUT+"] += spk_p
    amp["OUT-"] += spk_n

    # SD_MODE tied to VCC for I2S mode
    amp["SD"] += vcc

    # GAIN setting (GND = 9dB, VCC = 15dB, floating = 12dB)
    # Using 9dB for battery efficiency
    amp["GAIN"] += gnd

    # Decoupling capacitors
    cap_amp_bulk = Component(
        symbol="Device:C",
        ref="C",
        value="10uF",
        footprint="Capacitor_SMD:C_0805_2012Metric"
    )
    cap_amp_bulk[1] += vcc
    cap_amp_bulk[2] += gnd

    cap_amp_decouple = Component(
        symbol="Device:C",
        ref="C",
        value="100nF",
        footprint="Capacitor_SMD:C_0603_1608Metric"
    )
    cap_amp_decouple[1] += vcc
    cap_amp_decouple[2] += gnd


@circuit(name="Speaker")
def speaker_output(spk_p, spk_n):
    """
    Speaker connection

    Args:
        spk_p: Speaker positive terminal
        spk_n: Speaker negative terminal
    """
    speaker = Component(
        symbol="Device:Speaker",
        ref="LS",
        footprint="Audio:Speaker_Round_28mm"
    )

    speaker["+"] += spk_p
    speaker["-"] += spk_n


@circuit(name="Audio_System")
def audio_system(vcc_3v3, i2s_sck, i2s_ws, i2s_sd_in, i2s_sd_out, gnd):
    """
    Complete I2S audio system with shared clock architecture

    This implements the efficient I2S bus design:
    - SCK and WS are shared between microphone and amplifier
    - SD_IN carries mic data to nRF52840
    - SD_OUT carries audio data from nRF52840 to amplifier

    Args:
        vcc_3v3: 3.3V power supply
        i2s_sck: I2S bit clock (to/from nRF52840)
        i2s_ws: I2S word select (to/from nRF52840)
        i2s_sd_in: Mic serial data (to nRF52840)
        i2s_sd_out: Amp serial data (from nRF52840)
        gnd: Ground
    """
    # Speaker nets
    spk_p = Net('SPK+')
    spk_n = Net('SPK-')

    # Microphone with shared clock signals
    i2s_microphone(vcc_3v3, i2s_sck, i2s_ws, i2s_sd_in, gnd)

    # Amplifier with shared clock signals
    i2s_amplifier(vcc_3v3, i2s_sck, i2s_ws, i2s_sd_out, spk_p, spk_n, gnd)

    # Speaker
    speaker_output(spk_p, spk_n)

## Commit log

2026-01-03 WiP enclosure + button
    [Devais_Simplified.kicad_sch]
2026-01-04 Tweaks to help Gemini one-shot the cad/enclosure.py script
2026-01-04 Move gemini_cad_skill.md to context/, update docs/cad-guide.md
2026-01-04 Add CI workflow for STL viewers
2026-01-18 Reorganize CAD skill directory and update documentation
    - Rename cad-modeller-skill/ to cad-modeller/ for consistency
    - Add context/README.md index for AI agent context files
    - Update AGENTS.md to reference new skill location
    - Update context/enclosure-work.md with complete implementation status
    - Remove deprecated context/gemini_cad_skill.md
2026-04-06 Add snap-fit enclosure redesign spec
    Replace front/back split + threaded lid with left/right snap-fit
    halves. All electronics on chassis half, cover is purely mechanical.
2026-04-06 Add snap-fit enclosure redesign implementation plan
2026-04-06 Remove threaded bottom lid machinery from enclosure
2026-04-06 Close bottom, update LEDs to 2x RGB, shift mic +1mm
    - Hollow starts at WALL_THICKNESS for solid bottom wall
    - 2 WS2812B-2020 LED holes at x=5,11mm (was 3 LEDs centered)
    - Mic hole shifted to x=+1mm for chassis-side placement
2026-04-06 Add battery cradle ribs for 18650 on chassis half
2026-04-06 Rewrite split to X=0 with snap-fit on front/back walls
    Rename halves from front/back to right/left. Move tongue-and-groove
    rails and snap clips from left/right walls to front/back walls. Update
    exported STL filenames to enclosure_right.stl and enclosure_left.stl.
2026-04-06 Update enclosure spec for snap-fit redesign
2026-04-06 PCB generator
2026-04-06 Use tscircuit, redesign PCB, split enclosure across speaker/mic
    [Devais_Simplified.kicad_sch]
2026-04-06 PCB broadened to 36mm
2026-04-07 Added PCB mounting holes
2026-09-13 Astra enclosure fixes, round 1
2026-09-13 Astra enclosure fixes, round 2
    Ensure that various attachments like the USB charging port,
    the button, mic, speaker and LEDs can be mounted (screw holes,
    brackets, etc), and that they do not physically conflict.
2026-09-13 Add research notes and PCB found for 8x8 LED matrix
    [WS2812B-2020_8x8-B_Cu.gbr, WS2812B-2020_8x8-B_Mask.gbr, WS2812B-2020_8x8-B_Paste.gbr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]
2026-09-13 Move LEDs clear of chamfer, rebuild Pages site, fix PCB build
    LED holes move from X=5/11 to X=0/6 so the right hole no longer runs
    into the front-face chamfer. The daughterboard seat, SH socket and
    harness end follow.
    The GitHub Pages site now lists every printable part from the full
    assembly build with a browser-rendered thumbnail, a shared viewer
    page and STL download. The deploy workflow runs cad-generate and
    cad-assembly instead of the removed enclosure exports.
    pcb_build.py runs the local tsci binary from node_modules, and the
    workflow installs PCB dependencies with bun from bun.lock. npm ignored
    the lockfile and resolved a broken dependency set, and the global
    @tscircuit/cli package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
    [pcb_build.py]
2026-09-13 Replace cantilevered wire clips with a front-wall channel (#1)
    The battery-negative lead was held by two 19 mm arms of 2 x 2 mm section
    reaching across the cavity from the chassis wall. They are fragile and
    print as unsupported overhangs. The lead now runs in a ribbed channel on
    the inside of the front wall, notched through the saddle webs and the top
    contact carrier, and terminates on the front edge of the negative contact.
2026-09-14 Restore chamfered, dot-textured face on the PTT button
    The push-to-talk cap lost its look when it moved from
    enclosure.create_large_button() to the TPU diaphragm cap in
    cad/assembly.py: the cap was two flat rounded plates, with no
    chamfer and no texture.
    Add a crown on the cap's outer face: a 27 x 47 mm rounded rect
    (r9) tapered 45 degrees over 2.0 mm to a 23 x 43 top, carrying
    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
2026-09-14 Electrical design rev 2, parts list, prototype plan and enclosure updates
    - DESIGN.md rev 2: nRF52840 high-voltage mode, BQ24074 power path, DW01A
    protection, MAX98357A, T3902 PDM mic, USB 2.0 data over an 8-way harness,
    plain 3 mm RGB LEDs, hand-assembly rules
    - BOM.md: verified part codes, ready-made JST SR harnesses, tools, 10-set costs
    - PROTOTYPE.md: stripboard bench build and field unit on the XIAO nRF52840 Sense
    - CAD: CMS-2053 speaker cup and one-piece bridge, 12x8 LED board with 3.2 mm
    holes, 8-way USB header and bundle, Keystone 5201/5223 contacts with a
    reverse-insertion collar, 1.4 mm battery leads
    - CAD: --variant field builds the XIAO/stripboard field unit in the produc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
2026-09-14 Record software stack decisions D1-D4
    Resolves the open firmware and host-platform questions left in
    hardware/PROTOTYPE.md and the software gap in the 2026-09-10 review.
    - D1 firmware framework: nRF Connect SDK (Zephyr), not the Seeed Arduino
    core, since the custom board needs its own board definition either way.
    - D2 host platform: Android.
    - D3 BLE transport and codec, staged: NUS with raw PCM for the bench
    prototype, then a purpose-built GATT service with IMA ADPCM for the
    product. Records why L2CAP CoC and Opus were rejected, and the
    throughput constraints behind the choice.
    - D4 prototype microphone: M2, the PDM breakout at the product mic
    position, so the prototype tests rea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
